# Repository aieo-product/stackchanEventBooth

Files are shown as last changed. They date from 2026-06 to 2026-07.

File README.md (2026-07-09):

# stackchanEventBooth

**AI Dev Day 2026（2026年7月24日・大手町プレイスホール＆カンファレンス）** のスタックチャンブース企画・運営リポジトリ。

イベントを盛り上げるための **スタックチャン用アクセサリー** と **簡易撮影ブース** を制作し、来場者に「スタックチャンを着せ替えて撮って楽しむ」体験を提供します。

📄 **公開提案サイト（Cloudflare Pages）: https://stackchan-event-booth.pages.dev/**
🎤 LTスライド（リッチHTML）: https://stackchan-event-booth.pages.dev/slides/lt.html

## このリポジトリの目的

- ブース企画（アクセサリー／撮影ブース／必要スペース）の管理
- アクセサリー造形例の調査と、各制作者への **許諾取得状況** の管理
- 関係者向け公開提案サイト（Cloudflare Pages）のソース管理

## ブース概要（想定）

| 項目 | 内容 |
|---|---|
| イベント | AI Dev Day 2026 |
| 日時 | 2026年7月24日（金）|
| ブース運営時間 | **13:00–17:00**（4時間想定）|
| 会場 | 大手町プレイスホール＆カンファレンス（東京・大手町）|
| 体験 | スタックチャンの着せ替えアクセサリー展示＋記念撮影ブース |

## ディレクトリ構成

| パス | 内容 |
|---|---|
| `baseIdea/` | 元ネタ画像（スタックチャンお誕生日会で見たアクセサリー・撮影ブース例）|
| `research/` | X調査結果（アクセサリー造形例・制作者アカウント・許諾管理）|
| `docs/` | 関係者シェア用 提案サイト（VitePress / Cloudflare Pages）|

## 関連リンク

- 📄 公開提案サイト（Cloudflare Pages）: https://stackchan-event-booth.pages.dev/
- 🎤 LTスライド（リッチHTML）: https://stackchan-event-booth.pages.dev/slides/lt.html
- AI Dev Day 2026: https://aidevday.com/
- ハッシュタグ: `#ｽﾀｯｸﾁｬﾝお誕生日2026`

## アクセサリーの取り扱い方針

本ブースで展示・配布・印刷するアクセサリーは **既存造形のコピーではなく、各制作者に許諾を得たうえで設置** します。調査した造形例と制作者アカウントは [`research/accessories.md`](research/accessories.md) で管理し、許諾ステータスを記録します。

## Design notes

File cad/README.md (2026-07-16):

# CAD (OpenSCAD) — 卓上観覧車 & 撮影ブース

Issue #16/#18/#19 の3Dプリントパーツをパラメトリックに定義したOpenSCADソースです。
寸法・公差は [`params.scad`](params.scad) に一元化しています。設計根拠は
[`docs/ferris-wheel.md`](../docs/ferris-wheel.md) / [`docs/photobooth.md`](../docs/photobooth.md)。

## 生成方法

```bash
cd cad
make all      # 全STLを ../print/files/{ferris,booth,mini}/ に生成
make check    # 生成 + BBox寸法チェック + 接地(最下面z=0)チェック (python3, 標準ライブラリのみ)
make clean    # 生成STLを削除
```

STL は `print/files/` 配下（`.gitignore` 管理外）に出力されます。**ソースが正**で、
STL はコミットしません。`openscad` CLI が必要です（`/opt/homebrew/bin/openscad`, v2026 で検証）。

## パラメータ変更 → 再生成

1. [`params.scad`](params.scad) の該当変数を編集（例: 印刷公差 `tol`、ダブテール
   クリアランス `tol_dovetail`、LED溝幅 `led_groove_w` など）。
2. `make clean && make all` で全パーツを再生成（`make check` で寸法再確認）。
3. テスト印刷（7/15〜）のはめ合いフィードバックは、まず `tol` / `tol_dovetail` /
   `tol_snap` の3変数で調整します（初版は安全側=緩めに設定済み）。

`tower.scad`（`part="upper"|"lower"`）と `wall_panel.scad`
（`variant="blackboard"|"window"|"board"`）は `-D` で切り替え、Makefile が各STLに展開します。

## パーツ一覧

| STL | ソース | 実測BBox (X×Y×Z mm) | 主要寸法 / 備考 |
|---|---|---|---|
| ferris/rim-segment | `ferris/rim_segment.scad` | 158×150×20 | 1/4円弧・Ø300・スポーク2本一体・外周LED溝10.5×2.0・端部ダブテール＋接線M3ボス（X の +8 はテノン） |
| ferris/diffuser | `ferris/diffuser.scad` | 152×152×23.2 | リム外周に被せるコの字スナップカバー・1/4円弧（半透明フィラメント推奨） |
| ferris/hub | `ferris/hub.scad` | 80×80×25 | Ø80×25・シャフト穴Ø8.2貫通・スポークボルト穴8・M3イモネジ用インサート横穴2 |
| ferris/gondola | `ferris/gondola.scad` | 68×72×77 | **チェア型オープンゴンドラ(#18再設計)**。座面2段ネスト凹み(外62×62×1.5=汎用/ゲルテープ・内48.6×56.6×2.0=K151ベース48×56嵌合)・左右ハンガーポスト・背もたれ低壁25・前面Dセーフティバー・上部ブリッジのU溝で吊り軸を掴む(振り子安定)。前面開放でスクリーン可視・サポートレス |
| ferris/tower-upper | `ferris/tower.scad -D part="upper"` | 86.6×30×145 | A型上半・608ポケットØ22.2×7.2＋抜け止めリップ・スプライスソケット |
| ferris/tower-lower | `ferris/tower.scad -D part="lower"` | 122×30×168 | A型下半・ベース差込タブ＋M3蝶ネジ穴・角ダボ(male)＋M3×2 |
| ferris/base | `ferris/base.scad` | 250×183×45 | 250×175×15・長辺に自己相補ダブテール（同一部品を180°回転で連結）・支柱スロット2・M3蝶ネジ・クランク軸受Ø8.5 |
| ferris/crank | `ferris/crank.scad` | 152.5×25.5×44 | クランク本体(Ø8.2＋M3イモネジ)＋自由回転グリップØ20×40(Eリング溝)＋フリクションダンパーC形クリップ（1プレート） |
| ferris/axle | `ferris/axle.scad` | 90×40×139 | **Φ6印刷吊り軸(#20)**。一体フランジ頭Ø10×3＋Φ6シャフト、押込キャップØ10×6(内穴Φ5.8=0.2締め代)。金属棒不要(カット機材不要)。1プレートに軸5本＋キャップ6個(予備込) |
| booth/floor-tile | `booth/floor_tile.scad` | 158×158×3 | 150×150×t3・木目板目0.6mm浮彫・裏ダブテール(+X/+Yオス, -X/-Yメス)（XY の +8 はテノン） |
| booth/wall-blackboard | `wall_panel.scad -D variant="blackboard"` | 150×137×5 | 150×125×t5・中央浅凹(緑紙貼付)・下端スタンドタブ（Y の +12 はタブ） |
| booth/wall-window | `wall_panel.scad -D variant="window"` | 150×137×5 | 2×2窓開口＋裏面レベット（空画像紙用） |
| booth/wall-board | `wall_panel.scad -D variant="board"` | 150×137×6.5 | コルク風枠＋ピン穴グリッド5×5 |
| booth/stand-clips | `booth/stand_clips.scad` | 100×81.6×80 | 壁差込チャンネルスタンド(100×80×t8)＋連結クリップ＋定位置マーカーØ24（1プレート） |
| mini/mini-adapter-atomcat | `mini/adapter_gondola.scad -D variant="atomcat"` | 45.2×57.2×17 | **ミニ観覧車アダプタ(#19)**。Artec木製キット055521の木製ゴンドラ差替バケット。内底42×42・背面ペグ(アームリング穴挿込)。寸法はプレースホルダ(要ノギス実測) |
| mini/mini-adapter-minimal | `mini/adapter_gondola.scad -D variant="minimal"` | 49.2×61.2×17 | 同上・ミニマル機用 内底46×46 |

BBox はすべて 250mm 以内（X2Dビルドプレート内）。全パーツ manifold（`make check` および
独立エッジ検査で確認済み）。`make check` の**接地チェック**で全パーツの最下面が z=0（±0.01）
にあることを検証（浮遊初層＝#18スパゲッティ化の根本原因を防止）。

## 設計上の判断（設計書からの補足）

- **リム/床タイルの BBox が設計値+8mm**: 連結用ダブテールのテノンが張り出すため。本体寸法は
  リム外周半径150（Y軸）、タイル本体150×150。`check_dims.py` はテノンのない軸/厚みで検証。
- **吊りフックは水平穴でなく上開きU溝**: サポートレスで印刷でき、Ø3軸を落とし込む「フック式」
  （現地1分・工具不要）に合致（受入条件4）。
- **支柱スプライス**: 「重なり代」は角ダボ(8mm角)＋M3×2の勘合で確保し、分割位置 z=135 で
  両半とも 170mm 以下（下168 / 上145）に収めた。
- **ベース連結**: 2枚を別部品にせず、連結辺に自己相補ダブテール（テノン@+50 / モルタイス@-50）を
  配置。同一STLを2枚印刷し、片方を連結辺中点まわりに180°回転すると勘合する。
- **クランク軸受(ベース)**: 主軸クランクは支柱上端の608ベアリング（軸高280mm）に直結する運用が
  基本。ベースの軸受ブラケット(Ø8.5)は軸端のガイド/低位ジャックシャフト用オプション。
- **ディフューザー**: `rotate_extrude` 由来で OpenSCAD 上は PolySet 表示だが、閉じた多面体
  （エッジ検査で watertight 確認済み）。

### #18 テスト印刷失敗の修正
- **接地化**: rim_segment のスポーク梁・接合ボス・ダブテールが z=4 に浮いていた（初層が空中
  スタート→糸くず化）ため、全て z=0 起点・バンド全高(0..20mm)化。ディフューザーと支柱上下も
  印刷姿勢で最下面を z=0 に配置。`check_dims.py` に接地チェックを追加し全パーツ PASS。
- **ゴンドラ全面再設計**: 箱型(内寸75角で実機がほぼ隠れる)→チェア型オープンゴンドラ。K151実寸
  (base 48×56, 全体54×70.5×61.5, 187.2g)に合わせ2段ネスト凹みで位置決め。吊り軸(z70)を
  搭載重心(≈z38)より十分上に置き、振り子として安定。前面はバーのみでスクリーンが正面から見える。
- **前面バー**は Dセクション(底面フラット)で 60mm ブリッジをサポートレス印刷。

### #20 印刷吊り軸への変更
- ゴンドラ吊り軸を金属Φ3棒→**Φ6印刷軸**に変更（ユーザーにカット機材が無いため）。E-ring不要・押込キャップで抜け止め。発注済みΦ3棒/Eリングは他用途に流用。
- 追随して params: `gon_axle_hole_d` 3.2→**6.4**(リム穴)、`gon_hook_d` 3.4→**6.5**(J溝)、`gon_axle_d=6.0` 新設。
- 曲げ検討(Φ6 PLA・スパン80・荷重3N): 応力 ≈2.8MPa(降伏50MPa→FoS≈18)・たわみ ≈0.14mm。印刷軸で十分（詳細 axle.scad コメント）。
- **リム間隙間を 80→90mm に修正**: 隙間はゴンドラ幅(74)ではなく**奥行(gon_floor_y=84、軸方向)**をクリアする必要があるため（旧コメントの誤りを是正）。

### 吊り下げ回転テストリグ（`make swing-test`）
金属シャフト(7/18着)・608ベアリング(7/20-22着)の到着前に、「ダミーシャフト→ミニリム→印刷軸→ゴンドラ吊り下げ→回転時も水平維持」を検証する卓上リグ（`ferris/swing_test_rig.scad`、PART変数で個別出力、工具不要の差込式）。
- `rig-disc`×2: Ø100×t6、中心D穴(Φ8.2)でダミーシャフトと共回り、r40にゴンドラ軸穴Φ6.4(本番同径)、肉抜き穴6。
- `rig-shaft`×1: Φ8 D断面(寝かせ印刷)・L132。両端はスタンドのすべり軸受(Φ8.6)で回す(ベアリング不要)。
- `rig-stand`×2: A型・軸受高さ126・上端Φ8.6のU溝(上から落とし込み＋浅い抜け止めリップ)・足タブ。高さ148(≤150)。
- `rig-base`×1: 150×80×t6、スタンド差込スロット4。
- 既存の `axle`(印刷軸)・`gondola` をそのまま使用(穴径は本番同一)。
- **印刷時間概算**(PLA 0.2mm/15%): disc×2≈1.6h・shaft≈0.5h・stand×2≈1.4h・base≈0.9h = **新規リグ計 ≈4.4h**(5h以内)。全パーツ接地・サポートレス。`make check` は `swing-test` も生成して検証。

### 組立ビューア用モデル（`make viewer-models`）
- `ferris/assembly.scad` が全パーツを組立座標系（原点=ベース底面中心・軸=Z高さ273でY方向）に配置。`PART="<name>"` で単一グループ出力、`PART="all"` で全体。
- `make viewer-models` が **$fn=40 の軽量バイナリSTL**を `docs/public/models/ferris/` に書き出す（14ファイル・各≤375KB）。three.jsビューア用。
- `docs/public/models/ferris/manifest.json`（id/file/日本語名/color/explode方向/group）を同梱。

### #19 ミニ観覧車アダプタ
- Artec 木製キット 055521 の木製ゴンドラと差し替えるバケット。`variant` で atomcat(内底42角)/
  minimal(内底46角)を切替。背面ペグでアームリング外周穴に挿込（キット非改造・原状復帰可）。
- **タブ幅×厚×長・穴ピッチ・ホイール径・座席突起はプレースホルダ**（`params.scad` の `mini_*`）。
  ノギス実測後に数値差し替えで再生成（パラメトリック）。前面ガードは軽量機のため低め。

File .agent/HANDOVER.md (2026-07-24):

# HANDOVER — stackchanEventBooth

> 最終更新: 2026-07-23 昼 (JST) / 更新セッション: フォトウォール・LED・LT会ジオラマ・v6量産・未着対応
> **イベントは明日 7/24(金)13:00-17:00。今日はオフィス残り〜10hで印刷を全消化する日**

## ゴール
- AI Dev Day 2026(大手町プレイス1F)のスタックチャンブース。🎡手回し観覧車(実機搭乗)＋🎤LT会ジオラマ撮影ブース＋📺フォトウォール＋15分LT

## 今いちばん大事な状態 🔥
- **印刷分担(7/23午後確定)**: 応援=リム4＋**支柱上下各1＋base-mini×2**(足元パッド化で1枚1h・ジャーナル廃止・/dl/wheel-kit-20260723.zip v3・明朝神田受渡)。自宅=リム残→hub×2→crank(v2鋼棒ハンドル・最後)。**ブースは床タイル全廃→スタンド自立のハリボテ壁構成に変更し、壁+スタンドをブース応援者へ委譲**(/dl/booth-walls-kit-20260723.zip)。**608ベアリング不使用で確定**(支柱Φ9穴が滑り軸受・千石リストの608は購入不要に)
- **昨夜のプレート(ゴンドラv6×4＋支柱4点＋crank＋Φ2.9かまぼこ)の完了確認がまだ会話に出ていない** — 失敗していたら最優先で再印刷
- **7/13 Amazon便は7/27着に遅延=イベントに間に合わない** → 全代替を千石で現物調達: `research/akiba-backup-20260722.md`(LED配線含む・約¥6,200・商品コード確認済み)。**買い出しは本日中必須**(千石19時まで)
- **Φ2.9セルフタップは7/23午後に実ネジで実証済み**(IMG_9508/9509: スポークパッド2枚をM3でハブ片に固定・しっかり噛合)。hub×2はこのまま本番使用可。これで観覧車の全接合部が検証完了

## 観覧車(v6・8b25bc4まで)
- 駆動: 8mm鉄シャフト→ハブΦ8.2(イモネジM3×2/Φ2.9直タップ)→支柱上端支柱Φ9穴の直軸受(608不使用で確定・Φ22.2ポケットは空きでOK)→クランク。ゴンドラ吊りΦ6印刷軸+キャップ(検証済)
- v6: pivot100(装飾ロボ頭上33mm)・支柱300mm・ゴンドラ88×74×107.4。v5でシャフト/着座/吊り/水平は実機合格済み
- **スポーク⇔ハブ**: パッドΦ3.4素通し+ハブΦ2.9タップ×8穴、M3×8。**リム継手**: ダブテール+M3×8(タップ側Φ2.9)。**白リム1号のみ旧Φ4.0→M4×8**
- リム応援印刷4個(配布URL: /dl/rim-segment-v20260722.stl・最新Φ2.9版と同一ハッシュ確認済み)

## LED(実装完了・配線材のみ未調達)
- AtomS3R + `firmware/led_rainbow/led_rainbow.ino` 書込済: SK6812 60LED×2本をGrove G2(前リム)/G1(後リム)、画面ボタンで50/25/100%/OFF、900mAキャップ
- 配線: Grove切断ケーブル→WAGO分岐→SMメスピグテール(千石CAB-14575)→テープ**Din側**(矢印始点)。7/22の不点灯はDOUT側接続+仮結線が原因
- 電源: ATOMICバッテリーベース(A151)×3差し替え・稼働1h以内なら容量OK。ベースUSB-Cにモバブ挿しで延命可

## LT会ジオラマ(7/23設計完了・印刷待ち)
- **7/23夕変更: 床なし・stand_clipsスタンド自立式(ハリボテ)**。旧床ソケット案は記録。スクリーンはL/R分割→半厚ダブテール連結で300mm幅、**紙288×117(A4横)が2枚跨ぎで上から差さる**。窓壁(左)・通常壁(右)・演台(ロゴ紙43×25)・ステージ台
- 印刷紙: **https://stackchan-event-booth.pages.dev/dl/lt-paper-a4.pdf**(GPT-image-2生成・公式ルックのスタックチャン+AIDevDayロゴ+スタックチャンLT会！バナー・トンボ付き)。等倍印刷→カット
- 3Dビューア: /viewer-booth/(組立確認用・分解ビュー可)

## 📺フォトウォール(運用のみ残)
- /photowall/ 1枚10秒スライドショー・60秒毎posts.json再取得・Fで全画面。7/21実Xポストでリハ成功済(Chrome拡張+Xログイン要)
- 更新手順=`scripts/photowall/README.md`(スクレイピングはmedia ID形式でDLP回避)。除外=ban.json

## スライド(7/23昼 再構成デプロイ済み・25枚)
- 実体: `docs/public/slides/lt.html`(生HTML・ビルドで dist へコピー)。本番 /slides/lt.html
- 7/23再構成: ①歴史に「5歳お誕生日会」「OpenAI公式CM登場(@OpenAIDevs Build Week動画)」追加 / ②を新フロー化: 2.5mmケーブル入手難(6月出荷分から同梱)→MeloTTS挫折→Kokoroチューニング→フィラー0ms→最新音声ルート全体図SVG→Gemma4司令官(9〜27秒→1〜2秒)→AIEO構想(aieo-robot.pages.dev)→Utaさんへバトン。素材元=baseIdea/stackChan/(未コミット・slides/assetsに変換済コピーをコミット)
- **#22ゲストスライド**: 7/24朝に素材(PlaiPin/Natalie Yeoさん PDF)到着→ユーザー指示で誕生日会スライド直後(6P)にフルスライド挿入・デプロイ済み(assets/plaipin-guest.jpg)
- **markdown-it罠**(docsのみ): `**…（…）**`+CJK隣接→`<b>`使用。lt.htmlは生HTMLなので無関係

## 定型作業
- ビルド: `export PATH="$HOME/.nvm/versions/node/v24.14.1/bin:$PATH"` → `cd docs && npm run build`
- デプロイ: `export CLOUDFLARE_API_TOKEN=$(security find-generic-password -s CLOUDFLARE_API_TOKEN -w); export CLOUDFLARE_ACCOUNT_ID=$(security find-generic-password -s CLOUDFLARE_ACCOUNT_ID -w); npx wrangler@latest pages deploy .vitepress/dist --project-name=stackchan-event-booth --commit-dirty=true`(要sandbox解除・自動デプロイ運用実績あり)
- CAD: `cad/params.scad`が唯一の正→`make -C cad all`/`check`/`viewer-models`/`viewer-models-booth`/`joint-check`。スライサー: `open -a BambuStudio <stl>`
- git: main直コミット。動画解析はffmpegフレーム抽出

## 参照
| 項目 | 値 |
|---|---|
| 本番 | https://stackchan-event-booth.pages.dev/ ｜ /viewer/ ｜ /viewer-booth/ ｜ /photowall/ ｜ /slides/lt.html |
| 買い物 | research/akiba-backup-20260722.md(千石・今日必須) / 100均=research/hyakkin-props-20260716.md |
| K151実寸 | 54×70.5×61.5・187.2g / ベース48×56×11.1 / cad/vendor/k151 |

## 申し送り
- 印刷は立ち会い運用。0.6ノズル化は却下済み(公差が0.4基準)。高速化はブース系のみ0.28/8%可・観覧車系は実績設定厳守
- ディフューザー(PETG)は正式断念。テスト記録=baseIdea/観覧車/testresult/(個人情報スクショはコミット除外)
- 秘密情報はKeychain参照のみ(-a付けない)

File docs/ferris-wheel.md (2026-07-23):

# 🎡 スタックチャン観覧車（手回し回転・虹色LED）

スタックチャン（実機）が乗った観覧車を**来場者がクランクで回し**、リムが**虹色に光る**卓上観覧車を3Dプリントで製作します。撮影ブース（学校ジオラマ）と並べて、「スタックチャンが現実世界で生活してる」世界観の目玉展示にします。

::: info 2026-07-15 決定: 手回し版を採用
Amazon実売調査でモーター系5点が¥7,131（閾値¥6,000超）だったため、**電動をやめ手回しクランク版に決定**。追加発注は3点・約¥6,200に半減し、「来場者が回す」参加型の体験になります。電動版の検討記録は[比較表](#⚖️-電動-vs-手回し-モーター価格で選択)に残しています。
:::

::: tip このページの目的
1. **観覧車の寸法・分割プリント・組立方式**を確定する（設計）
2. **電装パーツ（モーター・LED・電源）のBOM**と**フィラメント必要量**を出して発注できる状態にする
3. X2D 1台・立ち会い運用で **7/23までに印刷が終わるスケジュール** を確定する
:::

## 🕹️ 組立シミュレーター（3Dビューア）

<a href="/viewer/" target="_blank" style="display:inline-block;background:#4da3ff;color:#08101d;font-weight:700;padding:10px 18px;border-radius:10px;text-decoration:none;">▶ ブラウザで3D組立シミュレーターを開く</a>

実際の印刷用CADと同一データを組立位置に配置したインタラクティブビューアです。**パーツごとの表示ON/OFF・透明度・分解ビュー・透視モード（内部構造）**で、どのパーツがどこに付くかを確認できます（パーツ名クリックで単独表示）。

## 完成予想図

<div style="display:flex;justify-content:center;margin:16px 0;">
  スタックチャン観覧車の完成予想CG（虹色LEDリム・パステルゴンドラにスタックチャンが搭乗）
</div>

> AI生成の完成イメージ（2026-07-15・**手回しクランク版**）。実設計はゴンドラ**4基**・リムØ300・接地350×250（下記仕様）。雰囲気・配色（白リム＋半透明ディフューザー＋パステルゴンドラ＋グレー支柱＋クランクハンドル）の共有用。

## 着想元

居酒屋で実際に見かけた**木製ドリンク観覧車**（回転する吊りトレイにグラスを載せる什器）。M5Stackデバイスを載せると「スタックチャンが観覧車に乗っている」画になることを確認済みで、これを電動・LED付きの3Dプリント版として再構成します。

<div style="display:grid;grid-template-columns:repeat(auto-fit,minmax(280px,1fr));gap:12px;margin:16px 0;">
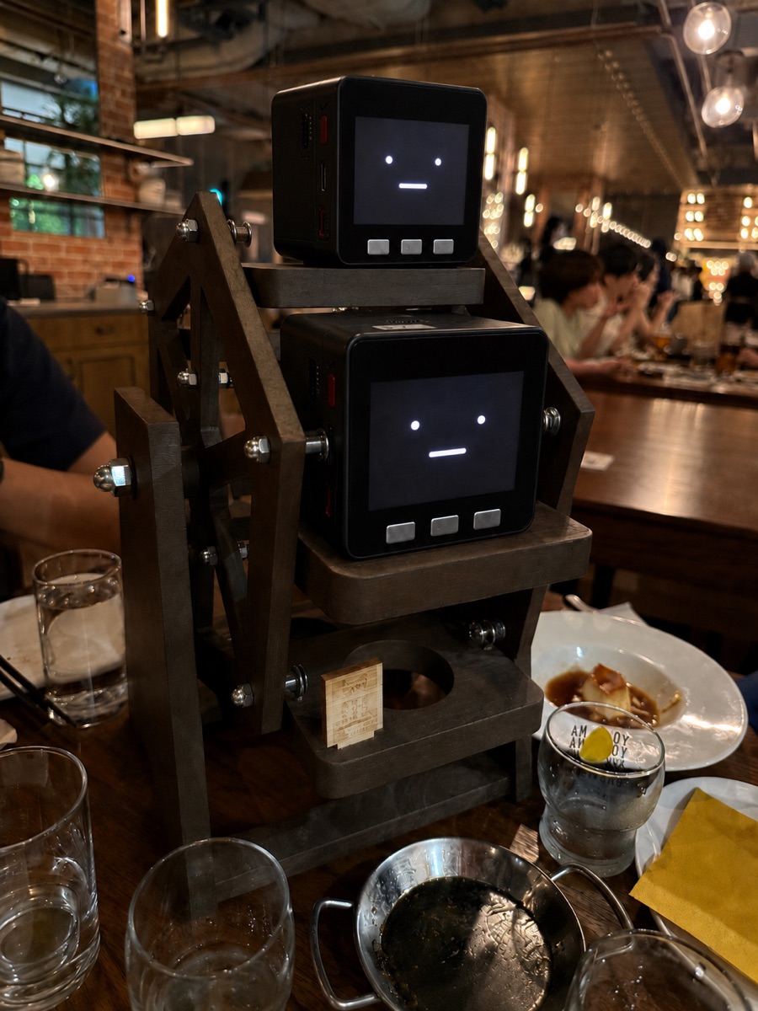
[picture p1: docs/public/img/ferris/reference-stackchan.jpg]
ドリンク観覧車に乗ったM5Stackデバイス（着想元）
  
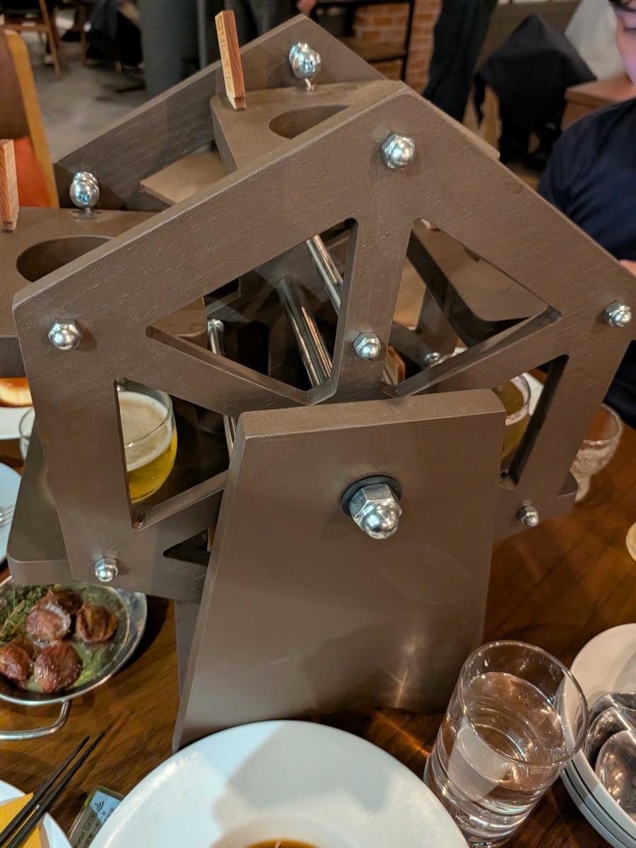
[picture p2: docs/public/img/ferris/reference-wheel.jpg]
木製ドリンク観覧車の構造（ボルト接合・吊りトレイ）
  
</div>

> 撮影: 本企画メンバー。構造面でも「多角形プレート2枚＋ボルト接合＋自由回転の吊りトレイ」という本設計と同型で、**ゴンドラは深いバケットではなく吊りトレイ＋前面ガード**でも成立することの実物証明になっている。

## 全体仕様

| 項目 | 仕様 | 備考 |
|---|---|---|
| リム直径 | **Ø300mm** | 卓上でテーブル中央ゾーン（W450）に収まる |
| 全高 | 約450mm | 軸高さ約280mm＋リム上端 |
| 接地サイズ | 約350×250mm | ベースプレート（2分割） |
| ゴンドラ | **4基**（内寸 75×75×85mm） | スタックチャン実機（約54×54×65mm・約150g）が1体ずつ搭乗。自由回転（スイング）式 |
| 回転 | **手回しクランク**（来場者が回す参加型） | ゆっくり回す運用（スタッフ誘導）。1周目安5〜10秒 |
| 駆動 | クランクハンドル直結（3Dプリント製・M3イモネジでシャフト固定） | フリクションダンパー（印刷パーツ・任意）で回しすぎ/惰性回転を抑制 |
| LED | WS2812B（アドレサブル） | リムに沿って虹色レインボーアニメーション |
| 本体重量 | 印刷部品 約1.1kg ＋ 搭乗実機 最大600g | |

### 搭乗対象と安全設計

- ゴンドラはスタックチャン実機（M5Stack Core系）1体分。**底面すべり止め＋前面ガード**付きで、走行サーボが動いても落下しない深さ（85mm）を確保。
- クランク直結で動力源がなく、**手を離せば止まる**。フリクションダンパー（印刷パーツ）で惰性回転・急回転を抑制し、回す速さはスタッフが声かけで誘導。
- ゴンドラと支柱のクリアランスは**15mm以上**を確保し、体験時はスタッフが常駐。

## 構造・分割プリント設計

X2Dのビルドプレートに収まるよう、**全パーツを最大250mm以下**に分割します。接合はダブテール＋M3ネジ（<b>Φ2.9下穴への直接セルフタップ</b>・7/22にインサート未着対応で全穴変更済み #18）で、**分解・再組立可能**（搬入出は分解状態、現地組立5〜10分）。

```
        ┌─ リム（Ø300・前後2枚）… 1/4円弧×4 ×2枚 = 8ピース
        │   └ スポーク一体成形。外周に半透明LEDディフューザー溝
        ├─ ハブ×2 … 8mmシャフトにM3イモネジ×2で固定
        ├─ ゴンドラ×4 … Φ6 3Dプリント軸で前後リム間に吊り下げ
        ├─ 支柱（A型）×2 … 上下2分割（H170×2）。上端に608ZZベアリング
        ├─ ベース … 2分割（175×250×2）。クランク軸受付き
        └─ 駆動 … クランクハンドル → 8mmシャフト →ハブ→ リム回転
```

| パーツ | 個数 | 1個のサイズ | 単重(g) | 印刷時間/個 | 推奨色 |
|---|--:|---|--:|--:|---|
| リム1/4円弧（スポーク一体） | 8 | 約230×95×20 | 50 | 2.2h | アイボリーホワイト |
| LEDディフューザー（円弧カバー） | 8 | 約230×20×12 | 12 | 0.6h | **PETG半透明クリア**（無色・LED発色優先／7/17購入） |
| ハブ（シャフトフランジ） | 2 | Ø80×25 | 30 | 1.5h | アッシュグレー |
| ゴンドラ | 4 | 85×85×110 | 40 | 1.8h | パステル各色（ピンク/黄/青/白・手持ち。※グラディエント綿菓子の雲は売切のため変更） |
| 支柱（上下分割） | 4 | 約170×120×30 | 55 | 2.2h | アッシュグレー |
| ベースプレート | 2 | 250×175×15 | 90 | 3.0h | アッシュグレー |
| モーターマウント・小物類 | 一式 | — | 60 | 2.5h | アッシュグレー |
| **合計** | | | **約1,176g** | **約50h** | |

> 失敗・試作マージン+25%で **実質 約1.47kg**。印刷時間はPLA 0.2mm・インフィル15%の概算（スライス後に更新）。

### 接合方式（現地組立対応）

| 接合部 | 方式 | 現地作業 |
|---|---|---|
| リム円弧同士 | ダブテール＋M3×8（Φ2.9下穴セルフタップ。<b>印刷済みリム1号の旧Φ4.0穴のみM4×8で代替</b>） | **事前組立**（円盤2枚は組んだまま運搬可・Ø300） |
| 前後リム間（ゴンドラ軸） | **Φ6 3Dプリント軸**を貫通・フランジ頭＋押込キャップで抜け止め（金属棒・カット不要） | 事前組立 |
| 支柱 上下 | 角ダボ＋M3×12 ×2本 | 現地（2分）|
| 支柱⇔ベース | 差し込み＋M3蝶ネジ | 現地（2分）|
| ベース2分割 | ダブテール＋M3蝶ネジ | 現地（1分）|
| ホイール⇔支柱 | シャフトをベアリングに通し、両側のハブ・クランクのM3イモネジで軸方向固定（Eリング不要） | 現地（2分）|
| ゴンドラ | 閉じた丸穴＋Φ6印刷軸を貫通（J溝フック廃止・確実性優先） | 事前組立（搭乗時は軸を抜いて出し入れ）|

**現地組立の合計は約8分**（1時間シフト交代の設営5〜10分要件内）。工具はプラスドライバー1本と蝶ネジ（手回し）のみ。

## 電装設計

### 駆動系（手回しクランク）

```
クランクハンドル（3Dプリント・グリップ付き） → 8mmシャフトにM3イモネジ固定 → ハブ → ホイール回転
※ フリクションダンパー（印刷パーツ・任意）をシャフトに添えて回転を減衰
```

> ベースのモーターマウント部は**クランク軸受に差し替え**（印刷量は同等）。電源・配線が不要になり、現地組立がさらに簡単になります。

### LED系（虹色イルミネーション）

回転するリムへの給電は**スリップリングを使わず**、ハブ中央に小型モバイルバッテリー＋M5 Atom Liteを<b>同乗（一緒に回転）</b>させて解決します。配線のねじれが発生せず、手持ちのM5デバイスを活用できます。

```
[回転部] モバイルバッテリー(5V) → M5 AtomS3R → SK6812テープ×2（前後リム外周）
[固定部]（フォールバック/追加）USB電源 → AtomS3R → ベース・支柱のLED
```

- レインボーアニメーションは AtomS3R の FastLED/M5Unified スケッチで実装済み（[`firmware/led_rainbow/led_rainbow.ino`](https://github.com/aieo-product/stackchanEventBooth/blob/main/firmware/led_rainbow/led_rainbow.ino)・画面ボタンで輝度4段切替・900mA電力キャップ）。
- バッテリーはハブ中心に置くため回転トルクへの影響は最小。10000mAh級で4時間運用は余裕（LED 2m・輝度50%で約1A）。
- **フォールバック**: 回転部LEDが間に合わない場合は、支柱・ベースなど固定部のみのLED装飾に切り替え（バッテリー・配線不要でUSB給電）。

#### 配線（AtomS3R Grove → SMコネクタ・2026-07-23確定）

AtomS3Rには<b>何も加工しない</b>のがポイント。Groveケーブル1本を切断してバラ線化し、WAGOコネクタ4個でSMコネクタ付ケーブルのメス側と橋渡しする（はんだ不要）。部品はページ末尾の「🛒 最終購入リスト」参照。

<style>
.wiring-panel { background: var(--vp-c-bg-soft); border: 1px solid var(--vp-c-divider); border-radius: 10px; padding: 12px; overflow-x: auto; }
.wiring-panel svg { display: block; min-width: 700px; width: 100%; height: auto; }
.wiring-panel .wt { font-size: 12px; fill: var(--vp-c-text-1); }
.wiring-panel .ws { font-size: 10.5px; fill: var(--vp-c-text-2); }
</style>

<div class="wiring-panel">
<svg viewBox="0 0 860 560" role="img" aria-label="AtomS3RからLEDテープまでの配線図">
  <defs>
    <marker id="wire-arr" viewBox="0 0 8 8" refX="7" refY="4" markerWidth="7" markerHeight="7" orient="auto">
      <path d="M0 0 L8 4 L0 8 z" fill="var(--vp-c-text-2)"/>
    </marker>
  </defs>
  <rect x="18" y="200" width="104" height="104" rx="14" fill="#3a3f45" stroke="rgba(128,128,128,.6)"/>
  <rect x="32" y="214" width="76" height="58" rx="6" fill="#111318"/>
  <text x="70" y="247" text-anchor="middle" font-size="11" fill="#8be9a8">50%</text>
  <text x="70" y="292" text-anchor="middle" font-size="11" fill="#c8cdd3" font-weight="600">AtomS3R</text>
  <text x="70" y="190" text-anchor="middle" class="wt" font-weight="600">① 本体</text>
  <rect x="118" y="234" width="16" height="36" rx="3" fill="#e6e6e6" stroke="rgba(128,128,128,.6)"/>
  <text x="126" y="228" text-anchor="middle" class="ws">PORT.A</text>
  <text x="126" y="322" text-anchor="middle" class="ws">底面ヘッダはバッテリー</text>
  <text x="126" y="336" text-anchor="middle" class="ws">ベース用に空ける</text>
  <g fill="none" stroke-linecap="round">
    <path d="M134 240 H208" stroke="rgba(128,128,128,.6)" stroke-width="7"/><path d="M134 240 H208" stroke="#e03131" stroke-width="4.5"/>
    <path d="M134 248 H208" stroke="rgba(128,128,128,.6)" stroke-width="7"/><path d="M134 248 H208" stroke="#26292e" stroke-width="4.5"/>
    <path d="M134 256 H208" stroke="rgba(128,128,128,.6)" stroke-width="7"/><path d="M134 256 H208" stroke="#fafafa" stroke-width="4.5"/>
    <path d="M134 264 H208" stroke="rgba(128,128,128,.6)" stroke-width="7"/><path d="M134 264 H208" stroke="#f5c518" stroke-width="4.5"/>
  </g>
  <line x1="222" y1="218" x2="222" y2="288" stroke="#e8590c" stroke-width="2" stroke-dasharray="5 4"/>
  <text x="222" y="208" text-anchor="middle" font-size="11" fill="#e8590c" font-weight="700">✂ ② ここで切断</text>
  <text x="222" y="302" text-anchor="middle" class="ws">反対側の余りは予備に</text>
  <g fill="none" stroke-linecap="round">
    <path d="M236 240 C300 240 280 96 344 96" stroke="rgba(128,128,128,.6)" stroke-width="7"/><path d="M236 240 C300 240 280 96 344 96" stroke="#e03131" stroke-width="4.5"/>
    <path d="M236 248 C300 248 280 216 344 216" stroke="rgba(128,128,128,.6)" stroke-width="7"/><path d="M236 248 C300 248 280 216 344 216" stroke="#26292e" stroke-width="4.5"/>
    <path d="M236 256 C300 256 280 336 344 336" stroke="rgba(128,128,128,.6)" stroke-width="7"/><path d="M236 256 C300 256 280 336 344 336" stroke="#fafafa" stroke-width="4.5"/>
    <path d="M236 264 C300 264 280 456 344 456" stroke="rgba(128,128,128,.6)" stroke-width="7"/><path d="M236 264 C300 264 280 456 344 456" stroke="#f5c518" stroke-width="4.5"/>
  </g>
  <text x="290" y="130" class="ws" text-anchor="middle">赤 5V</text>
  <text x="290" y="238" class="ws" text-anchor="middle">黒 GND</text>
  <text x="290" y="320" class="ws" text-anchor="middle">白 G2</text>
  <text x="290" y="440" class="ws" text-anchor="middle">黄 G1</text>
  <text x="392" y="46" text-anchor="middle" class="wt" font-weight="600">③ WAGOで結線（4個）</text>
  <g>
    <rect x="344" y="72" width="96" height="48" rx="7" fill="var(--vp-c-bg)" stroke="rgba(128,128,128,.6)"/>
    <rect x="352" y="64" width="80" height="12" rx="3" fill="#e8590c"/>
    <text x="392" y="102" text-anchor="middle" font-size="11.5" class="wt" font-weight="600">WFR-3（3P）</text>
    <text x="452" y="70" class="ws">5V: 赤1本→赤2本</text>
  </g>
  <g>
    <rect x="344" y="192" width="96" height="48" rx="7" fill="var(--vp-c-bg)" stroke="rgba(128,128,128,.6)"/>
    <rect x="352" y="184" width="80" height="12" rx="3" fill="#e8590c"/>
    <text x="392" y="222" text-anchor="middle" font-size="11.5" class="wt" font-weight="600">WFR-3（3P）</text>
    <text x="452" y="190" class="ws">GND: 黒1本→黒2本</text>
  </g>
  <g>
    <rect x="344" y="312" width="96" height="48" rx="7" fill="var(--vp-c-bg)" stroke="rgba(128,128,128,.6)"/>
    <rect x="352" y="304" width="80" height="12" rx="3" fill="#e8590c"/>
    <text x="392" y="342" text-anchor="middle" font-size="11.5" class="wt" font-weight="600">WFR-2（2P）</text>
    <text x="452" y="310" class="ws">白G2 ↔ ①の緑</text>
  </g>
  <g>
    <rect x="344" y="432" width="96" height="48" rx="7" fill="var(--vp-c-bg)" stroke="rgba(128,128,128,.6)"/>
    <rect x="352" y="424" width="80" height="12" rx="3" fill="#e8590c"/>
    <text x="392" y="462" text-anchor="middle" font-size="11.5" class="wt" font-weight="600">WFR-2（2P）</text>
    <text x="452" y="430" class="ws">黄G1 ↔ ②の緑</text>
  </g>
  <g fill="none" stroke-linecap="round">
    <path d="M440 88 C500 88 480 108 540 108" stroke="rgba(128,128,128,.6)" stroke-width="7"/><path d="M440 88 C500 88 480 108 540 108" stroke="#e03131" stroke-width="4.5"/>
    <path d="M440 104 C520 104 460 388 540 388" stroke="rgba(128,128,128,.6)" stroke-width="7"/><path d="M440 104 C520 104 460 388 540 388" stroke="#e03131" stroke-width="4.5"/>
    <path d="M440 208 C500 208 480 140 540 140" stroke="rgba(128,128,128,.6)" stroke-width="7"/><path d="M440 208 C500 208 480 140 540 140" stroke="#26292e" stroke-width="4.5"/>
    <path d="M440 224 C520 224 460 420 540 420" stroke="rgba(128,128,128,.6)" stroke-width="7"/><path d="M440 224 C520 224 460 420 540 420" stroke="#26292e" stroke-width="4.5"/>
    <path d="M440 336 C510 336 470 124 540 124" stroke="rgba(128,128,128,.6)" stroke-width="7"/><path d="M440 336 C510 336 470 124 540 124" stroke="#2f9e44" stroke-width="4.5"/>
    <path d="M440 456 C500 456 480 404 540 404" stroke="rgba(128,128,128,.6)" stroke-width="7"/><path d="M440 456 C500 456 480 404 540 404" stroke="#2f9e44" stroke-width="4.5"/>
  </g>
  <text x="588" y="72" text-anchor="middle" class="wt" font-weight="600">④ SMメス側</text>
  <rect x="540" y="96" width="56" height="56" rx="7" fill="#f0efe9" stroke="rgba(128,128,128,.6)"/>
  <text x="568" y="128" text-anchor="middle" font-size="10.5" fill="#3d4148" font-weight="600">SMメス</text>
  <rect x="540" y="376" width="56" height="56" rx="7" fill="#f0efe9" stroke="rgba(128,128,128,.6)"/>
  <text x="568" y="408" text-anchor="middle" font-size="10.5" fill="#3d4148" font-weight="600">SMメス</text>
  <line x1="600" y1="124" x2="640" y2="124" stroke="var(--vp-c-text-2)" stroke-width="2" marker-end="url(#wire-arr)"/>
  <text x="620" y="112" text-anchor="middle" class="ws">挿す</text>
  <line x1="600" y1="404" x2="640" y2="404" stroke="var(--vp-c-text-2)" stroke-width="2" marker-end="url(#wire-arr)"/>
  <text x="620" y="392" text-anchor="middle" class="ws">挿す</text>
  <g>
    <rect x="644" y="94" width="196" height="60" rx="8" fill="var(--vp-c-bg)" stroke="rgba(128,128,128,.6)"/>
    <rect x="644" y="112" width="14" height="24" rx="3" fill="#f0efe9" stroke="rgba(128,128,128,.6)"/>
    <text x="700" y="118" font-size="11.5" class="wt" font-weight="700">Din ▶▶</text>
    <text x="668" y="140" font-size="11" class="wt">SK6812テープ① 前リム</text>
    <text x="828" y="118" text-anchor="end" font-size="11" fill="#e03131" font-weight="700">DO側 ✕</text>
    <text x="744" y="172" text-anchor="middle" class="ws">「Din」印字＋矢印の始点側に接続（⑤）</text>
  </g>
  <g>
    <rect x="644" y="374" width="196" height="60" rx="8" fill="var(--vp-c-bg)" stroke="rgba(128,128,128,.6)"/>
    <rect x="644" y="392" width="14" height="24" rx="3" fill="#f0efe9" stroke="rgba(128,128,128,.6)"/>
    <text x="700" y="398" font-size="11.5" class="wt" font-weight="700">Din ▶▶</text>
    <text x="668" y="420" font-size="11" class="wt">SK6812テープ② 後リム</text>
    <text x="828" y="398" text-anchor="end" font-size="11" fill="#e03131" font-weight="700">DO側 ✕</text>
    <text x="744" y="452" text-anchor="middle" class="ws">「Din」印字＋矢印の始点側に接続（⑤）</text>
  </g>
</svg>
</div>

| Grove側（切断した4線） | 結線コネクタ | SMピグテール側 | 行き先 |
|---|---|---|---|
| 赤（5V） | WAGO WFR-3 | ①の赤＋②の赤 | 両テープの5V |
| 黒（GND） | WAGO WFR-3 | ①の黒＋②の黒 | 両テープのGND |
| 白（G2） | WAGO WFR-2 | ①の緑 | 前リムテープのDin |
| 黄（G1） | WAGO WFR-2 | ②の緑 | 後リムテープのDin |

::: warning 7/22に光らなかった原因と対策
- <b>DO側（終点側）に挿していた</b> — 信号は矢印の向きにしか流れない。必ず「Din」印字＋矢印の始点側へ
- コネクタ無しの仮結線で接触不良 — WAGOはレバーを上げ→被覆を約11mm剥いた線を差し→レバーを倒す。結線後に軽く引いて抜けを確認
- ピグテールの線色が違うロットあり — 色より<b>SMコネクタのピン位置</b>（テープ側の5V/Din/GND印字と対応）を最終確認
:::

### パーツリスト（BOM・2026-07-15 実売調査済み：Amazonリンク付き）

7/13のAmazon注文（工具・締結・配線材）は<b>7/27着に遅延</b>（7/22判明・イベント7/24に間に合わない）。締結系は<b>CADをΦ2.9セルフタップ化してインサート不要に</b>し（8b25bc4）、ベアリング・ネジ類は<b>7/23に千石電商 秋葉原本店で現物調達</b>する（下の「🛒 7/23 千石買い出しリスト」参照）。

| # | 品目 | 採用候補（実売） | 状態 | 実売(税込) | 購入リンク |
|--:|---|---|---|--:|---|
| 1 | ~~ウォームギヤードモーター~~ | JGY-370 12V 3rpm（[dp/B01HGCSBDM](https://www.amazon.co.jp/dp/B01HGCSBDM)） | ✖ 不採用（電動版用・参考） | (¥2,429) | — |
| 2 | ~~ACアダプタ 12V 2A~~ | Broadwatch（[dp/B00AJDAPM6](https://www.amazon.co.jp/dp/B00AJDAPM6)） | ✖ 不採用（電動版用・参考） | (¥1,380) | — |
| 3 | ~~PWM速度コントローラ~~ | beyourchoi 6個（[dp/B0CX55SRYM](https://www.amazon.co.jp/dp/B0CX55SRYM)） | ✖ 不採用（電動版用・参考） | (¥749) | — |
| 4 | ~~スイッチ＋DCジャック~~ | LIANHATA＋Youmile | ✖ 不採用（電動版用・参考） | (¥1,574) | — |
| 5 | ベアリング 608（内径8mm） | ミネベア 608ZZ ×3（支柱2＋予備1） | 🏪 <b>7/23 千石3階で購入</b>（Amazon便は7/27着遅延） | ¥663 | [EEHD-4JWX](https://www.sengoku.co.jp/mod/sgk_cart/detail.php?code=EEHD-4JWX) |
| 6 | シャフト Φ8mm | uxcell リニアシャフト 8×250mm **2本**（★4.2/50件） | 🛒 共通 | ¥1,180 | [dp/B08XYM78XJ](https://www.amazon.co.jp/dp/B08XYM78XJ) |
| 7 | ~~シャフトカプラ 6→8mm~~ | Saipor 5個（[dp/B07ZMYSYLH](https://www.amazon.co.jp/dp/B07ZMYSYLH)） | ✖ 不採用（電動版用・参考） | (¥999) | — |
| 8 | LEDテープ（アドレサブル） | **秋月 SK6812 1m/60LED ×2本**（WS2812B互換・両端SMコネクタ付き＝切断/はんだ不要・着脱式） | 🏪 **秋月店頭で購入（7/16予定）** | ¥3,880 | [秋月 112982](https://akizukidenshi.com/catalog/g/g112982/) |
| 9 | LEDコントローラ | M5 Atom Lite | ✅ 手持ち | — | — |
| 10 | モバイルバッテリー | 小型 5V/2A（ハブ同乗用） | ✅ 手持ち | — | — |
| 11 | ネジ類 | ~~M3ヒートインサート~~（Φ2.9セルフタップ化で<b>不要</b>）／M3なべ×8・×12／M3イモネジ／M3蝶ボルト／M4×8 | 🏪 <b>7/23 千石2階で購入</b>（Amazon便は7/27着遅延） | 約¥2,500 | 下の買い出しリスト参照 |
| 12 | ゴンドラ軸 | ~~Φ3丸棒＋Eリング~~ → **Φ6 3Dプリント軸×4＋キャップ**（2026-07-16 設計変更: カット機材不要のため。曲げ応力≈2.8MPa・安全率18倍） | 🖨️ 印刷（購入不要） | — | — |
| 13 | 配線・工具 | 3ピンコネクタ・ジャンパー・熱収縮・はんだ・ニッパー・サーボテスター | 🚚 7/27着（遅延）— <b>観覧車は手回し駆動のため当日必須ではない</b>。熱収縮のみ必要なら秋月で代替 | — | — |
| 14 | クランクハンドル・軸受・ダンパー | 3Dプリント（本設計） | 🖨️ 印刷（購入不要） | — | — |
| | | | **追加調達合計（手回し版）** | **約¥6,700**（Amazon ¥2,819＋秋月 ¥3,880） | |

### 🛒 7/23 千石買い出しリスト（機構部品）

> LED配線材を含む<b>全品の確定版はページ末尾の「🛒 最終購入リスト」</b>を参照。

7/13 Amazon注文の未着（7/27着に遅延）を受けた現物調達リスト。<b>必須分は千石電商 秋葉原本店1軒で完結</b>します（外神田1-8-6 丸和ビル・11:00〜19:00・03-3253-4411）。商品リンク・在庫拠点は2026-07-23の通販サイト表示（在庫拠点=秋葉原を確認済み。店頭数は非公開のため電話確認が確実）。

| 売場 | 品目 | 数量 | 用途 | 価格 | 商品リンク |
|---|---|---|---|--:|---|
| 3階 メカトロ | ミネベア 608ZZ ベアリング | 3個（支柱2＋予備1） | 支柱上端の軸受（Φ22.2ポケット） | ¥663 | [EEHD-4JWX](https://www.sengoku.co.jp/mod/sgk_cart/detail.php?code=EEHD-4JWX) |
| 2階 ネジ | 鉄ナベ小ネジ M3×8（50本入） | 1袋 | リム継手8箇所×2本＋スポーク⇔ハブ8穴×2枚＝32本＋予備。Φ2.9下穴に直接セルフタップ | ¥650 | [EEHD-6MP4](https://www.sengoku.co.jp/mod/sgk_cart/detail.php?code=EEHD-6MP4) |
| 2階 ネジ | 鉄ナベ小ネジ M3×12（50本入） | 1袋 | 支柱上下連結2本×2＋イモネジ穴の事前タップ立て用＋予備 | ¥650 | [EEHD-6MP6](https://www.sengoku.co.jp/mod/sgk_cart/detail.php?code=EEHD-6MP6) |
| 2階 ネジ | 鉄イモネジ（ホーロー）M3×8 | 10個（使用6＋予備） | ハブ×2枚の各2本＋クランク2本のシャフト固定。<b>締結に六角レンチ1.5mmが必要</b> | ¥550 | [EEHD-6GTT](https://www.sengoku.co.jp/mod/sgk_cart/detail.php?code=EEHD-6GTT) |
| 2階 ネジ | 鉄蝶ボルト M3×12 | 6個 | 支柱⇔ベース×2・ベース2分割連結（手回し・工具レス） | ¥450 | [EEHD-6GGM](https://www.sengoku.co.jp/mod/sgk_cart/detail.php?code=EEHD-6GGM) |
| 2階 ネジ | 鉄蝶ボルト M3×8 | 4個 | 上記の長さ現物合わせ用サブ | ¥300 | [EEHD-6GGK](https://www.sengoku.co.jp/mod/sgk_cart/detail.php?code=EEHD-6GGK) |
| 2階 ネジ | M4×8 ネジ（セムス/トラス等どれでも可） | 4本 | <b>印刷済みリム1号の旧Φ4.0継手穴の代替のみ</b>（8b25bc4のコメント参照） | 〜¥200 | [EEHD-6FGL](https://www.sengoku.co.jp/mod/sgk_cart/detail.php?code=EEHD-6FGL) |
| 工具売場 | 六角レンチ 1.5mm（手持ちなければ） | 1本 | イモネジ用。<b>これが無いとシャフト固定不可</b> | 〜¥300 | 店頭選定 |
| （任意）2階 | 平ワッシャーM3 少量 | — | 蝶ボルト座面のPLA保護 | 〜¥100 | 店頭バラ |

- <b>合計目安: 約¥3,700</b>（任意含む）
- 買わなくてよくなったもの: ~~M3ヒートインサート~~（Φ2.9セルフタップ化）・~~EW3 Eリング~~（ゴンドラ軸の印刷軸化＋ハブ/クランクのイモネジ軸方向固定で不要）
- 任意・別店: 熱収縮チューブは並びの[秋月電子](https://akizukidenshi.com/catalog/c/cheatshri/)（平日11:30〜18:30）。サーボテスターは駅反対側のスーパーラジコン（11:00〜21:00・03-5688-1414）だが観覧車には不要
- 調査ログ: [research/akiba-backup-20260722.md](https://github.com/aieo-product/stackchanEventBooth/blob/main/research/akiba-backup-20260722.md)

::: tip 調達状況（2026-07-15 確定・履歴）
- **Amazon発注（¥1,180）**: 8mmシャフト2本（**7/18着**・ホイール主軸・L250でカット不要）のみ。~~Eリング・Φ3丸棒~~ は印刷軸化（2026-07-16）により購入不要に
- **秋月店頭（7/16買い出し予定）**: SK6812テープLED 1m×2本（¥3,880・[販売コード112982](https://akizukidenshi.com/catalog/g/g112982/)・通販在庫410本）
  - 1mずつ前後リムに1本ずつ貼るだけ（切断・はんだ不要）。両端SMコネクタで着脱式＝現地分解の設計方針と好相性
  - 千石電商（徒歩圏）に寄るなら: EW3 Eリング（本店2階）・608ZZ（本店3階）が7/13注文分の遅延時保険
- シャフトは7/18着だが、軸組みは7/22の本組立のため**スケジュール影響なし**
:::

::: warning 実売調査での判明事項（2026-07-15）
- **モーター系5点（#1〜4・7）の実売合計は¥7,131**で切替閾値（¥6,000）を超過 → **手回し版に決定（2026-07-15）**。#1〜4・7は発注しない。
- 実売が概算より高いのは**多くがセット販売**のため（PWM6個・ジャック10個・カプラ5個・シャフト2本・丸棒10本・LED5m）。余剰は予備・他プロジェクトに回せます。
- **Φ8mm Dカット付きシャフトは在庫なし** → 丸棒で代替し、**ハブ固定はDカット依存をやめてM3イモネジ×2（手持ちインサート活用）に設計変更**。
- LEDテープはIP30・2m品の完全一致がなく、ALITOVE 5m IP20（非防水・ほぼ同等）を採用。カプラはフレキ型の高トルク強度に注意（本用途は低トルクのため許容、必要ならリジッド型へ）。
- **納期は全品「明日7/16着」**を確認済み。7/17着目標より前倒しで揃います。
:::

### 🏪 調達先の比較（Amazon通販 × 秋葉原店頭・2026-07-15調査）

オフィス（神田）から秋葉原の実店舗に行ける前提で、**秋月電子通商・千石電商の通販サイト在庫**も調査済み（[調査詳細](https://github.com/aieo-product/stackchanEventBooth/blob/main/research/amazon-parts-20260715.md)）。両店は徒歩圏内なので1回の外出で回れます。

| パーツ | 🚚 Amazon（明日7/16着） | 🏪 秋葉原店頭（当日入手） |
|---|---|---|
| ① 8mmシャフト | ✅ uxcell 2本 ¥1,180（[dp/B08XYM78XJ](https://www.amazon.co.jp/dp/B08XYM78XJ)） | ❌ 金属シャフトは秋月・千石とも**取扱なし**。千石に[アクリル8φ×30cm ¥330](https://www.sengoku.co.jp/mod/sgk_cart/detail.php?code=6B4T-TDEN)（本店2階）があるが樹脂のため軸荷重・耐久は要検証 |
| ② アドレサブルLEDテープ 2m | ALITOVE WS2812B 5m ¥3,369（[dp/B01N7BX973](https://www.amazon.co.jp/dp/B01N7BX973)・切断/はんだ処理が必要） | ✅ **【採用】秋月 SK6812テープLED 1m/60LED ¥1,940×2本=¥3,880**（[112982](https://akizukidenshi.com/catalog/g/g112982/)・WS2812B互換・両端SMコネクタ付き・在庫410本）。千石はアドレサブル品の取扱なし |
| ③ Φ3mm丸棒＋Eリング | ✅ 丸棒10本 ¥1,050＋Eリング120個 ¥589（[dp/B0FCZP736S](https://www.amazon.co.jp/dp/B0FCZP736S) / [dp/B08HN2CCDZ](https://www.amazon.co.jp/dp/B08HN2CCDZ)） | 丸棒❌（金属3mmは両店なし）／ Eリングのみ✅ [千石 EW3 100個¥580](https://www.sengoku.co.jp/mod/sgk_cart/detail.php?code=EEHD-6GJZ)（本店2階） |
| （予備）608ベアリング | 7/13注文済（7/20〜22着） | ✅ [千石 ミネベア608ZZ ¥221/個](https://www.sengoku.co.jp/mod/sgk_cart/detail.php?code=EEHD-4JWX)（本店3階）— 着荷遅延時のバックアップに |

**確定プラン（2026-07-15）**: **金属丸棒2種（①③）＋EリングはAmazonで発注**（計¥2,819・シャフトのみ7/18着、他は7/16着）。**LEDは秋月店頭でSK6812×2本を購入（7/16買い出し）** — 1mずつ前後リムに貼るだけで切断・はんだ不要、SMコネクタで着脱式のため。千石のEリング・608ZZは7/13注文分の着荷遅延時の保険。※店頭在庫数はサイト非公開のため、来店前の電話確認が確実。

### ⚖️ 電動 vs 手回し（モーター価格で選択）

モーター・電源系の実売価格が想定より高い場合は、**モーターをドロップして手回しクランク版**に切り替えられる設計にします（ホイール・支柱・ベース・LEDは共通、モーターマウント部だけクランク軸受に差し替え）。

| 比較項目 | 🔌 電動版（本命） | 🖐️ 手回し版（コストダウン） |
|---|---|---|
| 回転 | ウォームギヤモーターで**自動**（1〜2rpm連続） | 印刷製クランクハンドルを**来場者が回す** |
| 追加発注費（**実売**・2026-07-15調査） | **約¥13,300** | **約¥6,200**（モーター系5点 ¥7,131 をドロップ） |
| 追加発注の内訳 | モーター系5点（¥7,131）＋シャフト・LED | シャフト¥1,180＋秋月LED¥3,880 のみ（ゴンドラ軸は印刷化で¥0） |
| LED（虹色） | ハブ同乗バッテリー＋Atom Lite | **同じ構成でそのまま使用可**（回転と独立） |
| 体験の質 | 常時回転で展示映え・無人でも絵になる | 来場者参加型（「回してみて」の体験化）。無人時は静止 |
| 安全 | セルフロックで電源OFF即停止 | クランク直結・低速。回しすぎ防止のフリクションダンパー（印刷パーツ）を任意追加 |
| 印刷の変更 | — | モーターマウント → クランク軸受＋ハンドル（同等の印刷量） |

**決定（2026-07-15）**: モーター系5点の実売合計が**¥7,131で閾値¥6,000を超過**したため、**手回し版を採用**。「来場者がクランクを回す」参加型体験として運用し、電源・配線レスで現地組立もさらに簡単になる。本表は検討記録として残置。

## フィラメント必要量（追加分）

| 区分 | 量 |
|---|--:|
| 観覧車 印刷部品合計 | 約1,176g |
| 失敗・試作マージン +25% | +294g |
| **観覧車 追加消費** | **約1.47kg** |

既存計画（アクセサリー等 約1.2〜1.3kg、[プリント環境](/printing)）＋観覧車約1.47kg＋撮影ブース約0.7kg（[撮影ブース](/photobooth)）＝ **合計約3.4〜3.5kg**。購入済みの**6色×1kg＝6kg以内に収まります**（追加購入不要）。

## 印刷スケジュール（X2D 1台・立ち会い運用・観覧車＋撮影ブース＋アクセサリー統合）

::: warning 前提
無人運転は禁止（[print/README](https://github.com/aieo-product/stackchanEventBooth/blob/main/print/README.md)）のため、1日の印刷枠を<b>最大12h（立ち会い可能時間）</b>として計画。総印刷時間 約50h（観覧車）＋約25h（撮影ブース）＋約20h（アクセサリー優先分）≒ **95h** を **9日間・計108h枠**（≦12h/日）に配分します。7/15のテスト印刷分（リム1・ゴンドラ1・床タイル1）は本番部品として使用します。
:::

| 日付 | 印刷内容 | 目安時間 | 並行作業 |
|---|---|--:|---|
| 7/15(火) | **テスト印刷**（リム円弧1・ゴンドラ1※手持ちパステルで公差確認・床タイル1） | 5.0h | CAD完了（PR #17マージ済） |
| 7/16(水) | 観覧車 リム円弧×4＋ハブ×2 | 11.8h | 秋葉原買い出し（秋月SK6812×2）／Amazon着荷（Eリング・丸棒） |
| 7/17(木) | 観覧車 リム円弧×3＋支柱×2 | 11.0h | フィラメント7本 発注済み（7/16・PLAウッド/PETGクリア等）の着荷待ち |
| 7/18(金) | 観覧車 支柱×2＋ベース×2 | 10.4h | シャフト着荷／**プランB切替判断**（CADは完了済のため原則プランA続行） |
| 7/19(土) | クランク一式＋**ゴンドラ×3（手持ちパステル）**＋ディフューザー×4（PETGクリア・要乾燥） → **LED点灯テスト＋仮合わせ** | 10.3h | フィラメント着荷確認・LEDテスト |
| 7/20(日) | ディフューザー×4＋撮影ブース 床タイル×7＋壁パネル×4 | 11.8h | ジオラマ装飾素材の画像作成・印刷／7/13注文分の着荷確認 |
| 7/21(月) | 撮影ブース 壁パネル×4＋スタンド類＋MakerWorld小物4点 | 11.9h | 100均で装飾調達／インサート圧入開始（着荷次第） |
| 7/22(火) | アクセサリー優先分（帽子・ヘッドホン・猫耳・キーホルダー） | 12.0h | **観覧車 本組立・回転/LEDテスト**（ベアリング組込み） |
| 7/23(水) | 予備日（失敗リテイク・配布品追加） → **全体組立リハーサル・梱包** | 6.0h | 最終確認 |

> フィラメント7本は7/16発注（グラディエント綿菓子の雲は売切→ゴンドラは手持ちパステル4色に変更）。PETGクリアは7/18〜19着見込みのためディフューザーを7/19以降に配置。PETGは印刷前に乾燥させること。

**時間が足りない場合の縮退順**: ① 配布用キーホルダーの個数削減 → ② 撮影ブース壁パネルを8→4枚（背面中央のみ） → ③ 観覧車ゴンドラ4→2基。観覧車本体の中止は最終手段。

## 現地組立手順（当日・約8分）

1. ベース2分割を連結し、テーブル中央ゾーンに設置（1分）
2. 支柱を上下連結し、ベースに差し込んで蝶ネジ固定（2分×2本＝並行可）
3. ホイール（事前組立済みの円盤＋シャフト・ゴンドラ4基は吊り済み）を支柱のベアリングに載せる（2分）
4. クランクハンドルをシャフト端にイモネジ固定 — ハブとクランクで軸方向も固定される（2分）
5. ハブのバッテリーをONにしてLED点灯・手回しでの回転を確認（1分）

## MakerWorld既存モデルの流用可否（2026-07-15 調査済み）

MakerWorldの既存観覧車を調査した結果（8件・詳細は [Issue #12](https://github.com/aieo-product/stackchanEventBooth/issues/12)）、**実機（6cm角・150g）が搭乗できる強度・サイズの既製品は無く、新規設計（本ページのプランA）を本命**とします。ただし有力な既製品が2つあり、フォールバックとして活用します。

| 候補 | ライセンス | 印刷時間 | 評価 |
|---|---|--:|---|
| [espRyk 電動観覧車（N20モーター+USB5V）](https://makerworld.com/ja/models/911733) | MW標準 | 16.6h | 完成度最高・コミュニティ活発。ただし推定Ø205でゴンドラ寸法非公開 → **実機は乗れない前提**。ミニスタックチャン（キーホルダー配布品）なら搭乗可の見込み |
| [jj0815 シルバニアファミリー版](https://makerworld.com/ja/models/2503805) | MW限定 | 11.5h | シルバニア人形（高さ6〜7cm）向け＝**スケール適合は最良**。ただし手動回転・軽量人形前提で150gの実機はヒンジ強度が不足の見込み |
| [GUYI DESIGN 電動発光観覧車](https://makerworld.com/ja/models/1625080) | MW標準 | 52h | 電動+LEDで理想像に近いが、印刷52h・半田付け必須・モーター情報不足 → **期間内製作は不可** |

**プランB（フォールバック）**: 新規設計のCAD/印刷が7/19の仮組立に間に合わない場合、espRyk電動版（16.6h・Print Profile付きでそのまま印刷可）に**ミニスタックチャン（配布用キーホルダー）を搭乗**させる構成へ切替。虹色LEDは固定部（支柱・ベース）装飾として本設計の電装をそのまま使う。切替判断は**7/18時点のCAD進捗**で行う。

> 経費は [経費まとめ](/expenses) に反映済み。印刷ジョブは [`print/print-list.yaml`](https://github.com/aieo-product/stackchanEventBooth/blob/main/print/print-list.yaml) の `ferris-*` を参照（STL確定後に有効化）。

## 🛒 最終購入リスト（2026-07-23 最小構成に確定）

<b>7/23 昼の強度見直しで最小構成に絞り込み</b>: フィットテストで嵌合がきつめ＝摩擦固定が効くこと、手回し低速で軸受精度が不要なことから、<b>締結は「リムを繋ぐM3ネジ」だけ</b>に削減。買い出しは千石電商 秋葉原本店1軒（外神田1-8-6・11:00〜19:00・03-3253-4411）。

### 買うもの（最小構成・約¥2,200）

| ✔ | 売場 | 品目 | 数量 | 価格 | 商品リンク | 用途 |
|---|---|---|---|--:|---|---|
| ☐ | 2階 ネジ | 鉄ナベ小ネジ M3×8（50本入） | 1袋 | ¥650 | [EEHD-6MP4](https://www.sengoku.co.jp/mod/sgk_cart/detail.php?code=EEHD-6MP4) | <b>唯一の必須締結</b>。リム継手16本＋スポーク⇔ハブ16本＋予備（Φ2.9下穴セルフタップ） |
| ☐ | 2階 ネジ | M4×8 ネジ（セムス/トラス等可） | 4本 | 〜¥200 | [EEHD-6FGL](https://www.sengoku.co.jp/mod/sgk_cart/detail.php?code=EEHD-6FGL) | 印刷済みリム1号の旧Φ4.0穴のみ（リム1号を使わないなら不要） |
| ☐ | 1階 14番07列 | JST SM状コネクタ付ケーブル 3P オスメスセット（CAB-14575） | 2セット | ¥700 | [EEHD-57YB](https://www.sengoku.co.jp/mod/sgk_cart/detail.php?code=EEHD-57YB) | LED用。<b>メス側</b>をテープDin端（オス）に挿す×2（余裕あれば予備+1） |
| ☐ | 地下1階 | WAGO WFR-3 ワンタッチコネクター 3P | 2個 | ¥378 | [EEHD-4YR3](https://www.sengoku.co.jp/mod/sgk_cart/detail.php?code=EEHD-4YR3) | LED用。5V分岐・GND分岐（¥189/個） |
| ☐ | 地下1階 | WAGO WFR-2 ワンタッチコネクター 2P | 2個 | ¥274 | [EEHD-4YMP](https://www.sengoku.co.jp/mod/sgk_cart/detail.php?code=EEHD-4YMP) | LED用。信号線 白G2↔①Din・黄G1↔②Din（¥137/個） |

### 買わない（省略の根拠・2026-07-23 強度見直し）

| 品目 | 店頭で買うなら | 省略できる理由 | 滑った/緩んだ時のリカバリ |
|---|---|---|---|
| ~~608ZZベアリング~~ | [EEHD-4JWX](https://www.sengoku.co.jp/mod/sgk_cart/detail.php?code=EEHD-4JWX)（3階・¥221/個） | 支柱のシャフト貫通穴は<b>Φ9.0</b>（CAD実測）— Φ8シャフトが直接乗る。ガタ約0.5mm・手回し低速では体感差なし | 現物合わせで気になればポケットに608を後日装着（7/27 Amazon便に同梱） |
| ~~M3イモネジ＋六角レンチ~~ | [EEHD-6GTT](https://www.sengoku.co.jp/mod/sgk_cart/detail.php?code=EEHD-6GTT)（2階・¥55/個） | クランク・ハブとも圧入がきつく摩擦固定で足りる（フィットテスト実測） | ハブ/クランクの<b>Φ2.9横穴にM3ネジを直接ねじ込む</b>（同じ50本袋で対応・頭は出るが機能する） |
| ~~M3蝶ボルト~~ | [M3×12: EEHD-6GGM](https://www.sengoku.co.jp/mod/sgk_cart/detail.php?code=EEHD-6GGM)／[M3×8: EEHD-6GGK](https://www.sengoku.co.jp/mod/sgk_cart/detail.php?code=EEHD-6GGK)（2階・¥75/個） | 支柱・ベースは差し込みだけで自立安定 | 運搬時にガタつくならテープ養生で十分 |
| ~~M3×12~~ | [EEHD-6MP6](https://www.sengoku.co.jp/mod/sgk_cart/detail.php?code=EEHD-6MP6)（2階・50本¥650） | 支柱上下は角ダボ＋自重（圧縮方向）で保持 | 抜け方向が心配ならM3×8を短掛け |
| ~~六角レンチ1.5mm・平ワッシャー~~ | 工具売場・2階バラ | イモネジ・蝶ボルト省略に伴い不要 | — |

### 任意・別店

| 品目 | 店 | 備考 |
|---|---|---|
| 熱収縮チューブ | [秋月電子](https://akizukidenshi.com/catalog/c/cheatshri/)（千石の並び・平日11:30〜18:30） | LED配線の被覆保護。WAGO結線なら無くても可 |
| ビニールテープ | 100均/コンビニ | 絶縁・結線補強 |

### LED結線メモ（購入後の作業）

- Grove側は手持ちのGrove一体型ケーブル1本を切断して片側バラ線化（購入不要）。接続図は `firmware/led_rainbow/led_rainbow.ino` 冒頭コメント参照
- 結線: 赤↔赤（5V）／黒↔黒（GND）／白G2↔テープ①緑Din／黄G1↔テープ②緑Din。<b>テープは`Din`印字＋矢印始点側</b>に接続（`DO`側は光らない — 7/22の不点灯原因）
- ファーム書込み済み（AtomS3R・画面ボタンで輝度4段切替・900mA上限）。バッテリーはATOMICバッテリーベース×3を差し替え運用

> 調達の経緯・帰宅後の組立順は [research/akiba-backup-20260722.md](https://github.com/aieo-product/stackchanEventBooth/blob/main/research/akiba-backup-20260722.md) を参照。

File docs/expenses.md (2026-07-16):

# 経費まとめ

このブースで **計上する経費** をまとめます。3Dプリンター（**Bambu Lab X2D**）は**保有済み**のため計上対象外で、計上は**フィラメント代＋観覧車の追加パーツ代**です。数量根拠は [造形プリント環境と必要量](/printing)・[観覧車](/ferris-wheel) を参照。

::: tip 経理へ渡すときのポイント
- **Bambu Lab X2D 本体は保有済み**のため、今回の経費には**含めません**（新規購入なし）。
- 計上するのは**フィラメント代**と**観覧車の追加パーツ代**。いずれも勘定科目は **消耗品費**、当期経費に計上できます。
- 用途は「**AI Dev Day 2026 スタックチャンブース**（2026-07-24）」に紐付き。領収書はこのイベント名で保管。
:::

## 計上する経費

2026-07-06 に Bambu Lab公式ストア（4周年記念セール中）と主要ECサイトの**在庫・価格を実際に確認**し、以下のとおり更新しました。パステル系の人気色（桜ピンク・レモンイエロー等）はBambuでセール中に売り切れていたため、2色は他社（eSUN）の1.75mm PLAで代替し、新たに**透明（フロスト）PLAを1色追加**しています。詳細な在庫状況・購入リンクは [造形プリント環境と必要量 > フィラメント購入リスト](/printing#フィラメント購入リスト-在庫確認済み) を参照。

| 区分 | 品目 | 数量 | 単価(税込) | 金額 | 経費区分 | 用途 |
|---|---|--:|--:|--:|---|---|
| 消耗品 | Bambu PLA マット アイボリーホワイト（白） | 1 | ¥1,820（35%OFF） | ¥1,820 | 消耗品費 | アクセサリー造形材料（[必要量](/printing)）|
| 消耗品 | Bambu PLA マット マリンブルー（青） | 1 | ¥1,820（35%OFF） | ¥1,820 | 消耗品費 | 同上 |
| 消耗品 | Bambu PLA マット アッシュグレー（グレー） | 1 | ¥1,820（35%OFF） | ¥1,820 | 消耗品費 | 同上 |
| 消耗品 | Bambu PLA 半透明 ライトジェイド（透明） | 1 | ¥3,042（35%OFF） | ¥3,042 | 消耗品費 | 同上（透明アクセント、新規追加）|
| 消耗品 | eSUN マットPLA ピーチピンク（ピンク・他社代替品） | 1 | ¥2,299 | ¥2,299 | 消耗品費 | 同上（Bambu桜ピンクが売切のため代替）|
| 消耗品 | eSUN マットPLA アーモンドイエロー（黄・他社代替品） | 1 | ¥2,299 | ¥2,299 | 消耗品費 | 同上（Bambuレモンイエローが売切のため代替）|
| | | | | **合計 ¥13,100** | | |

::: info 金額の内訳・更新（2026-07-06 在庫確認済み）
- 実質必要量は約 **1.2〜1.3kg** ですが、色バリエーション（透明を含む6色）と在庫確保のため **6色×1kg＝6kg** を購入する前提です。余りは次回以降に使用できます。
- Bambu分（白・青・グレー・透明の4点）はBambu Labストアの4周年記念セールで**4点以上同時購入35%OFF**が適用された価格。他社分（ピンク・黄）はセール対象外の通常価格です。
- 合計¥13,100は、旧プラン（4色×¥3,500＝¥14,000）より**総額が下がり、色数（透明含め6色）は増えています**（Bambuセール活用＋他社パステルPLAが比較的安価なため）。
- 単色運用にする／手持ち在庫を使う場合は本数を減らして調整してください。
- Bambuの4周年セールは**7/7まで**（なくなり次第終了）。実発注時は価格・在庫を [フィラメント購入リスト](/printing#フィラメント購入リスト-在庫確認済み) のリンク先で再確認してください。
:::

## 観覧車 追加パーツ（2026-07-15 確定：手回し版）

[観覧車（手回し・虹色LED）](/ferris-wheel) の製作決定に伴う追加パーツです。実売調査でモーター系が閾値を超えたため**電動をやめ手回しクランク版に決定**（クランクは3Dプリント・購入不要）。7/13のAmazon注文（ベアリング・インサート・ネジ類・配線材、レシート別管理）でカバーできる分を除き、**追加発注は以下の3点のみ**です（購入リンクは観覧車ページ参照）。

| 区分 | 品目 | 数量 | 実売(税込) | 調達 | 経費区分 |
|---|---|--:|--:|---|---|
| 消耗品 | 8mmリニアシャフト 250mm（2本入り） | 1 | ¥1,180 | Amazon（7/18着） | 消耗品費 |
| 消耗品 | SK6812テープLED 1m/60LED（WS2812B互換・コネクタ付き） | 2 | ¥3,880 | **秋月電子 店頭**（7/16買い出し） | 消耗品費 |
| | | | **小計 約¥5,060** | | |

> 実売はセット販売（丸棒10本等）のため単品概算より増。余剰は予備・次回流用。LEDはAmazonの5m品（¥3,369）より¥511高いが、1m×2本・コネクタ付きで切断/はんだ不要のため秋月品を採用。M5 Atom Lite・モバイルバッテリーは手持ち、608ベアリング・M3インサート/ネジ類・コネクタ/配線材は7/13注文分を使用（本表に含めない）。フィラメントは購入済み6kgの範囲内で追加購入なし。

## フィラメント追加購入（2026-07-16 発注）

Bambu 4周年セール（4点以上35%OFF・〜7/20）で7本を追加購入しましたが、**イベント専用はPLAウッド1本のみ計上**とし、他（PETGクリア/グレー・マット白/黒/レモンイエロー・ABS白）は汎用在庫（他プロジェクト共用）のため本イベントの経費には含めません。

| 区分 | 品目 | 用途 | セール価格(税込) | 計上 |
|---|---|---|--:|:--:|
| 消耗品 | **PLA ウッド オーカーイエロー** | 📸 教室の床タイル・本棚・机まわり（木質感） | **¥3,042** | ✅ |
| — | PETG半透明クリア/グレー・PLAマット アイボリー/チャコール/レモンイエロー・ABSホワイト | 🎡ディフューザー等にも使うが汎用在庫扱い | （計¥13,260） | — |

> 当初予定していた「PLAグラディエント 綿菓子の雲」（ゴンドラ用）は**売切**のため、ゴンドラは手持ちパステル4色（ピンク/黄/青/白）に変更。

**経費合計: フィラメント ¥13,100 ＋ PLAウッド ¥3,042 ＋ 観覧車追加パーツ 約¥5,060 ＝ 約¥21,200**（ゴンドラ軸を印刷化しΦ3丸棒・Eリングを購入リストから削除・2026-07-16）

## 参考：別途発生しうる費用（今回は経費計上しない）

イベント運営で必要になり得る費用の目安です。**今回の経費計上には含めません**が、別途購入・立替が発生する場合の参考として残します。

| 品目 | 目安 | 備考 |
|---|--:|---|
| Bambu Lab X2D 本体 | ―（保有済み）| 新規購入なし・計上対象外 |
| 予備ノズル・ビルドプレート・糊等 | ¥3,000 | プリンター運用消耗品（必要時）|
| 撮影ブース装飾（紙プリント・100均装飾・LED照明）| 約¥3,300 | 2026-07-16 ダイソー等で実売確認済み（[リンク付きリスト](/photobooth#装飾リスト-画像プリント-100均・2026-07-16-実売調査済み)）。床・壁・小物は手持ちフィラメントで印刷 |
| 什器（テーブルクロス・スタンド・養生）・電源タップ | ¥7,000 | 会場什器・配線 |

> 本ページは概算の企画ドラフトです。実際に購入・立替が発生した分は、レシート単位で明細化のうえ経理の指示に従って計上してください。

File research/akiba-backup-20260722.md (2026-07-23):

# 7/13注文遅延（7/27着）の秋葉原代替調達プラン（2026-07-23 買い出し確定版）

- 背景: 7/13のAmazon注文（工具・締結・配線材、当初7/20〜22着）が**7/27着に遅延** → イベント7/24に間に合わないため千石で現物調達
- **7/22の設計変更で買うものが変わった**（[8b25bc4](https://github.com/aieo-product/stackchanEventBooth/commit/8b25bc4)）:
  - ~~M3ヒートインサート~~ → **不要**（全穴Φ2.9セルフタップ化）
  - ~~EW3 Eリング~~ → **不要**（ゴンドラ軸は印刷軸化済み・主軸はハブ/クランクのイモネジで軸方向固定）
  - 印刷済みリム1号の旧Φ4.0継手穴のみ **M4ネジで代替**
- 注意: **ネジの西川は2023年12月閉店済み**。ネジ在庫は千石 本店2階が引き継ぎ（[統廃合案内](https://www.sengoku.co.jp/consolidation.html)）
- 商品コード・在庫拠点（=秋葉原）は2026-07-23に通販サイトで確認済み。店頭数は非公開のため来店前の電話確認が確実（千石: 03-3253-4411）

## 買い物リスト・機構部品（7/23昼 強度見直しで最小構成に削減 — LED込み合計約¥2,200）

**7/23昼の見直し**: 嵌合がきつく摩擦固定で足りる＋手回し低速のため、**締結はリムを繋ぐM3ネジのみに削減**。

| ✔ | 売場 | 品目 | 数量 | 価格 | 商品リンク | 用途 |
|---|---|---|---|--:|---|---|
| ☐ | 2階 ネジ | 鉄ナベ小ネジ M3×8（50本入） | 1袋 | ¥650 | [EEHD-6MP4](https://www.sengoku.co.jp/mod/sgk_cart/detail.php?code=EEHD-6MP4) | **唯一の必須締結**。リム継手16＋スポーク⇔ハブ16＋予備 |
| ☐ | 2階 ネジ | M4×8 ネジ（セムス/トラス等可） | 4本 | 〜¥200 | [EEHD-6FGL](https://www.sengoku.co.jp/mod/sgk_cart/detail.php?code=EEHD-6FGL) | リム1号の旧Φ4.0穴のみ（リム1号を使わないなら不要） |

**省略**（理由と滑った時のリカバリ。買うことにした場合のリンク付き）:
- ~~608ZZ~~（[EEHD-4JWX](https://www.sengoku.co.jp/mod/sgk_cart/detail.php?code=EEHD-4JWX)・3階¥221/個）→ 支柱の貫通穴は**Φ9.0**でΦ8シャフトが直接乗る（ガタ0.5mm・手回しなら問題なし）
- ~~イモネジ＋六角レンチ~~（[EEHD-6GTT](https://www.sengoku.co.jp/mod/sgk_cart/detail.php?code=EEHD-6GTT)・2階¥55/個）→ クランク/ハブは圧入固定。滑ったらΦ2.9横穴に同じM3ネジをねじ込む
- ~~蝶ボルト~~（[M3×12: EEHD-6GGM](https://www.sengoku.co.jp/mod/sgk_cart/detail.php?code=EEHD-6GGM)／[M3×8: EEHD-6GGK](https://www.sengoku.co.jp/mod/sgk_cart/detail.php?code=EEHD-6GGK)・2階¥75/個）→ 差し込みだけで自立安定。~~M3×12~~（[EEHD-6MP6](https://www.sengoku.co.jp/mod/sgk_cart/detail.php?code=EEHD-6MP6)・50本¥650）→ 角ダボ＋自重で保持
- LED配線材（下記）は**2セット/2個/2個に削減**（予備なし運用）

## LED配線（リムSK6812×2本 ⇔ AtomS3R）— 2026-07-23追記・必須

テープ付属のSMコネクタの**相手側を持っていない**ため以下が必須（7/22夜に実機で光らないのを確認済み。原因=DOUT側接続＋コネクタ無しの仮結線）。
接続図は `firmware/led_rainbow/led_rainbow.ino` 冒頭コメント参照（Grove PORT.A: 赤5V/黒GND/白G2→前リムDin/黄G1→後リムDin）。

| ✔ | 店 | 品目 | 数量 | 価格 | 商品リンク | 用途 |
|---|---|---|---|--:|---|---|
| ☐ | 千石 1階14番07列 | JST SM状コネクタ付ケーブル 3P オスメスセット (CAB-14575) | 3セット | ¥1,050 | [EEHD-57YB](https://www.sengoku.co.jp/mod/sgk_cart/detail.php?code=EEHD-57YB) | **メス側**をテープDIN端(オス)に挿す×2＋予備1。オスは予備（¥350/セット・秋葉原在庫あり） |
| ☐ | 千石 地下1階 | WAGO WFR-3 ワンタッチコネクター 3P | 4個 | ¥756 | [EEHD-4YR3](https://www.sengoku.co.jp/mod/sgk_cart/detail.php?code=EEHD-4YR3) | 5V分岐(赤1→赤2)・GND分岐(黒1→黒2)の3線結線×2＋予備2（¥189/個） |
| ☐ | 千石 地下1階 | WAGO WFR-2 ワンタッチコネクター 2P | 4個 | ¥548 | [EEHD-4YMP](https://www.sengoku.co.jp/mod/sgk_cart/detail.php?code=EEHD-4YMP) | 信号線 白(G2)↔緑①・黄(G1)↔緑② の2線結線×2＋予備2（¥137/個） |
| ☐ | 100均/コンビニ | ビニールテープ | 1巻 | ¥110 | — | 絶縁・結線補強 |

- Grove側は**手持ちのGrove一体型ケーブル1本を切断**して片側バラ線化（購入不要）
- 結線: 赤↔赤(5V)/黒↔黒(GND)/白(G2)↔テープ①緑(Din)/黄(G1)↔テープ②緑(Din)。**テープは`Din`印字＋矢印始点側**に接続（`DO`側は不可）
- ファーム書込み済み（AtomS3R・画面ボタンで輝度4段切替・900mA上限）。バッテリーはATOMICバッテリーベース×3を差し替え運用

## 任意・別店

| 品目 | 店 | 備考 |
|---|---|---|
| 熱収縮チューブ | [秋月電子](https://akizukidenshi.com/catalog/c/cheatshri/)（千石の並び・平日11:30〜18:30） | LED配線の被覆保護。SMコネクタ接続なら無くても可 |
| サーボテスター | スーパーラジコン 東京秋葉原店（台東1-10-7・11:00〜21:00・03-5688-1414） | 観覧車は手回しのため**不要**。スタックチャン調整で欲しければ（例: [PROGBOX 6-in-1](https://super-rc.co.jp/rc/product/view?id=20655)） |

## 店舗情報

| 店 | 住所 | 営業時間 | 電話 |
|---|---|---|---|
| 千石電商 秋葉原本店 | 外神田1-8-6 丸和ビル | 11:00〜19:00 | 03-3253-4411 |
| 秋月電子通商 秋葉原店 | 外神田1-8-3（千石の並び） | 平日 11:30〜18:30 | 03-3251-1779 |
| スーパーラジコン 東京秋葉原店 | 台東1-10-7 ホーザンビル2・3F | 11:00〜21:00 | 03-5688-1414 |

## 帰宅後の作業順（参考）

1. M3×12ネジでイモネジ穴（Φ2.9）に事前タップを立てる（params.scad コメントの手順）
2. 608ZZを支柱ポケットに圧入 → シャフト通し確認
3. リム継手をM3×8で締結（リム1号のみM4×8）→ 本組立・回転テスト

## 7/27着荷後の扱い

- Amazon便到着後、店頭調達分は予備在庫化（ネジ・ベアリングは消耗しない資材のため無駄にならない）
- 拡大鏡はんだステーション・ブレッドボード・パンチルトブラケット・M2インサート・サンディングスティックは docs 上の使用予定なし → 7/27着で問題なし

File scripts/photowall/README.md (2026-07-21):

# フォトウォール更新手順（当日運用）

`https://stackchan-event-booth.pages.dev/photowall/` に X の
`#ｽﾀｯｸﾁｬﾝ写真館 #AIDevDay` 付き投稿写真をスライドショー表示する。
表示側は静的ページ + `posts.json`。更新は「Claude in Chrome でスクレイピング →
merge → deploy」を人手トリガー（or /loop）で回す。

## 表示側の仕様

- URL: `/photowall/`（プレビュー: `/photowall/?data=posts.sample.json`）
- 1画像 10 秒表示（複数画像ポストは 1 枚ずつ順に表示）・クロスフェード・ループ
- 画面下部にポスト本文＋表示名＋@アカウント名（ハッシュタグは青ハイライト）
- posts.json を 60 秒ごとに再取得 → デプロイすればリロード不要で反映
- `F` キー or ダブルクリックで全画面。`←`/`→` で手動送り
- 投稿 0 件のときは「投稿してね」誘導画面

## 更新手順（Claude が実行）

1. **スクレイピング（Claude in Chrome）**
   - タブを開く: `https://x.com/search?q=%23ｽﾀｯｸﾁｬﾝ写真館%20%23AIDevDay&src=typed_query&f=live`
     （`f=live`=最新タブ。X ログイン済みの Chrome 必須）
   - `javascript_tool` で `scripts/photowall/extract_tweets.js` の中身を実行 → JSON 配列が返る
     （画像はURLでなく `media:[{mid,fmt}]` 形式。URLのままだと拡張のDLPで
     `[BLOCKED: Cookie/query string data]` になるため — 2026-07-21リハーサルで確認済み）
   - 件数が多い日はスクロール（`computer` の scroll）→ 再実行を繰り返し、結果を連結
     （merge 側で id 重複排除されるので雑に連結してよい）
2. **マージ（画像DL + posts.json 更新）**
   - 取得 JSON をスクラッチパッドに保存して:
     ```bash
     python3 scripts/photowall/merge_posts.py /path/to/scraped.json
     ```
   - 画像は `docs/public/photowall/images/<tweetid>_<n>.jpg` に保存され、
     posts.json はローカルパス参照になる（会場で X が重くても表示は安定）
3. **デプロイ**（HANDOVER の定型作業と同じ）
   ```bash
   export PATH="$HOME/.nvm/versions/node/v24.14.1/bin:$PATH"
   cd docs && npm run build
   export CLOUDFLARE_API_TOKEN=$(security find-generic-password -s CLOUDFLARE_API_TOKEN -w)
   export CLOUDFLARE_ACCOUNT_ID=$(security find-generic-password -s CLOUDFLARE_ACCOUNT_ID -w)
   npx wrangler@latest pages deploy .vitepress/dist --project-name=stackchan-event-booth --commit-dirty=true
   ```

## 不適切投稿の除外

`docs/public/photowall/ban.json` にツイート id の配列を書いて merge を再実行:

```json
["1234567890123456789"]
```

既に posts.json に入っている分も除外される。緊急時は posts.json から該当エントリを
手で消して即デプロイでもよい。

## 当日のブース側操作

1. 表示用 PC のブラウザで `/photowall/` を開き `F` で全画面 — これだけ
2. 更新したくなったら Claude に「フォトウォール更新して」（この README の手順を実行）
   or `/loop 10m` で定期実行

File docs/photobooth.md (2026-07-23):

# 簡易撮影ブース（3Dプリント製・学校ジオラマ）

> 🆕 <b>2026-07-23 方針転換</b>: 当日は「オフィス風LT会場」ジオラマ構成で組みます。<b>床4枚（コーナーソケット×2＋ソケット×2）＋スクリーン壁L/R＋窓壁×2＋通常壁×2＋演台＋ステージ</b>、壁は床タイルに直差し込み・ブースパーツは0.6ノズル高速印刷。以下の学校ジオラマ記述は元計画の記録です。

<div style="display:flex;gap:12px;flex-wrap:wrap;margin:12px 0;">
  <a href="/viewer-booth/" target="_blank" style="display:inline-block;padding:10px 18px;background:#1D76DB;color:#fff;border-radius:8px;font-weight:700;text-decoration:none;">🎤 3D組立シミュレーターを開く（スクリーンに実バナー表示）</a>
  <a href="/dl/lt-paper-a4.pdf" target="_blank" style="display:inline-block;padding:10px 18px;background:#444;color:#fff;border-radius:8px;font-weight:700;text-decoration:none;">📄 スクリーン紙・ロゴ紙のA4印刷PDF</a>
</div>

<div style="display:flex;justify-content:center;margin:8px 0 16px;">
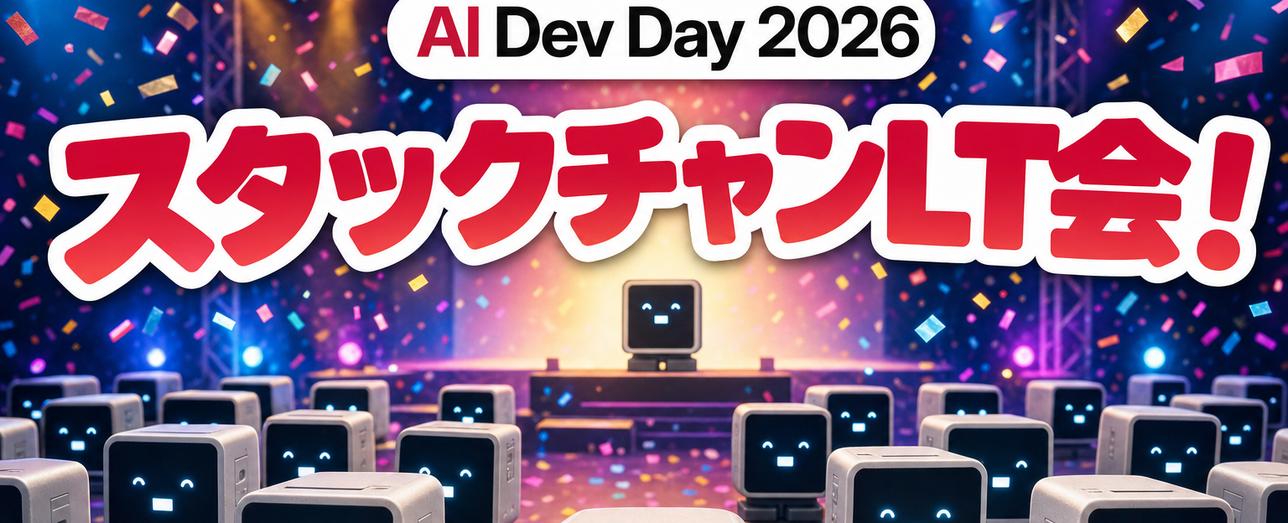
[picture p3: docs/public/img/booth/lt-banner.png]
スクリーン壁に差し込むバナー紙（スタックチャンLT会！・AI Dev Day 2026ロゴ入り）
  
</div>

着せ替えたスタックチャンを置いて記念撮影できる、卓上サイズの撮影ブースです。コンセプトは「**スタックチャンが現実世界で生活してる**」×「**Happy Birthday**」＝ **教室でお誕生日会** のジオラマ。床・壁を**3Dプリントで質感表現**し、装飾は画像プリント＋100円ショップ品で仕上げます（2026-07-15 方針変更：ボード工作 → 3Dプリント化、[Issue #13](https://github.com/aieo-product/stackchanEventBooth/issues/13)）。

## コンセプト

スマホで撮るだけでSNS映えする画づくりを、卓上の小さなステージで実現します。来場者は着せ替えたスタックチャンを教室の定位置（黒板前）に置いて、その場で撮影 → `#ｽﾀｯｸﾁｬﾝお誕生日2026` で投稿、という体験を楽しめます。身長6cmのスタックチャンに対し、1/12ドールハウススケールの机・椅子は「小学生が教室にいる」サイズ感になります。

### 完成予想図

<div style="display:flex;justify-content:center;margin:16px 0;">
  学校ジオラマ撮影ブースの完成予想CG（黒板・窓・掲示板の壁パネルと木床タイル、机椅子と自販機、黒板前のスタックチャン）
</div>

> AI生成の完成イメージ（2026-07-15）。床＝フローリングタイル、背面壁＝窓／黒板／掲示板パネル、小物＝学校机椅子・ベンチ・自販機（MakerWorld選定品）、装飾＝紙ガーランド・時間割・造花という本設計の構成をそのまま再現しています。

<div style="display:flex;justify-content:center;margin:24px 0;">
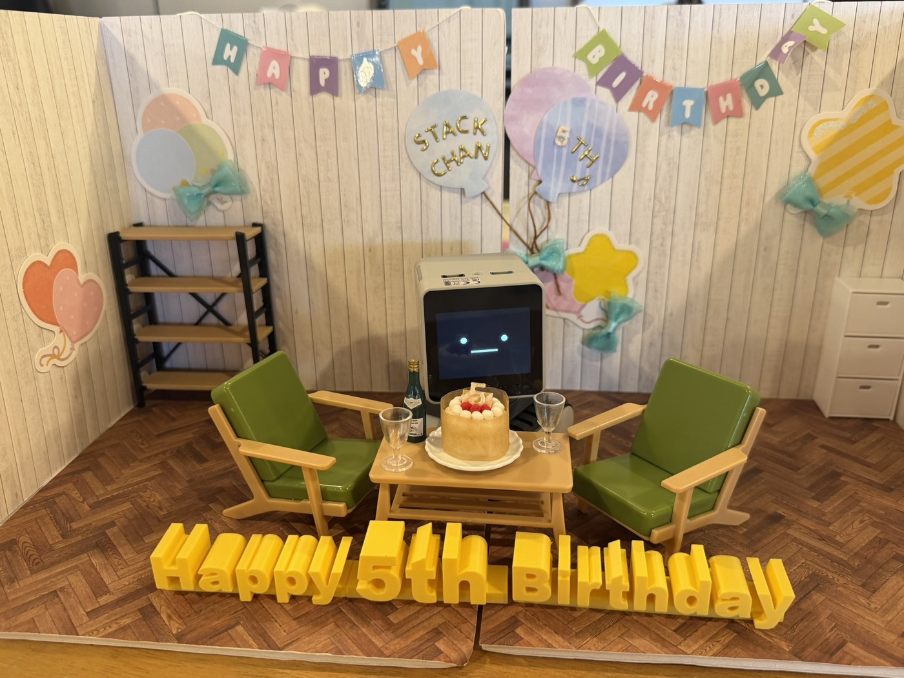
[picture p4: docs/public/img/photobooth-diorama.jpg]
Happy Birthday スタックチャンのジオラマ撮影ブース実例
  
</div>

<div style="display:flex;justify-content:center;margin:8px 0 24px;">
  撮影ブースのコンセプト図
</div>

::: info 画像・出典について
上の写真は **[@k8ark（konkei）さん](https://x.com/k8ark/status/2071025950758994294)** が `#ｽﾀｯｸﾁｬﾝお誕生日2026` で公開されたジオラマ撮影ブースを **着想元の参考**として掲載しています。掲載・参考にあたっては制作者へ許諾を依頼中です（許諾が得られない場合は差し替えます）。本企画の装飾・小物は新規制作し、第三者の造形を流用する場合は許諾を取得します。
:::

## 構成要素

| 要素 | 作り方 | 内容 |
|---|---|---|
| 🟫 **床（教室フローリング）** | **3Dプリント** | 150×150mmの木床テクスチャタイル×8枚（W600×D300） |
| 🧱 **壁（黒板・窓・掲示板）** | **3Dプリント** | 150×125mmパネル×8枚（背面W600×H250）。質感のみ印刷 |
| 🪑 **ミニ家具・小物** | **3Dプリント（MakerWorld）** | 学校机・椅子・黒板等の1/12ミニチュア（下記選定リスト） |
| 🎉 **装飾** | 画像プリント＋100均 | 時間割表・学級掲示・"HAPPY BIRTHDAY STACK-CHAN"バナーを紙印刷して貼付。造花・ガーランド等は100均調達 |
| 📍 **定位置マーカー** | 3Dプリント | 黒板前の撮影位置目印（床タイル1枚に一体成形） |
| 💡 **卓上照明** | 既存計画どおり | 安定した明るさのLED。推奨アングル・ハッシュタグ掲示を併設 |

## 3Dプリント設計（床・壁）

質感（テクスチャ）だけを3Dプリントで出し、ベタの大物印刷を避けて**軽量・短時間**で作ります。全パーツX2Dビルドプレート内（最大150mm角）、裏面ダブテール連結で**現地組立5分**です。

| パーツ | 個数 | サイズ | 単重(g) | 印刷時間/個 | 推奨色 |
|---|--:|---|--:|--:|---|
| 床タイル（フローリング木目テクスチャ） | 8 | 150×150×t3 | 22 | 0.8h | アーモンドイエロー（明るい木色） |
| 壁パネル（黒板） | 2 | 150×125×t5 | 22 | 1.0h | アッシュグレー＋緑塗装 or 緑画用紙貼付 |
| 壁パネル（窓枠） | 4 | 150×125×t5 | 18 | 0.9h | アイボリーホワイト（窓部は空色画用紙） |
| 壁パネル（掲示板） | 2 | 150×125×t5 | 20 | 0.9h | アイボリーホワイト |
| 壁スタンド（差し込み式） | 4 | 100×80×t8 | 10 | 0.4h | アッシュグレー |
| 連結クリップ・定位置マーカー | 一式 | — | 30 | 1.2h | 各色 |
| **小計（床・壁）** | | | **約400g** | **約17h** | |

- **床**: タイル裏面のダブテールで連結。表面は0.6mmの浮き彫りで床板の目地を表現（塗装不要で影が出る）。
- **壁**: パネル4枚×2段を連結し、背面の差し込みスタンドで自立。黒板パネルは中央に配置し、撮影の背景になる。
- **装飾は印刷しない**: ポスター・時間割・バナーは紙に印刷して壁パネルの掲示板部に貼るだけ。100均の造花・ミニガーランドを床端に配置。

## 教室の小物（MakerWorldで印刷・2026-07-15 選定済み）

机・椅子などの小物は**MakerWorldの既存ミニチュアモデル**を印刷します（新規モデリングしない＝時間節約）。調査（[research/makerworld-props-20260715.md](https://github.com/aieo-product/stackchanEventBooth/blob/main/research/makerworld-props-20260715.md)）の結果、以下を採用します。いずれもPrint Profile付きでそのまま印刷可能です。

| 採用 | 小物 | 制作者 | ライセンス | 印刷時間 | 用途 |
|:--:|---|---|---|--:|---|
| ❌ | ~~[教室のミニチュアシーン一式](https://makerworld.com/ja/models/2750405)~~ | MonsieurPierre | MW標準 | — | **不採用**（机・棚がベース一体成形で単品配置不可と判明・2026-07-15）→ 下記の単品ミニチュアに差し替え |
| ✅ | [ビンテージ学校机と椅子セット](https://makerworld.com/ja/models/1314963) ×2 | Printed a mini | MW標準 | 1.3h×2 | 主役家具（黒板前の定位置） |
| ✅ | [1/12 校庭ベンチ](https://makerworld.com/ja/models/1276012)（拡縮対応設計） | Foximg | MW標準 | 48分 | ステージ端の校庭コーナー |
| ✅ | [日本の自動販売機](https://makerworld.com/ja/models/1615169)（4色AMS・塗装不要） | PattyWithAP | MW標準 | 3.6h | 「現実世界の生活感」の決め手 |
| ✅ | [極小本棚＋本](https://makerworld.com/ja/models/997513)（1/12・本は別STLで自由配置） | maker_snail | **CC BY-SA** | 3h | 教室の背面。ライセンス最も自由 |
| ✅ | [1:12 バースデーケーキ](https://makerworld.com/ja/models/3018883) | MonsieurPierre | MW標準 | 38分 | 「教室でお誕生日会」の主役小物 |
| ✅ | [ゴミ箱 1:12](https://makerworld.com/ja/models/3045267)（Ø20×23mm） | box | MW標準 | 16分 | 教室の隅の生活感 |
| ✅ | [1/12 壁掛け時計](https://makerworld.com/ja/models/1700968)（STLのみ・要スライス） | BlueBucket | MW標準 | 約0.5h | 黒板上の壁パネルに接着 |
| ✅ | [ローポリ教室地球儀](https://makerworld.com/ja/models/2410472)（要リサイズ） | LowPolyFigures | CC BY-NC | 1.1h | 教卓・本棚上の小物 |
| 任意 | [MonsieurPierre 学校机+椅子](https://makerworld.com/ja/models/2658444)（1.6h）・[自立黒板](https://makerworld.com/ja/models/2664912)（2.8h）・[学校ロッカー](https://makerworld.com/ja/models/3034053)（3.8h）・[通学バッグ](https://makerworld.com/ja/models/2661075)（1.6h）・[街灯](https://makerworld.com/ja/models/2732902)（24分） | MonsieurPierre他 | MW標準 | — | 時間が余れば追加（同一作者シリーズで世界観統一可） |

- 採用9点の合計は**約13h・約250g**（7/21に机椅子・ベンチ・自販機・ケーキ・ゴミ箱、残りは7/23予備日に配分）。すべて**単品配置可能なことを説明文・実写真・プレート構成で確認済み**（[再調査詳細](https://github.com/aieo-product/stackchanEventBooth/blob/main/research/makerworld-props-20260715.md)）。スケールは1/8〜1/12混在だが、スタックチャン身長6cmに対し「小学生が教室にいる」サイズ感として成立。
- **ライセンス注意**: MW標準ライセンス＝個人・非商用の印刷可／**データ再配布・販売は不可**。本ブースは非売品展示のため範囲内。クレジット表示＋可能な範囲で作者へ一報（[調査方針](https://github.com/aieo-product/stackchanEventBooth/blob/main/research/makerworld-survey-20260713.md)踏襲）。ケーキ等のお誕生日小物は100均で代替。

## 装飾リスト（画像プリント＋100均・2026-07-16 実売調査済み）

100円ショップの調達品はダイソーネットストア等で**実売・価格を確認済み**（商品リンク付き・[調査詳細](https://github.com/aieo-product/stackchanEventBooth/blob/main/research/hyakkin-props-20260716.md)）。**神田周辺のダイソー1店でほぼ揃います**（セリアはEC非対応のため欠品時の第2候補・店頭確認）。

**紙プリント（自作・約¥300）**: "HAPPY BIRTHDAY STACK-CHAN"バナー（A4×2分割）／時間割表・学級目標・給食当番表（掲示板用3〜4枚）／窓の外の空・校庭背景（窓パネル裏4枚）

| 区分 | 品目 | 価格(税込) | リンク | 使いどころ |
|---|---|--:|---|---|
| 🎉 誕生日装飾 | ハッピーバースデーガーランド（142cm紙製） | ¥110 | [ダイソー](https://jp.daisonet.com/products/4549892413001) | 背面壁W600の上部 |
| 🎉 誕生日装飾 | ケーキトッパー Happy Birthday | ¥110 | [ダイソー](https://jp.daisonet.com/products/4550480214283) | 机上・3Dプリントケーキの横 |
| 🎉 誕生日装飾 | ペーパーファン・ボールセット | ¥110 | [ダイソー](https://jp.daisonet.com/products/4550480386584) | 吊り下げの奥行き演出 |
| 🎉 誕生日装飾 | フェルトガーランド BIRTHDAY（150cm） | ¥110 | [キャンドゥ](https://netshop.cando-web.co.jp/view/item/000000011565) | 手作り感の追加（任意） |
| 🪑 ミニチュア | リビングテーブル（7.9×3.7×4.3cm・1/12） | ¥110 | [ダイソー](https://jp.daisonet.com/products/4965534119917) | 6cmスタックチャンと好相性 |
| 🪑 ミニチュア | **保健室のベッド** | ¥110 | [ダイソー](https://jp.daisonet.com/products/4965534167611) | 学校モチーフで世界観に最適 |
| 🪑 ミニチュア | 食器セット ホワイト/クリア（1/12） | 各¥110 | [白](https://jp.daisonet.com/products/4965534322621)/[クリア](https://jp.daisonet.com/products/4965534402613) | お誕生日会のテーブル |
| 🪑 ミニチュア | パン屋さんセット（レジ台・陳列棚） | ¥550 | [ダイソー](https://jp.daisonet.com/products/4550480433516) | 購買部コーナー（任意） |
| 🌿 質感補助 | フェイクグリーン（21×23×20cm） | ¥330 | [ダイソー](https://jp.daisonet.com/products/4550480579313) | 窓際の観葉植物 |
| 🌿 質感補助 | 芝生調シート（シール式） | ¥110 | [ダイソー](https://jp.daisonet.com/products/4991203188373) | 校庭コーナーの床 |
| 🌿 質感補助 | リメイクシート 木目ライトブラウン（90×30cm） | ¥110 | [ダイソー](https://jp.daisonet.com/products/4550480022499) | 床の補助・テーブル面拡張 |
| 💡 撮影・固定 | 3LEDプッシュライトミニ（連続30h） | ¥110 | [ダイソー](https://jp.daisonet.com/products/4972822311144) | 補助照明 |
| 💡 撮影・固定 | **ゲル両面テープ**（耐荷重500g/10cm） | ¥110 | [ダイソー](https://jp.daisonet.com/products/4550480071145) | ミニチュア転倒防止の仮固定 |
| 💡 撮影・固定 | 耐震マット×4 | ¥110 | [ダイソー](https://jp.daisonet.com/products/4549131944020) | 観覧車ベース・照明の固定 |
| 💡 撮影・固定 | クリアイーゼル | ¥110〜220 | [ダイソー](https://jp.daisonet.com/products/4550480163284) | ハッシュタグ・推奨アングル掲示 |
| 💡 撮影・固定 | 発泡なんでも板 A2（60×42cm） | ¥110 | [ダイソー](https://jp.daisonet.com/products/4984343618190) | 土台補強・搬送緩衝 |
| | | **100均合計 約¥2,600〜3,000**＋紙プリント¥300 ＝ **約¥3,300** | | |

> 価格未確定の候補（光るガーランド・テープライト・ワッツのアイビー）は [調査詳細](https://github.com/aieo-product/stackchanEventBooth/blob/main/research/hyakkin-props-20260716.md) を参照し購入時に確認。

## フィラメント・印刷時間（撮影ブース分）

| 区分 | 量 | 時間 |
|---|--:|--:|
| 床・壁・スタンド類 | 約400g | 約17h |
| MakerWorld小物 | 約150g | 約8h |
| マージン +25% | +140g | — |
| **合計** | **約0.7kg** | **約25h** |

観覧車・アクセサリーと合算した**統合印刷スケジュール（7/15〜7/23・X2D 1台）**は [観覧車 > 印刷スケジュール](/ferris-wheel#印刷スケジュール-x2d-1台・立ち会い運用・観覧車-撮影ブース-アクセサリー統合) に一本化しています（撮影ブース分は7/20〜21に印刷）。

## 撮影の流れ

1. 好きなアクセサリーでスタックチャンを着せ替える
2. 撮影ブースの定位置にスタックチャンを置く
3. スマホで撮影（推奨アングルを掲示）
4. `#ｽﾀｯｸﾁｬﾝお誕生日2026` で投稿

## 設営の要件

- ステージは **W600 × D300**（設置余白込みで卓上 **W700 × D450**）。[観覧車](/ferris-wheel)と同じテーブル（W1800）に同居するため従来案（W900）から縮小（レイアウトは[必要スペース](/space)）
- 床タイル・壁パネルはダブテール連結＋差し込みスタンドで**設営／撤収5分以内**（工具不要）
- 分解するとタイル・パネルの平積みになり、折りたたみコンテナ1箱で搬入可能な軽量構成（印刷部品 約550g）

> ベースのアイデアは、コミュニティのお誕生日会で見られた卓上ジオラマ撮影スポットです。撮影ブースの床・壁は本企画で新規制作し、教室の小物はMakerWorldのモデルを**ライセンス順守・クレジット表示**のうえ印刷します。

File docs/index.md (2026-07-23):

---
layout: home

hero:
  name: スタックチャン
  text: お着替え＆撮影ブース
  tagline: AI Dev Day 2026 ｜ 着せ替えアクセサリー × お誕生日ジオラマ撮影ブースで、来場者と一緒にイベントを盛り上げる
  actions:
    - theme: brand
      text: 必要スペースを見る
      link: /space
    - theme: alt
      text: アクセサリー一覧
      link: /accessories
    - theme: alt
      text: 撮影ブース
      link: /photobooth

features:
  - icon: 🎀
    title: 着せ替えアクセサリー
    details: 耳・帽子・ヘッドホン・ボディケース・キーホルダーなど、3Dプリント製アクセサリーで自分だけのスタックチャンに。造形は各制作者へ許諾を得てから設置します。
    link: /accessories
    linkText: 用意するアクセサリー
  - icon: 📸
    title: 簡易撮影ブース
    details: 「Happy Birthday スタックチャン」のジオラマ背景で記念撮影。スマホで撮ればそのままSNS映え。卓上サイズで設営も簡単。
    link: /photobooth
    linkText: 撮影ブースの詳細
  - icon: 📐
    title: 必要スペース
    details: 想定は 2.0m × 2.0m のテーブルブース1区画。展示テーブル＋撮影ブース＋来場者の回遊スペースをレイアウト図でわかりやすく。
    link: /space
    linkText: レイアウト図を見る
---

## このブースで提供する体験

来場者が **① スタックチャンを着せ替え → ② 撮影ブースで記念撮影 → ③ ハッシュタグで投稿** という流れで、見て・触って・撮って楽しめる参加型ブースです。

<div class="tip custom-block" style="padding-top: 8px">

スタックチャンは M5Stack ベースのオープンソース卓上ロボット。`#ｽﾀｯｸﾁｬﾝお誕生日2026` ではコミュニティの皆さんが多彩なアクセサリーを公開しています。本ブースはそうした造形例を参考に、**各制作者の許諾を得たうえで** お着替え体験として展示します。

</div>

## 4つの要点

| # | ポイント | 概要 |
|---|---|---|
| 1 | **用意するアクセサリー** | 6カテゴリ（耳・帽子・ヘッドホン・ボディケース・キーホルダー・ネームバッジ）。[→ 一覧](/accessories) |
| 2 | **簡易撮影ブース** | お誕生日ジオラマ背景＋ミニ家具。卓上 W900×D450 に収まる自立式。[→ 詳細](/photobooth) |
| 3 | **必要スペース** | **2.0m × 2.0m**（推奨 2.0m×3.0m）。[→ レイアウト図](/space) |
| 4 | **運営時間** | **13:00–17:00（4時間）**／設営〜12:30・撤収17:00〜。[→ 当日運営](/schedule) |

## 準備・経費

3Dプリンター（**Bambu Lab X2D**）でアクセサリーを印刷するための準備と、イベント経費を整理しています。

- 🎡 [**観覧車（手回し・虹色LED）**](/ferris-wheel)：スタックチャン実機が乗った観覧車を来場者がクランクで回す参加型展示。虹色LED・3Dプリント設計・BOM・印刷スケジュール
- 🖨️ [**プリント環境と必要量**](/printing)：印刷設定・データ準備と、<b>フィラメント必要量（実質約1.2〜1.3kg）</b>の計算
- 💴 [**経費まとめ**](/expenses)：Bambu Lab X2D は保有済み。計上は<b>フィラメント ¥16,142（初回¥13,100＋PLAウッド¥3,042）＋観覧車追加パーツ 約¥6,700 ＝ 約¥22,800</b> 

## 検討中の論点

ブースを成功させるための**懸念点**と、盛り上げる**アイディア**も整理しています（随時追加）。

- ⚠️ [**懸念点**](/concerns)：スタックチャンの**ネットワーク接続問題**（混雑会場でのWi-Fi）など、事前に潰したいリスク
- 💡 [**アイディア**](/ideas)：**LLM Moduleで低レイテンシー会話デモ**、**当日イベント案内・同フロア連携**など
- 🎤 [**LT企画**](/lt)：15分LT「**スタックチャンの歴史 → Module-LLMの苦労話 → ローカルLLM実装**」（2人リレー構成）の構成・進め方
- 🖥️ [**LTスライド（発表資料）**](/slides/lt.html){target="_blank"}：リッチHTML全20枚。ブラウザでそのまま投影可
- 🎤 [**撮影ブース 3Dシミュレーター（LT会場ジオラマ）**](/viewer-booth/){target="_blank"}：登壇スタックチャン・演台・ステージ・スクリーンパネルの配置を3Dで確認
- 📺 [**フォトウォール（当日投影用）**](/photowall/){target="_blank"}：<b>#ｽﾀｯｸﾁｬﾝ写真館 #AIDevDay</b> 付きXポストの写真を10秒ごとにスライドショー表示。`F`キーで全画面（[サンプル表示](/photowall/?data=posts.sample.json){target="_blank"}）

## イベント情報

| 項目 | 内容 |
|---|---|
| イベント | [AI Dev Day 2026](https://aidevday.com/) |
| 日程 | 2026年7月24日（金）|
| 会場 | 大手町プレイスホール＆カンファレンス（東京・大手町）|
| 出展場所 | **1F コミュニティショーケース**（コミュニティが1時間シフトで交代）|
| ブース運営 | 13:00–17:00 |
| 体験 | スタックチャン お着替え ＋ 記念撮影 |

<div class="warning custom-block" style="padding-top: 8px">

**アクセサリーの取り扱い方針**：本ブースで展示・印刷する造形は、コピーではなく **各制作者に許諾を得てから** 設置します。調査した造形例と制作者は許諾管理リストで追跡し、クレジット（制作者名・配布元リンク）を必ず表示します。

</div>

---

> この提案サイトは関係者共有用です。内容はドラフトで、会場レギュレーション確認後に確定します。

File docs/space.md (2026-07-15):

# 必要スペース

ブースの場所・必要な広さ・レイアウトをまとめます。**会場は大手町プレイス ホール＆カンファレンス 1F の「コミュニティショーケース」エリア**（Conference105 前のオープンスペース）を想定しています。

## 出展場所（1F コミュニティショーケース）

<div style="display:flex;justify-content:center;margin:20px 0;">
  大手町プレイス1F コミュニティショーケースの位置
</div>

- 公式図面（1/200）: [大手町プレイス 1F 図面 (PDF)](https://otemachi-place-hc.jp/wp-content/uploads/sites/2/2025/06/1f-scale.pdf)
- 参考寸法（公式図面より）: Conference105 = 6,516 × 13,976mm ／ 通路幅 = 約 4,400mm

::: warning ⏱ 重要：1時間シフトで交代
コミュニティショーケースは **「コミュニティが1時間シフトで交代」** する運用です。そのため本ブースは **卓上で完結し、短時間（目安5〜10分）で設営・撤収できる** モジュール構成にします。床置きの大型什器は使いません。
:::

## 結論：どれくらいの広さが必要か

**割り当ては「テーブル1台相当（W1800×D600 想定・要確認）」** を基準に、卓上完結で設計します。専用の床面積は不要で、来場者は通路側に立って体験します。

| パターン | 専有スペース | 内容 | 適する場合 |
|---|---|---|---|
| **基準（想定）** | テーブル **W1800×D600** 1台＋来場者立ち位置 | 卓上に展示＋撮影ブースを集約。床置きなし | 標準的なショーケース割当 |
| **省スペース** | ハーフテーブル **W900×D600** | 撮影ブースと展示を兼用、点数を絞る | 割当が小さい場合 |
| **ゆとり** | テーブル2台分 | 展示と撮影を分離、複数台同時体験 | 割当が広い場合 |

::: tip ポイント
撮影ブースを **W700×D450**（ステージW600×D300）に縮小し、中央に **観覧車（接地350×250）** を加えた3ゾーン構成でも、**テーブル1台で「展示＋観覧車＋撮影」が完結** します（2026-07-15 更新・[観覧車](/ferris-wheel)追加）。
:::

## レイアウト図（テーブル1台・卓上完結）

<div style="display:flex;justify-content:center;margin:24px 0;">
  テーブル1台に展示と撮影ブースを集約したレイアウト
</div>

### 卓上の内訳（2026-07-15 更新：観覧車を追加した3ゾーン構成）

| ゾーン | サイズ目安 | 内容 |
|---|---|---|
| 🟨 着せ替え展示 | テーブル左 約 W550×D600 | アクセサリーをトレイで陳列。スタッフはテーブル内側 |
| 🎡 観覧車 | テーブル中央 約 W450×D400 | [電動・虹色LED観覧車](/ferris-wheel)（接地350×250・全高450）。スタックチャン実機が搭乗 |
| 🟥 撮影ブース | テーブル右 卓上 W700×D450 | [3Dプリント製 教室ジオラマ](/photobooth)（ステージW600×D300）の撮影スポット |
| 🟦 来場者立ち位置 | 通路側(約4.4m幅の通路を共用) | 着せ替え→観覧車見学→撮影→投稿。床専有なし |

> 幅の検算: 展示 550 ＋ 観覧車 450 ＋ 撮影ブース 700 ＝ **1,700mm ≦ W1800**（余白100mm）。奥行はいずれも D600 内。

## 設備・什器の要件

| 項目 | 要件 | 備考 |
|---|---|---|
| テーブル | W1800×D600 ×1（主催/会場手配・**要確認**） | クロス掛け |
| 椅子 | スタッフ用 1〜2 | — |
| 電源 | 1口〜（**要確認**） | 実機・卓上照明用。モバイルバッテリーで代替可 |
| 照明 | 卓上LED ×1 | 撮影品質の安定用 |
| 収納 | 折りたたみコンテナ ×1〜2 | 交代時に素早く搬入出 |

::: warning 主催に確認したい事項
- **出展枠の運用**：1時間枠×複数回／1回のみ／13–17通し のいずれか（→ [当日運営](/schedule)）
- **割り当てスペース（テーブル）のサイズ**：本サイトは「W1800×D600 1台」を仮置き
- 電源の提供可否・容量／搬入経路・搬入出時間
:::

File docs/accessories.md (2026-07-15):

# 用意するアクセサリー

スタックチャン本体（M5Stack ベースの卓上ロボット）に<b>装着して見た目を変える「着せ替えアクセサリー」</b>を用意します。来場者がその場で付け替えて、自分だけのスタックチャンを作れます。

::: tip 「着せ替えアクセサリー」の範囲（2026-07 再整理）
[ｽﾀｯｸﾁｬﾝお誕生日会2026](https://stack-chan.connpass.com/event/394846/)（2026-06-27・参加者140名）の参加者とX投稿を照合し、**本体に装着するもの**を「着せ替えアクセサリー」として選定しました。キーホルダー・ミニチュア・名札・乗り物・スタンド等は**着せ替えではない別カテゴリ**として切り分けています（[→ その他造形](#その他の造形-着せ替えではないもの)）。
:::

## カテゴリ一覧（着せ替えアクセサリー・本体に装着）

| カテゴリ | 内容 | 数量目安 |
|---|---|---|
| 🫧 **透明シェル／着せ替えケース** | M5版本体の透明シェル。会場でも配布された交換式ケース | 数個 |
| 🐱 **猫耳（LED対応）** | 頭頂に付ける猫耳。透明PLA製・LED対応 | 各2〜3 |
| 🎩 **帽子・かぶりもの** | ミニハット・麦わら帽子・カスタム帽子など | 数種 |
| 🎧 **ヘッドホン** | 装着型ヘッドホン（カラーバリエーション） | 2〜3 |
| 🧥 **衣装（ファー帽子・マント）** | 着せ替え衣装 | 数種 |
| ✨ **髪型・その他カスタム** | ヘアパーツなど | 数種 |

## 着せ替えのイメージ

<div style="display:grid;grid-template-columns:repeat(auto-fit,minmax(240px,1fr));gap:12px;margin:24px 0;">
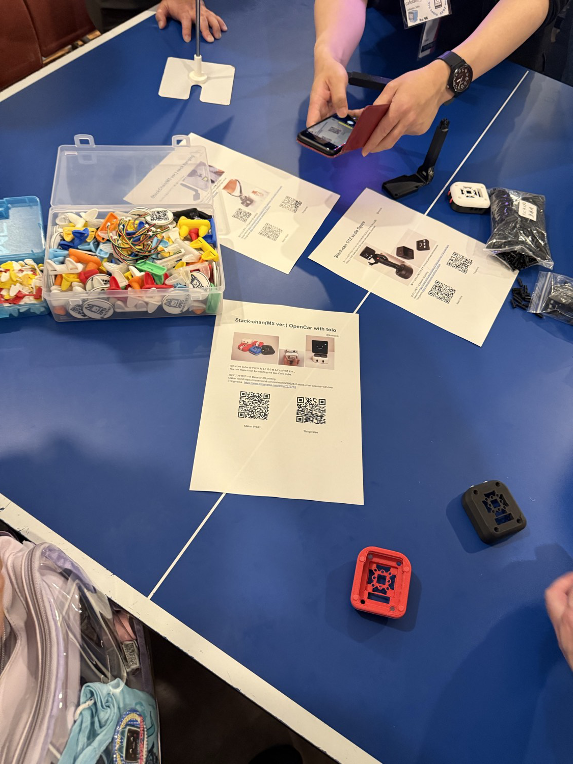
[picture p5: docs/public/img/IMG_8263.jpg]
スタックチャン用アクセサリーの展示テーブルとQRカード
  
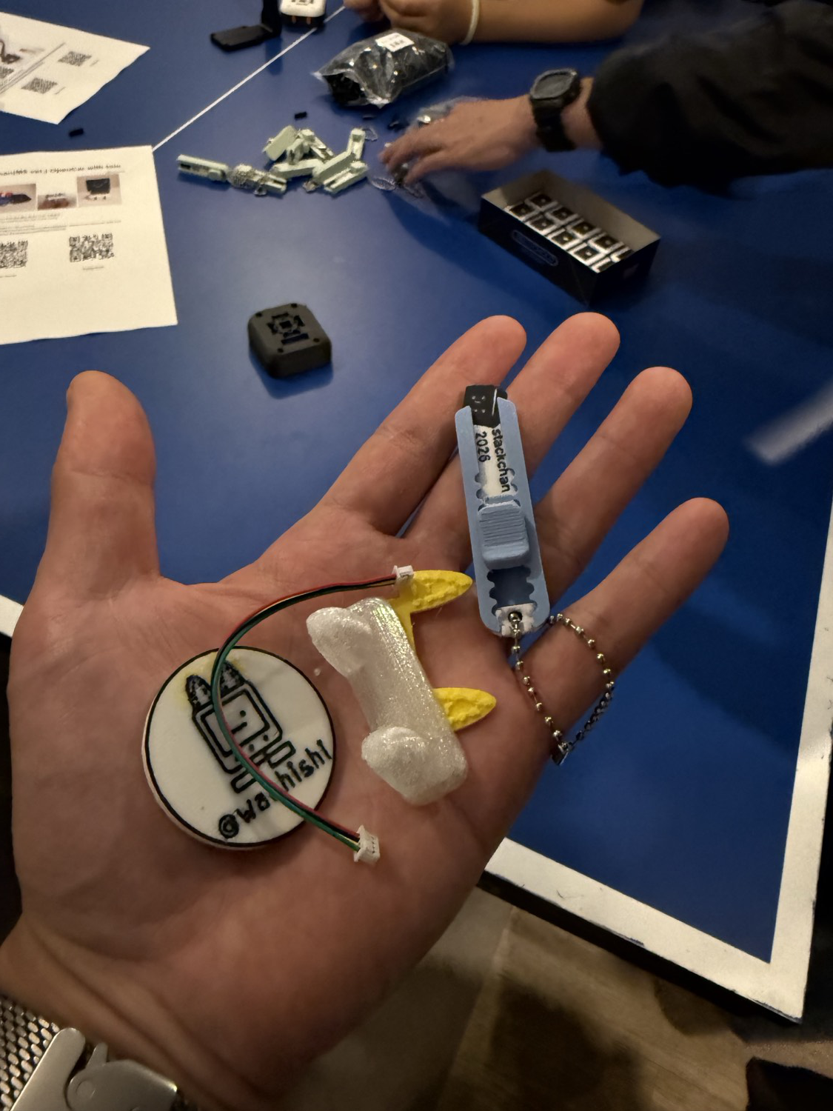
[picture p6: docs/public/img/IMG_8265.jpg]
耳・キーホルダー・ネームバッジなどのアクセサリー
  
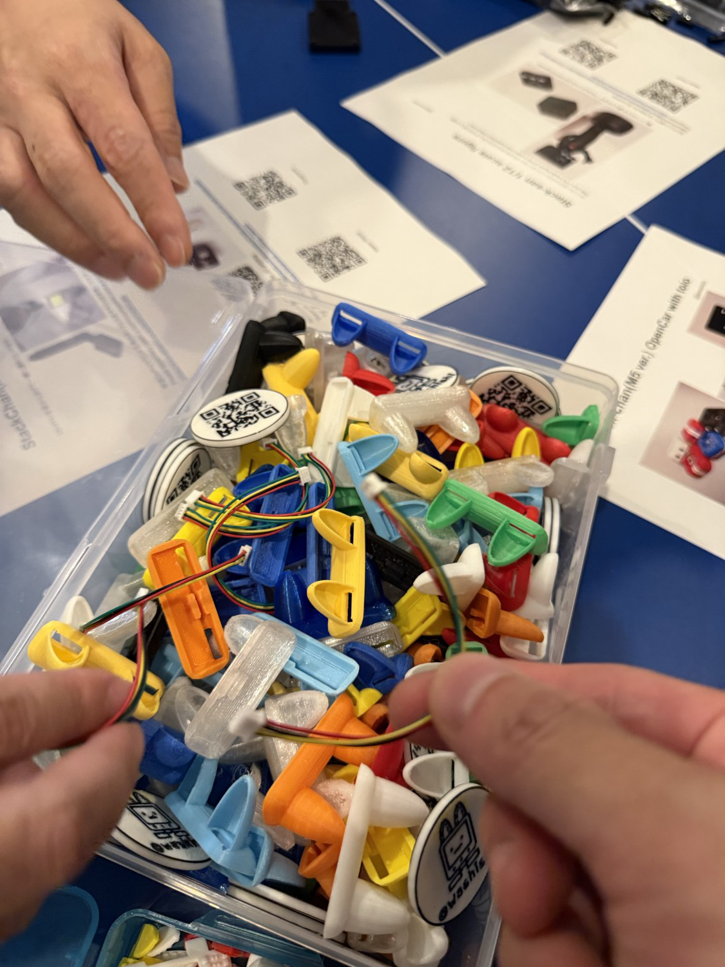
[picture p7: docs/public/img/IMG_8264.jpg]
3Dプリント製アクセサリーパーツ一式
  
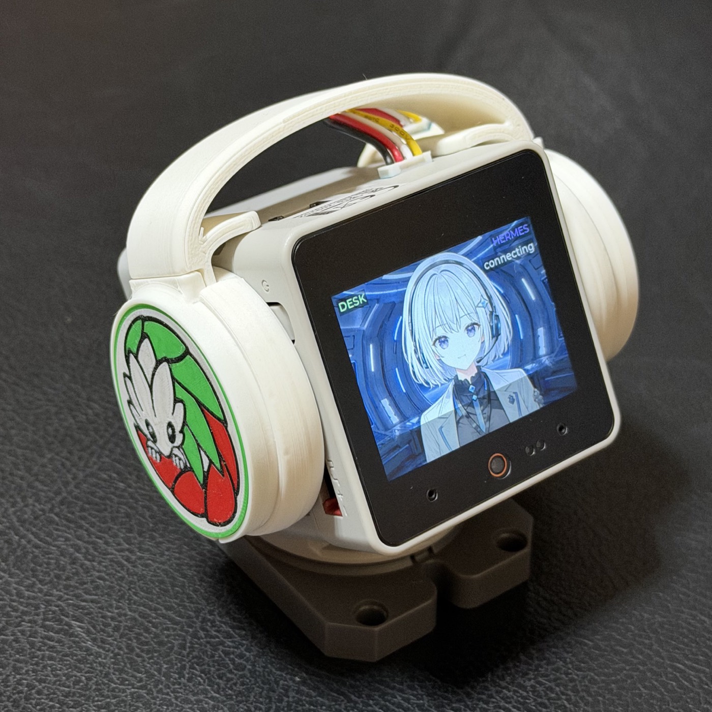
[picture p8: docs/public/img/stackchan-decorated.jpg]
ヘッドホン等を装着したスタックチャン
  
</div>

<div style="display:flex;justify-content:center;margin:24px 0;">
  スタックチャン着せ替えカテゴリ図
</div>

::: info 画像について
上記はコミュニティのお誕生日会で見られた **着想元の参考写真** です（撮影：本企画メンバー）。実際にブースで展示・印刷する造形は、**各制作者の許諾を得たもの** をクレジット付きで使用します。掲載に問題がある画像はご連絡ください。
:::

## 造形例と制作者（X調査・画像付き）

`#スタックチャン` / `#ｽﾀｯｸﾁｬﾝお誕生日2026` で公開されている造形例と、その **制作者・投稿** の一覧です。画像をクリックすると元ポストが開きます。

::: warning ⚠️ 掲載画像は各制作者の権利物です（許諾依頼中）
以下の画像・造形は各制作者に帰属します。ブースでの展示・（データ配布物の）印刷は **許諾を得てから** 行います。**現在は許諾依頼中**で、掲載に問題がある場合は速やかに取り下げます。制作者の皆さま、掲載の可否・ご要望は [Issue #2](https://github.com/aieo-product/stackchanEventBooth/issues/2) またはご連絡ください。
:::

<div style="display:grid;grid-template-columns:repeat(auto-fill,minmax(260px,1fr));gap:18px;margin:24px 0;">

  <div style="border:1px solid var(--vp-c-divider);border-radius:12px;overflow:hidden;">
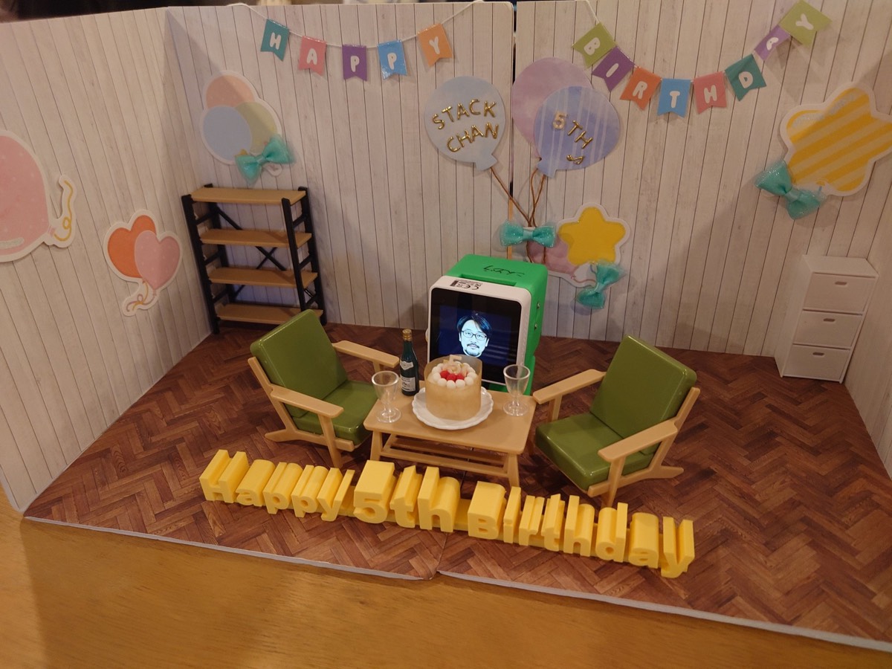
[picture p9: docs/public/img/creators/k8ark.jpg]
撮影ブース ジオラマ by @k8ark
    
    <div style="padding:10px 12px;">
      <div style="font-weight:700;">📸 撮影ブース（お誕生日ジオラマ）</div>
      <div style="font-size:.9em;color:var(--vp-c-text-2);">制作: <a href="https://x.com/k8ark" target="_blank" rel="noreferrer">@k8ark</a>（konkei）</div>
      <div style="font-size:.82em;color:#b45309;">許諾: 依頼中（最優先・本サイト掲載画像の権利者）</div>
    </div>
  </div>

  <div style="border:1px solid var(--vp-c-divider);border-radius:12px;overflow:hidden;">
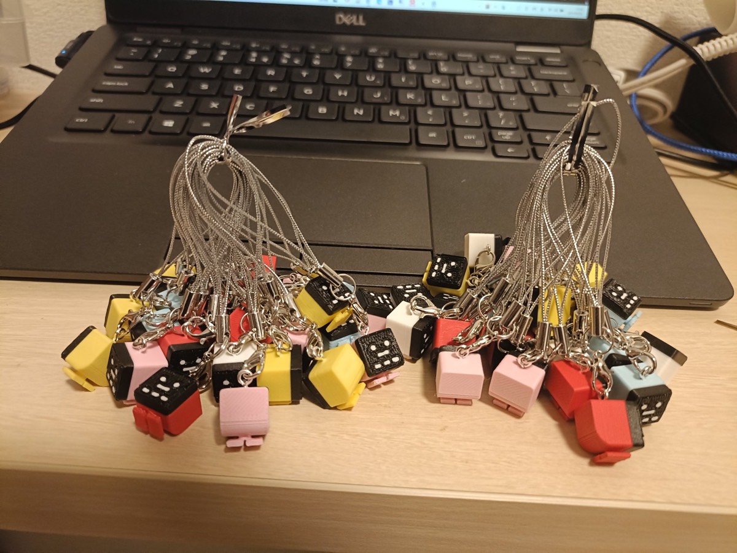
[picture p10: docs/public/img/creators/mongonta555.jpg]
ミニスタックチャン キーホルダー
    
    <div style="padding:10px 12px;">
      <div style="font-weight:700;">🔑 ミニスタックチャン キーホルダー/ストラップ</div>
      <div style="font-size:.9em;color:var(--vp-c-text-2);">制作: 未設定ちゃん ／ 配布: <a href="https://x.com/mongonta555" target="_blank" rel="noreferrer">@mongonta555</a>（Takao）</div>
      <div style="font-size:.82em;color:#b45309;">許諾: 依頼中</div>
    </div>
  </div>

  <div style="border:1px solid var(--vp-c-divider);border-radius:12px;overflow:hidden;">
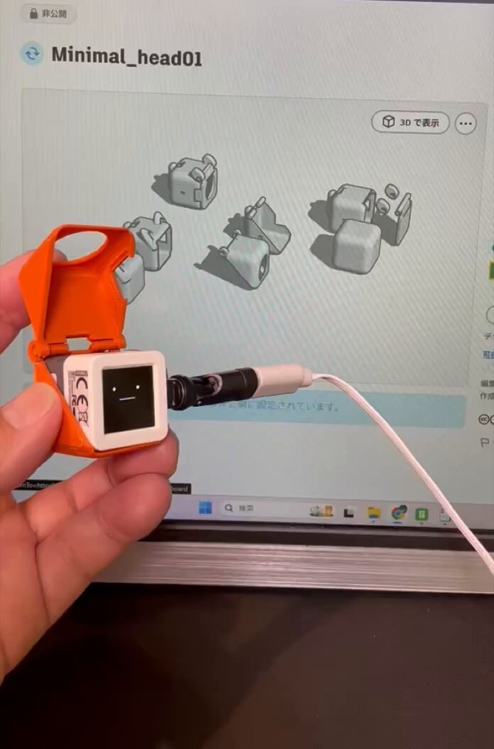
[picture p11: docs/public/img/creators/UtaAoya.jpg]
ミニマル スマホ版ケース＋キーホルダー
    
    <div style="padding:10px 12px;">
      <div style="font-weight:700;">🧊 ミニマル（スマホ版）ケース＋キーホルダー</div>
      <div style="font-size:.9em;color:var(--vp-c-text-2);">制作: <a href="https://x.com/UtaAoya" target="_blank" rel="noreferrer">@UtaAoya</a>（A-Uta）／3D設計・可動カバー</div>
      <div style="font-size:.82em;color:#b45309;">許諾: 依頼中</div>
    </div>
  </div>

  <div style="border:1px solid var(--vp-c-divider);border-radius:12px;overflow:hidden;">
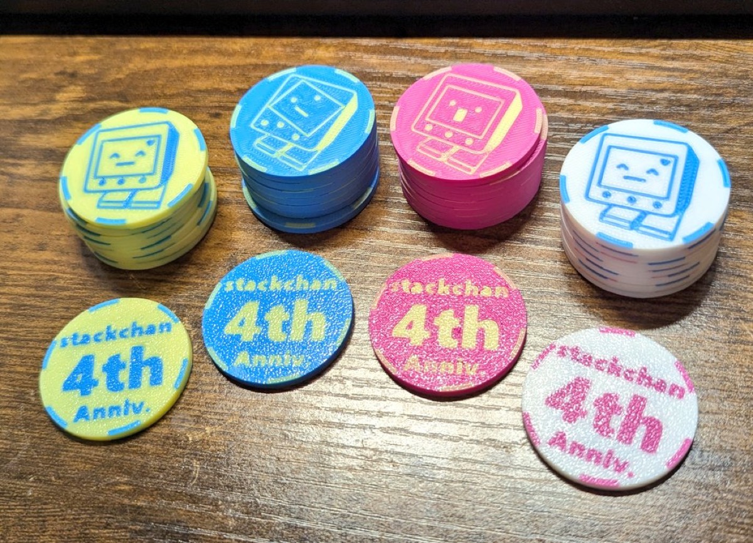
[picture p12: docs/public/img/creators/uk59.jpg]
アニバーサリーチップ MakerChip
    
    <div style="padding:10px 12px;">
      <div style="font-weight:700;">🪙 アニバーサリーチップ / MakerChip（16種・蓄光）</div>
      <div style="font-size:.9em;color:var(--vp-c-text-2);">制作: <a href="https://x.com/uk59" target="_blank" rel="noreferrer">@uk59</a>（くうねる）／福笑い・チップホルダーも配布</div>
      <div style="font-size:.82em;color:#b45309;">許諾: 依頼中</div>
    </div>
  </div>

  <div style="border:1px solid var(--vp-c-divider);border-radius:12px;overflow:hidden;">
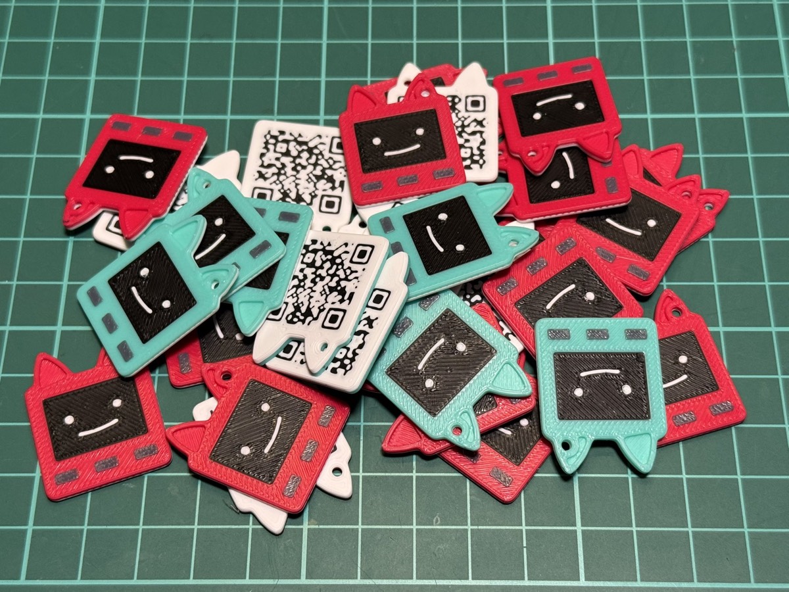
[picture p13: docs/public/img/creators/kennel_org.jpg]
QR付き スタックチャン顔タグ
    
    <div style="padding:10px 12px;">
      <div style="font-weight:700;">🪪 QR付き スタックチャン顔タグ/キーホルダー</div>
      <div style="font-size:.9em;color:var(--vp-c-text-2);">制作: <a href="https://x.com/kennel_org" target="_blank" rel="noreferrer">@kennel_org</a>（技研AIマーケット）</div>
      <div style="font-size:.82em;color:#b45309;">許諾: 依頼中</div>
    </div>
  </div>

  <div style="border:1px solid var(--vp-c-divider);border-radius:12px;overflow:hidden;">
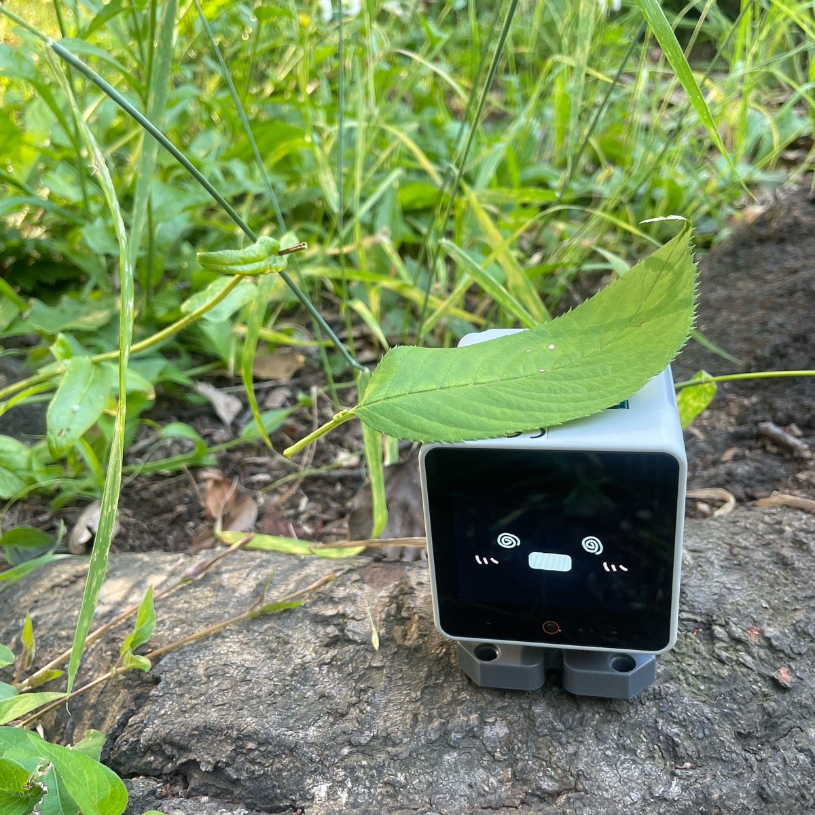
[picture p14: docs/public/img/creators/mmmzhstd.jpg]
麦わら帽子スタックチャン
    
    <div style="padding:10px 12px;">
      <div style="font-weight:700;">👒 麦わら帽子ほか（着せ替え）</div>
      <div style="font-size:.9em;color:var(--vp-c-text-2);">制作: <a href="https://x.com/mmmzhstd" target="_blank" rel="noreferrer">@mmmzhstd</a>（翼）</div>
      <div style="font-size:.82em;color:#b45309;">許諾: 依頼中</div>
    </div>
  </div>

  <div style="border:1px solid var(--vp-c-divider);border-radius:12px;overflow:hidden;">
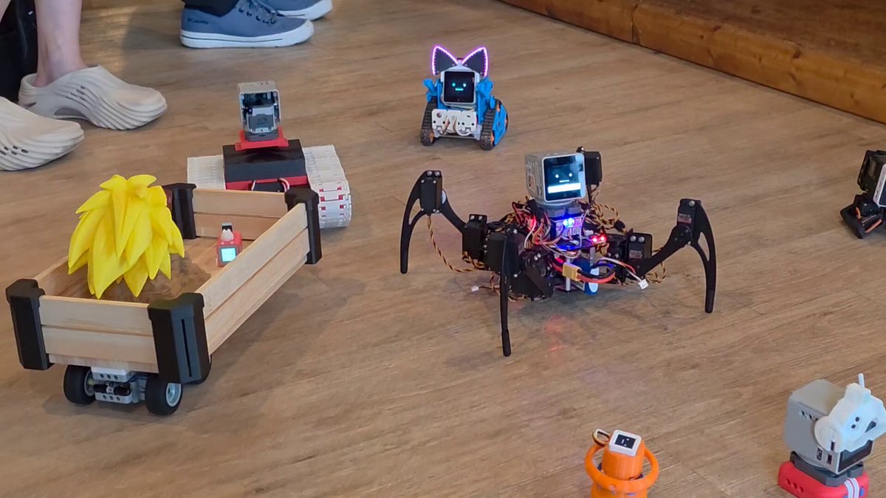
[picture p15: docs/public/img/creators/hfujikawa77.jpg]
カスタム各種 ネコ耳など
    
    <div style="padding:10px 12px;">
      <div style="font-weight:700;">🐱 カスタム各種（ネコ耳・髪 等）</div>
      <div style="font-size:.9em;color:var(--vp-c-text-2);">制作: <a href="https://x.com/hfujikawa77" target="_blank" rel="noreferrer">@hfujikawa77</a></div>
      <div style="font-size:.82em;color:#b45309;">許諾: 依頼中</div>
    </div>
  </div>

  <div style="border:1px solid var(--vp-c-divider);border-radius:12px;overflow:hidden;">
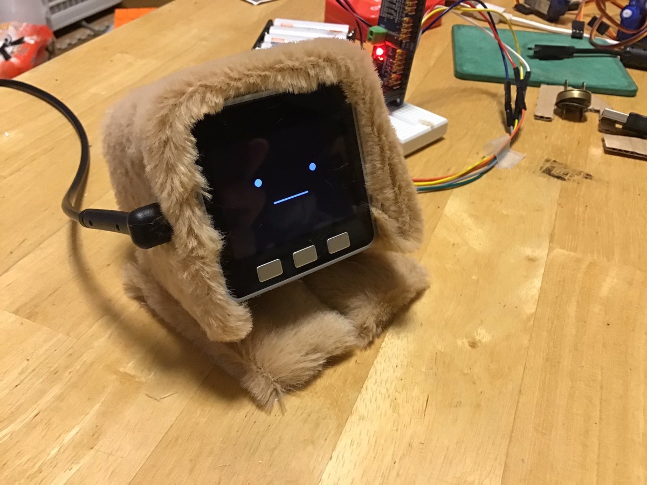
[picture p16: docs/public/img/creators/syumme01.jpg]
ファー帽子 着せ替え
    
    <div style="padding:10px 12px;">
      <div style="font-weight:700;">🧢 ファー帽子/マント（着せ替え）</div>
      <div style="font-size:.9em;color:var(--vp-c-text-2);">制作: <a href="https://x.com/syumme01" target="_blank" rel="noreferrer">@syumme01</a></div>
      <div style="font-size:.82em;color:#b45309;">許諾: 依頼中</div>
    </div>
  </div>

</div>

> 調査は継続中（`スタックチャン 配布`／`着せ替え` 等を Chrome で調査）。詳細な照合リストは [`research/accessories.md`](https://github.com/aieo-product/stackchanEventBooth/blob/main/research/accessories.md)、進捗は [Issue #2](https://github.com/aieo-product/stackchanEventBooth/issues/2)。耳/ヘッドホン単体の造形データ配布元は追加調査予定。

## 🖨️ MakerWorldで今すぐ印刷できる着せ替えアクセサリー（X2D対応）

[MakerWorld](https://makerworld.com/ja) は Bambu Lab 公式の3Dモデル共有プラットフォーム。多くのモデルに **Print Profile（Bambu向け事前スライス済みデータ）** が付いており、Bambu Studio / Bambu Handy から **手持ちの X2D にワンクリックで送って印刷**できます（＝実質そのまま生成可能）。

2026-07-13 に MakerWorld を<b>全数調査（33件）</b>し、装飾・着せ替えパーツ18件をライセンス別の量産優先度付きで整理しました（[調査詳細](https://github.com/aieo-product/stackchanEventBooth/blob/main/research/makerworld-survey-20260713.md)）。

**優先度の凡例**：🟢 すぐ量産可（CC0／クレジットのみ）／ 🟡 公式・SA継承あり ／ 🟠 非商用限定 or MW標準（展示OK・許諾/確認推奨）。⭐ は Print Profile 付きで印刷実績のある推し。

### 量産候補（優先度順・15件）

| 優先度 | アクセサリー | 種別 | ライセンス | 制作者 | Profile |
|:--:|---|---|---|---|:--:|
| 🟢 | [stackchancover](https://makerworld.com/ja/models/2839068) | 🧊カバー | **CC0** | [user_2302219760](https://makerworld.com/en/@user_2302219760) | ✅ |
| 🟢 | [Custom Hat Generator](https://makerworld.com/ja/models/2772131) ⭐ | 🎩帽子（自由生成） | **CC BY** | [beavers_hive](https://makerworld.com/en/@beavers_hive) | ✅ |
| 🟢 | [neck hanging parts](https://makerworld.com/ja/models/2870969) | 🪢首掛けパーツ | **CC BY** | [kenichi](https://makerworld.com/en/@kenichi) | ✅ |
| 🟡 | [Pharaoh decoration](https://makerworld.com/ja/models/2736962) ⭐ | 👑かぶりもの | CC BY-SA | [M5Stack公式](https://makerworld.com/en/@M5Stack) | ✅ |
| 🟡 | [American football decoration](https://makerworld.com/ja/models/2736961) | 🏈ヘルメット | CC BY-SA | [M5Stack公式](https://makerworld.com/en/@M5Stack) | — |
| 🟡 | [Christmas hat decoration](https://makerworld.com/ja/models/2736960) | 🎅サンタ帽 | CC BY-SA | [M5Stack公式](https://makerworld.com/en/@M5Stack) | — |
| 🟠 | [Stack-chan headphone](https://makerworld.com/ja/models/2858793) ⭐ | 🎧ヘッドホン | CC BY-NC-SA | [sskw](https://makerworld.com/en/@sskw) | ✅ |
| 🟠 | [Brick Hat](https://makerworld.com/ja/models/2855044) ⭐ | 🧱ブロック帽子 | CC BY-NC | [user_4023807793](https://makerworld.com/en/@user_4023807793) | ✅ |
| 🟠 | [アクセサリーセット（頭部）](https://makerworld.com/ja/models/979116) | 🎀頭部アクセ複数 | CC BY-NC | [ku-nel](https://makerworld.com/en/@user_93648059) | ✅ |
| 🟠 | [Eridian Xenolite body cover](https://makerworld.com/ja/models/3013279) | 🧊ボディカバー | CC BY-NC | [kenichi](https://makerworld.com/en/@kenichi) | ✅ |
| 🟠 | [ServoBodycover](https://makerworld.com/ja/models/2904501) | 🧊ボディカバー（サーボ） | CC BY-NC | [user_2302219760](https://makerworld.com/en/@user_2302219760) | ✅ |
| 🟠 | [Stackchan Pendant Top](https://makerworld.com/ja/models/3022476) | 📿ペンダント | CC BY-NC-SA | [user_2722792563](https://makerworld.com/en/@user_2722792563) | — |
| 🟠 | [顔パーツ・耳カラー（sample piece）](https://makerworld.com/ja/models/1145027) | 🐱顔/耳 | CC BY-NC-SA | [kennel.org](https://makerworld.com/en/@kennel.org) | ✅ |
| 🟠 | [M5StackChanカバー（前面パネル無](https://makerworld.com/ja/models/2817922)／[有）](https://makerworld.com/ja/models/2817921) | 🧊ケース2種 | MakerWorld標準 | [ku-nel](https://makerworld.com/en/@user_93648059) | ✅ |
| 🟠 | [StackChan simple headphone](https://makerworld.com/ja/models/2792626) | 🎧ヘッドホン | MakerWorld標準 | [user_3807793624](https://makerworld.com/en/@user_3807793624) | ✅ |

### 🔴 展示非推奨（版権パロディ・3件）

他作品のパロディ造形のため、コミュニティ展示でも**ブースでは扱いません**（参考として記録のみ）。

| アクセサリー | 元ネタ | ライセンス | 制作者 |
|---|---|---|---|
| [Saint Seiya decoration](https://makerworld.com/ja/models/2736950) | 聖闘士星矢 | CC BY-SA | M5Stack公式 |
| [スーパーサイヤ スタックチャン](https://makerworld.com/ja/models/2834877) | ドラゴンボール | CC BY-NC-SA | ku-nel |
| [ミックチャンなりきりセット](https://makerworld.com/ja/models/2777168) | 初音ミク | CC BY-NC | sugamo |

::: warning ライセンスの見方（重要）
- **CC0**＝権利放棄・制約なし ／ **CC BY**＝クレジットのみでOK ／ **CC BY-SA**＝改変配布は同ライセンス継承 ／ **CC BY-NC・BY-NC-SA**＝非商用のみ（当ブースの無料展示はOK・**物販不可**）。
- **「MakerWorld標準ライセンス」「MakerWorld限定ライセンス」**＝個人・非商用の印刷は可だが**データ再配布・商用は不可**。当ブース（無料展示・データ再配布なし）は範囲内。
- いずれも**クレジット表示**を行い、方針どおり可能な範囲で作者へも一報します。詳細は [`research/makerworld-survey-20260713.md`](https://github.com/aieo-product/stackchanEventBooth/blob/main/research/makerworld-survey-20260713.md) / [`research/model-data.md`](https://github.com/aieo-product/stackchanEventBooth/blob/main/research/model-data.md)。
:::

## 着せ替えアクセサリーの造形データ（データを確認 → 許諾へ）

**本体に装着する着せ替えアクセサリー**の3Dモデルデータ配布元・制作者・ライセンスです。**データを確認したうえで各作者に許諾を得て** 使用します。会場（お誕生日会2026）で配布された **透明シェル・猫耳** は MakerWorld に無く（BOOTH/GitHub/直接配布）、制作者が明確なため許諾依頼の最優先とします。

| 着せ替えアクセサリー | 制作者 | ライセンス/入手 | データ・出典 |
|---|---|---|---|
| 🫧 透明シェル／着せ替えケース | [@mongonta555](https://x.com/mongonta555)（Takao）| 要確認（会場配布）| [交換手順資料(SpeakerDeck)](https://speakerdeck.com/mongonta0716) |
| 🐱 猫耳（LED・透明PLA製）| [@murasametech](https://x.com/murasametech) / [@mongonta555](https://x.com/mongonta555) | 要確認（会場配布）| 「猫耳を付けさせる会」（X投稿）|
| 🎧 ヘッドホン | sskw | CC BY-NC-SA | [MakerWorld](https://makerworld.com/ja/models/2858793-stack-chan-headphone) |
| 🎩 帽子ジェネレータ（カスタム帽子）| beavers_hive | CC BY | [MakerWorld](https://makerworld.com/ja/models/2772131-stackchan-custom-hat-generator) |
| 👒 麦わら帽子ほか | [@mmmzhstd](https://x.com/mmmzhstd)（翼）| 要確認 | X投稿（着せ替え例）|
| 🧥 ファー帽子・マント | [@syumme](https://x.com/syumme)（≒syumme01?）| 要確認 | X投稿（着せ替え衣装）|
| 🐱 顔パーツ・耳カラー（サンプルパーツ）| kennel.org（[@kennel_org](https://x.com/kennel_org)）| CC BY-NC-SA | [MakerWorld](https://makerworld.com/ja/models/1145027-stack-chan_sample_piece) |

::: tip ライセンスとブース利用
本ブースは **非商用のコミュニティ展示**。CC BY/BY-SA/BY-NC/BY-NC-SA いずれも展示・印刷は概ね可能な範囲ですが、**NC＝物販/有償頒布は不可**、**SA＝改変配布は同ライセンス継承**。方針どおり **各作者に許諾** を取ります。詳細は [`research/model-data.md`](https://github.com/aieo-product/stackchanEventBooth/blob/main/research/model-data.md)。
:::

## その他の造形（着せ替えではないもの）

以下は #ｽﾀｯｸﾁｬﾝお誕生日2026 で見られた造形ですが、**本体に装着する着せ替えアクセサリーではない**ため、今回の「お着替え体験」の対象外として区別します（キーホルダー等は配布品として別途検討）。

| 造形 | 制作者 | 種別 |
|---|---|---|
| OpenCar with toio / atom mate マウント | [@kenichih](https://x.com/kenichih) | 台車・マウント |
| 移動スタックチャン各種 | [@hfujikawa77](https://x.com/hfujikawa77) | 乗り物 |
| ミニスタックチャン キーホルダー | [@mongonta555](https://x.com/mongonta555) | ミニチュア配布品 |
| QR顔タグ / MakerChip / バッジ / コースター | [@kennel_org](https://x.com/kennel_org) / [@uk59](https://x.com/uk59) / [@washishi](https://x.com/washishi) | 名札・記念品 |
| スタックチャン BOX / 台座 Car-stom | sugamo / Tanipochi（MakerWorld）| 収納・スタンド |

## 取り扱いの約束

- 画像・造形データは制作者の権利物です。**無断転載・無断印刷は行いません。**
- ライセンス（CC-BY / CC-BY-NC / 独自配布条件）を確認し、クレジット表記の要望に従います。
- 本ブースは非商用のコミュニティ展示です。各制作者の意向を最優先します。

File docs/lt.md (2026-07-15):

# LT（ライトニングトーク）企画

当日行う **15分LT** の企画・構成・進め方をまとめます。テーマは
**「スタックチャンの歴史 → Module-LLMの苦労話 → ローカルLLM実装の最前線（A-Utaさん）」**。

::: tip 🎤 2人リレー形式（メインは A-Uta さん）
[@UtaAoya](https://x.com/UtaAoya)（A-Utaさん）の **ローカルLLMスタックチャン展示**（[出典ポスト](https://x.com/UtaAoya/status/1997262915846705625)）を**メインパート**に据え、
大谷が「歴史 → Module-LLMの苦労」で前フリして**最後にバトンタッチ**する構成です。
:::

::: tip 🖥️ スライド本体（リッチHTML・そのまま投影可）
**<a href="/slides/lt.html" target="_blank">/slides/lt.html を開く</a>**（別タブ）
CDN非依存の**自己完結HTML**なので、会場のWi-Fi不調でも**オフラインで動作**します。`←/→`・スペースでめくり、`F`で全画面、`P`でPDF出力。
:::

## 狙い・ターゲット

- 来場者の**大多数はスタックチャンを知らない**前提で、「**スタックチャンとは何か**」から入る。
- 「クラウドAI頼み → **オンデバイス/ローカルAI**」という時代の流れを、**2人の実践**で立体的に見せる。
- 大谷パートは A-Uta さんパートの**前フリ**：オンデバイスAI（Module-LLM）の苦労と限界を正直に語り、「では**全部ローカル**でどこまでできる？」という問いでバトンを渡す。
- メインは A-Uta さんの **CPU/NPU/GPU分散処理によるフルローカル実装**（Whisper + gpt-oss-20b(FLM) + LLM2、EVO X2 + RTX 5070Ti ×2 OCuLink）。

::: tip キーメッセージ
**AIに顔と声と体を与える挑戦は、クラウド頼みから "全部ローカル" の時代へ。**
:::

## 15分の時間配分（2人リレー）

| # | パート | 話者 | 目安 | 要点 |
|---|---|---|--:|---|
| 1 | オープニング・地図 | 大谷 | 1分 | 2人リレーの構成と「クラウド→ローカル」の流れを提示 |
| 2 | スタックチャンの歴史 | 大谷 | 3分 | OSSのカワイイロボット・5歳・2021→2026年表・なぜ"物理"か |
| 3 | Module-LLMの苦労話 | 大谷 | 3分 | 動かすまでが地獄（UART/マイク/沈黙）・7秒の沈黙・二刀流の現在地 |
| 4 | **バトンタッチ** | 大谷 | 0.5分 | 「全部ローカルでどこまで会話できる？」→ A-Utaさん紹介 |
| 5 | **ローカルLLM実装 ★メイン** | **A-Utaさん** | **6.5分** | AIｽﾀｯｸﾁｬﾝミニマル・CPU/NPU/GPU分散・EVO X2+RTX5070Ti×2・デモ |
| 6 | まとめ・ブース誘導 | 両名 | 1分 | 「AIの体は選べる時代へ」＋実機に会いに来てね |

> 合計15分。**A-Utaさんパート（第5章）が山場**。大谷パートは前フリに徹し、時間が押したら歴史（第2章）を削る。スライドは全20枚。

## 大谷パートの素材：Module-LLM苦労話（実話・出典付き）

実開発リポジトリ [aieo-product/aieo-stack-chan](https://github.com/aieo-product/aieo-stack-chan) の実issueをそのまま使う。

| 苦労 | 内容 | 出典(issue) |
|---|---|---|
| 動かすまで① | CoreS3 ↔ Module-LLM の UART 疎通から一苦労 | #29 |
| 動かすまで② | マイクのゲイン設定が**再起動で消える**（boot永続化が必要） | #76 |
| 動かすまで③ | 音声入力が「入力待ち」のまま**黙り込む**取り込み障害 | #127 |
| 動かすまで④ | 日本語オンデバイスTTS（MeloTTS/NPU）への道が険しい | #55 / #67 / #69 |
| レイテンシー | クラウド往復7秒 → Haikuで5秒 → 間つなぎで体感1秒 | #54 / #70 / #71 / #87 |

> オチ：「オンデバイスAIは、動けば速い。動かすまでが地獄」。それでも二刀流（速い脳×賢い脳）で沈黙は消せた。**ただし賢さの本体はまだクラウド頼み**——この"正直な現在地"が A-Uta さんへの前フリになる。

## メインパートの素材：A-Utaさんのローカル LLM 実装

[出典ポスト（2025-12-06・#ローカルAIに向き合う展示会）](https://x.com/UtaAoya/status/1997262915846705625)より：

- **AI ｽﾀｯｸﾁｬﾝ ミニマル** — ネット接続なしで音声会話
- 分散処理：**CPU = Whisper（音声認識）／ NPU = LLM1: gpt-oss-20b（FLM）／ GPU = LLM2**
- ハードウェア：**EVO X2 + RTX 5070Ti ×2（OCuLink経由）**
- **スマホ版は全部CPU** で動かす割り切り構成

::: warning A-Utaさんとの調整事項
- スライドのメインパート（15〜18枚目）は**ポスト内容ベースのドラフト**。A-Utaさん本人に内容確認・差し替えを依頼する。
- 18枚目「実装の流れ・デモ」は**丸ごと差し替え前提**のプレースホルダ。
- 持ち時間（5〜6.5分）・デモの有無・録画バックアップの要否を事前にすり合わせる。
:::

## スライドの作り方・進め方

スライドは **リッチHTML**（[`docs/public/slides/lt.html`](https://github.com/aieo-product/stackchanEventBooth/blob/main/docs/public/slides/lt.html)）を正とします。1ファイル自己完結で**オフライン投影可**、公開サイトからも **[/slides/lt.html](/slides/lt.html)** で開けます。

- **投影**：ブラウザで開いて `F` で全画面。`←/→`・スペースでめくる。タッチスワイプ対応。
- **編集**：HTMLを直接編集（各スライドは `<section class="slide">`）。制作写真は `docs/public/slides/assets/`。
- **PDF化**：ブラウザで `P`（印刷→PDFで保存）。または Chromeヘッドレスで書き出し可。

```bash
# PDF書き出し（Chromeヘッドレス・任意）
"/Applications/Google Chrome.app/Contents/MacOS/Google Chrome" \
  --headless=new --print-to-pdf=lt.pdf --no-pdf-header-footer \
  "http://localhost:5173/slides/lt.html"   # ローカル配信 or 公開URLでも可
```

> 旧Marp版 [`slides/lt-stackchan-ai-agent.md`](https://github.com/aieo-product/stackchanEventBooth/blob/main/slides/lt-stackchan-ai-agent.md) は<b>旧構成（電子工作素人の苦労話＋レイテンシー主役）</b>のまま残置。内容の正はHTML版。

### これから詰める作業（チェックリスト）

- [ ] **A-Utaさんにメインパート（15〜18枚目）の内容確認・差し替え**を依頼（持ち時間・デモ有無も）
- [ ] A-Utaさんの**展示写真・アーキ図**を提供してもらいメインパートに差し込む
- [ ] **リハーサルで15分に収める**（バトンタッチの段取り含む。押したら歴史パートを削る）
- [ ] 可能なら**ライブデモ**（実機で1往復）。失敗に備え**録画バックアップ**を用意
- [ ] 会場PCで**事前に表示確認**（フォント・全画面・めくり）

::: warning 当日の保険
会場は混雑Wi-Fiが想定される（[懸念点](/concerns)）。大谷側のクラウド連携デモはネット不調で失敗し得るため、🟡Degradedモードまたは**録画**を用意。
A-Utaさん側は**フルローカルなのでネット不要**——むしろ本構成の強みとして紹介できる。
:::

## 関連

- 🖥️ **スライド本体（リッチHTML）**: [/slides/lt.html](/slides/lt.html)
- A-Utaさんの出典ポスト: [x.com/UtaAoya/status/1997262915846705625](https://x.com/UtaAoya/status/1997262915846705625)
- スライド旧版（Marp・旧構成）: [`slides/lt-stackchan-ai-agent.md`](https://github.com/aieo-product/stackchanEventBooth/blob/main/slides/lt-stackchan-ai-agent.md)
- 実開発リポジトリ: [aieo-product/aieo-stack-chan](https://github.com/aieo-product/aieo-stack-chan)
- ブースのアイディア（LLM Moduleデモ）: [/ideas](/ideas)
- 事前に潰す懸念点（ネットワーク）: [/concerns](/concerns)

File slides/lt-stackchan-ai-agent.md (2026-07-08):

---
marp: true
theme: default
paginate: true
size: 16:9
title: スタックチャンとAIエージェント
description: AI Dev Day 2026 LT｜歴史と実践（レイテンシーとの戦い）
footer: "AI Dev Day 2026 ｜ aieo ｜ #ｽﾀｯｸﾁｬﾝお誕生日2026"
---

<!--
15分LT用スライド（Marp）。
レンダリング: npx @marp-team/marp-cli@latest slides/lt-stackchan-ai-agent.md -o out.pdf
（--pptx でPowerPoint、--html でHTML）。各スライドの <!-- --> はプレゼンター用メモ。
時間配分の目安は docs/lt.md を参照。
-->

<style>
section {
  font-family: "Hiragino Sans", "Noto Sans JP", sans-serif;
  font-size: 30px;
}
section.lead h1 { font-size: 54px; line-height: 1.25; }
section.lead { text-align: center; }
h1, h2 { color: #1D76DB; }
section.section { background: #1D76DB; color: #fff; text-align: center; }
section.section h1, section.section h2 { color: #fff; }
strong { color: #1D76DB; }
section.section strong { color: #ffe08a; }
table { font-size: 26px; }
.big { font-size: 46px; font-weight: 700; color:#1D76DB; }
.muted { color:#667; font-size: 24px; }
</style>

<!-- _class: lead -->

# スタックチャンと<br>AIエージェント

### 〜 自分で育てた"相棒"が物理世界に立つまで 〜

<br>

**AI Dev Day 2026 ｜ Lightning Talk**
大谷 / aieo

<!--
つかみ：「今日は、AIエージェントを"画面から出す"話をします」。
5歳の誕生日を迎えたスタックチャンと、実際にLLMで会話させて苦労した話。
-->

---

## このトークのゴール（15分）

- 🧸 **スタックチャンって何？**（知らない人が大多数、の前提で）
- 🗣️ **AIエージェントと"会話"するには？**（仕組みの全体像）
- ⚡ **実践の苦労＝レイテンシーとの戦い**（実開発の生々しい話）

<br>

> キーメッセージ：**育てたAIエージェントが、顔と声と体を持つと"相棒"になる**

<!--
自己紹介は一言。aieoでスタックチャン×Module-LLMを開発中。
「歴史 → 実践」の流れで話します、と地図を見せる。
-->

---

<!-- _class: section -->

# ① そもそも、<br>スタックチャンとは？

---

## スタックチャン＝カワイイOSSロボット

<div style="display:flex;gap:24px;align-items:center;">
<div style="flex:1.1;">

- **M5Stack** ベースの**手乗りサイズ**の卓上ロボット
- 首を振り・**表情**を出し・**しゃべる**
- **2021年** ししかわさん([@meganetaaan](https://x.com/meganetaaan))が公開
- **オープンソース** → 世界中が改造・着せ替え・AI化
- 2026年7月2日で **5歳のお誕生日** 🎂

</div>
<div style="flex:0.9;">

w:360

</div>
</div>

<!--
「スーパーカワイイ手乗りロボット」。写真を見せて、まず"存在"を知ってもらう。
自作できる・安い・改造自由、が愛される理由。
-->

---

## なぜこんなに愛されるのか

- 💴 **安い・作れる・改造できる**（OSS＋M5Stack）
- 😊 **"顔"がある** → 道具ではなく"存在"として愛着がわく
- 🎉 **コミュニティ文化**：お誕生日会・着せ替え・撮影ブース

<br>

<span class="muted">※ このブースも、コミュニティの着せ替え文化から生まれています</span>

<!--
ブースの文脈にもつなぐ。着せ替え・撮影ブースはコミュニティ由来。
-->

---

<!-- _class: section -->

# ② スタックチャンの歴史<br><span style="font-size:32px">2021 → 2026、AIとの合流</span>

---

## 歴史：カワイイロボット → 会話するAI

| 時期 | できごと |
|---|---|
| **2021** | 誕生。サーボ2個で首振り・M5Stackの"顔" |
| **2022–23** | コミュニティ拡大。**ChatGPT連携**で"しゃべる"化 |
| **2024–25** | LLM高性能化。**音声対話**が実用域に |
| **2026** | M5公式版 **スタックチャン(K151)** 発売 ／ **Module-LLM**（オンデバイスLLM）登場 |

<br>

→ いま：**クラウドAI × オンデバイスAI** の二刀流時代へ

<!--
歴史の山場は「AI連携で"ただのカワイイ置物"から"会話する相棒"に変わった」点。
2026にオンデバイスLLM(Module-LLM)が来て、ネット無しでも喋れる時代に。
-->

---

<!-- _class: section -->

# ③ なぜ"物理"なのか<br><span style="font-size:32px">AIエージェントを画面から出す価値</span>

---

## 育てたエージェントが"体"を持つと

<div style="display:flex;gap:20px;">
<div style="flex:1;">

**画面の中だけ**
- 便利な"道具"どまり
- 呼んでも"そこに居ない"

</div>
<div style="flex:1;">

**顔・声・体を持つと**
- 呼べば**振り向く**
- そこに**"居る"**＝相棒
- 育てた記憶・性格が**物理世界に立つ**

</div>
</div>

<br>

<div class="big" style="text-align:center;">AIエージェントを"育てた先"に見える、フィジカルな世界観</div>

<!--
ブースのコンセプトそのもの。「自分で育てたAIエージェントが、物理的に呼び出せる」。
ここが今回一番伝えたい世界観。
-->

---

<!-- _class: section -->

# ④ AIエージェントと<br>会話するには？

---

## 会話の4ステップ

<div class="big" style="text-align:center;margin:30px 0;">
🎙️声 → ①聞く(STT) → ②考える(LLM) → ③話す(TTS) → 🔊声
</div>

- 各ステップを **どこで動かすか**（オンデバイス / クラウド）が勝負
- 速さ（オンデバイス）と 賢さ（クラウド）は **トレードオフ**
- この積み重ねが、そのまま **レイテンシー**（返事までの時間）になる

<!--
次の「苦労話」への伏線。4ステップ全部が遅延の積み上げ、と印象づける。
-->

---

## 我々の構成（aieo-stack-chan）

- 🧠 本体：**M5Stack CoreS3 + Module-LLM**（オンデバイスLLM / NPU）
- ☁️ 頭脳：Mac Studio 上の **Claude Agent SDK**
- 🗣️ 声：**VOICEVOX（満別花丸）** で日本語TTS
- 🌐 どこでも：**Tailscale Funnel** で 家 / テザリング / カフェ 同一URL
- 🚦 3モード：🟢**Full** / 🟡**Degraded**（オンデバイスのみ）/ 🔴**Offline**

<br>

<span class="muted">GitHub: aieo-product/aieo-stack-chan</span>

<!--
ハイブリッド構成。ネット状況で3モードに落ちる設計＝ブースの"ネットワーク懸念"への答えでもある。
-->

---

## 鍵は "tiered cognition"（段階的な思考）

- 🟢 **軽い応答・聞き取り**：本体内で完結（**速い**）
- ☁️ **深い思考**：クラウドの Claude（**賢い**）
- 🎭 **顔から声が出る**：入力＝Module-LLMのマイク／出力＝CoreS3のスピーカー

<br>

> 「速い脳」と「賢い脳」を**使い分ける**のが、自然な会話のコツ

<!--
tiered cognition＝人間も「えーっと（即答）」と「よく考えた答え」を使い分ける、の比喩で。
-->

---

<!-- _class: section -->

# ⑤ 実践の苦労<br>レイテンシーとの戦い ⚡<br><span style="font-size:28px">（ここからが本番）</span>

---

## 問題：<span style="color:#d33">"7秒の沈黙"</span>

- 声をかけてから返事まで **7秒**
- 人は **2秒**黙られると「**壊れた?**」と感じる
- STT → LLM → TTS → 音声転送 の**往復が積み上がる**

<br>

| 区間 | 時間 |
|---|---|
| **Claude API（考える）** | **3–4秒** ← 最大のボトルネック |
| その他（聞く・話す・転送）| 3–4秒 |
| **合計** | **約7秒** |

<!--
実測。7秒の沈黙は会話として致命的。ボトルネックはクラウドLLMの往復。
以降、これをどう削ったかを積み上げで見せる。
-->

---

## 対策① モデル選び（7秒 → 5秒）

- **Sonnet → Haiku 4.5** に切替
- Claude API **3–4秒 → 1–2秒**、合計 **7秒 → 5秒**
- 会話用途では「**そこそこ賢く・速い**」が正解

<div class="muted">issue #54 perf(latency)</div>

<br>

> "一番賢いモデル"が"一番いい会話"とは限らない

<!--
モデル選定は「賢さ vs 速さ」のプロダクト判断。会話は速さの寄与が大きい。
-->

---

## 対策② 全文を待たない（ストリーミングTTS）

- 従来：**全文が返ってから**喋り始める → 長い答えほど遅い
- 改善：**文の区切りごと**に即 合成・発話
- **最初の一文ができた瞬間**に喋り出す

<div class="muted">issue #87 文境界チャンクの即時TTS</div>

<br>

> 「返事の速さ」＝"喋り始め"の速さ。全部できるのを待たない。

<!--
体感レイテンシーは「最初の一言」で決まる。ストリーミングの効果大。
-->

---

## 対策③ "間つなぎ"で沈黙を消す

- 考えている間、**即座に相づち**：「ちょっと待ってね」
- さらに、周囲の会話から**単語抽出**（mecab・オンデバイス・**トークン0**）
  → 文脈を反映：「**今日は東京駅で19時に飲み会**だったよね」
- 事前合成キャッシュで **4秒 → 1秒**

<div class="muted">issue #70 / #71 文脈ワード抽出＋アドホックモード（tiered cognition拡張）</div>

<!--
ここが一番"人間くさい"工夫。人も考える前に「えーっと」と言う。
文脈を拾った間つなぎは"賢く見える"効果も大きい。
-->

---

## 対策④ オンデバイス化 & セッション

- TTSを**オンデバイス（MeloTTS / NPU）**へ → PCM転送 **1–2秒削減**
- **セッション継続 + prompt caching** で起動コスト削減
- ネット不調でも 🟡**Degraded** で会話を止めない

<div class="muted">issue #55 / #56</div>

<!--
オンデバイス化はネット依存も下げる＝ブースの混雑Wi-Fi対策にも効く。
-->

---

## 総力戦：<br>"速く"より"待たせない"

<div class="big" style="text-align:center;margin:24px 0;">
🎙️声 →（即）間つなぎ →（文単位）本答えを発話
</div>

- **速くする**（モデル・オンデバイス）
- ＋ **待ち時間を感じさせない**（間つなぎ・ストリーミング）
- レイテンシーは **数字と体感の両面** で戦う

<!--
まとめの一枚。個々の対策が"沈黙を埋める"総力戦として噛み合う図。
-->

---

<!-- _class: section -->

# ⑥ まとめ

---

## まとめ

- 🧸 スタックチャン＝**カワイイOSSロボット**、5歳、強いコミュニティ
- 🤝 AIエージェントに**顔・声・体**を与えると **"相棒"** になる
- ⚡ 会話の鍵は**レイテンシー**：モデル / ストリーミング / 間つなぎ / オンデバイス の**積み上げ**
- 🌟 **育てたエージェントが物理世界に立つ** ＝ これからの世界観

<!--
30秒で締める。キーメッセージ再掲。
-->

---

<!-- _class: lead -->

## ブースに会いに来てください 🎉

**1F コミュニティショーケース**
着せ替え & 撮影ブース ／ 実機デモ

`#ｽﾀｯｸﾁｬﾝお誕生日2026`

<br>

📄 **stackchan-event-booth.pages.dev**

<!--
CTA。実物を触ってもらうのがゴール。ありがとうございました！
-->

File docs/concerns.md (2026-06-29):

# 懸念点・事前に解決したいこと

当日を楽しく成功させるために、**事前に潰しておきたいリスク**を一覧化します。新しい懸念が出たらこのページに追記していきます。

## 懸念点メニュー

| # | 懸念点 | 重要度 | 状態 | 関連 |
|---|---|:--:|---|---|
| C-1 | [スタックチャンのネットワーク接続問題（Wi-Fi）](#c-1-ネットワーク接続問題) | 🔴 高 | 要対策 | [Issue #9](https://github.com/aieo-product/stackchanEventBooth/issues/9) |

> 💡 懸念が増えたらこの表に行を追加し、下に詳細セクションを足します。

---

## C-1. ネットワーク接続問題

### 何が問題か

- 多くのスタックチャンは **ネット接続を前提に会話**（クラウドのLLM/音声認識/音声合成を利用）しています。当日、来場者と楽しく交流するには **Wi-Fi共有がほぼ必須** です。
- **人が多い会場はネットワークが混雑・輻輳しやすく**、つながらない／遅延が大きいといったトラブルが起きがちです。本番で困らないよう **事前に解決** しておきたい点です。

### 影響

- 会話デモが止まる／極端に遅くなる → 体験の質が大きく低下
- 複数台のスタックチャン＋来場者スマホで **同時接続数・帯域** を圧迫

### 対策案

| 対策 | 内容 | 備考 |
|---|---|---|
| 会場Wi-Fiの事前確認 | 提供有無・帯域・**同時接続上限**・5GHz対応を主催/会場に確認 | まず確認すべき最重要事項 |
| モバイルルーター持込 | 自前回線を用意し会場網に依存しない | 大手町＝地下/混雑で電波状況の事前テスト推奨 |
| 有線接続の確保 | 可能なら有線LAN/USBテザリングで安定化 | ブース位置で配線可否を確認 |
| **オンデバイスLLMで依存を低減** | M5Stack **LLM Module** 等で **ローカル会話**（ネット不要・低遅延）| → [アイディア I-1](/ideas#i-1-llm-module-デモ) と直結 |
| ネット不要の動作も用意 | 表情・モーション・定型応答など **オフラインでも成立** する演出を準備 | 通信断時のフォールバック |

### 要確認（主催・会場へ）

- [ ] 会場Wi-Fiの提供可否／SSID・帯域／**同時接続数の上限**
- [ ] ブース位置（1F コミュニティショーケース）での電波状況
- [ ] モバイルルーター／有線の持込可否
- [ ] 来場者にもWi-Fiを使わせる場合の運用（QR掲示など）

> 詳細・進捗は [Issue #9](https://github.com/aieo-product/stackchanEventBooth/issues/9) で管理します。

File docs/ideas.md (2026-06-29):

# アイディア・やりたいこと

「ただのブース」で終わらせず、**来場者が驚き・楽しめる仕掛け**を貯めていくページです。今後どんどん追加していく想定です。

## アイディアメニュー

| # | アイディア | 種別 | 状態 | 関連 |
|---|---|:--:|---|---|
| I-1 | [大谷所有スタックチャンで会話デモ（LLM Module 低レイテンシー）](#i-1-llm-module-デモ) | デモ | 構想 | [Issue #10](https://github.com/aieo-product/stackchanEventBooth/issues/10) |
| I-2 | [当日イベント案内・同フロア連携の応答](#i-2-イベント案内同フロア連携) | 体験 | 構想 | [Issue #10](https://github.com/aieo-product/stackchanEventBooth/issues/10) |

> 💡 新しいアイディアはこの表に行を追加し、下に詳細を書いていきます。

---

## I-1. LLM Module デモ

### やりたいこと

- 着せ替え展示だけだと物足りないので、**大谷所有のスタックチャンで会話デモ**をしたい。
- 理想は **M5Stack LLM Module による低レイテンシー会話**。**オンデバイス（ローカル）推論**なので、応答が速く、**ネット接続への依存も下げられる**。

### なぜ良いか

- 来場者が「**その場で話しかけて返ってくる**」体験は強い引き（撮影だけより滞在価値UP）
- ローカル動作のため、混雑会場でも **ネットワーク問題（[C-1](/concerns#c-1-ネットワーク接続問題)）の影響を受けにくい**

### 検討事項

- LLM Module の応答品質・速度の事前検証（音声入出力含む）
- マイク/スピーカーの会場ノイズ対策（騒がしい会場での音声認識）
- クラウドLLMとのハイブリッド（ローカル優先・必要時のみクラウド）

## I-2. イベント案内・同フロア連携

### やりたいこと

- スタックチャンの **応答内容で「当日のイベント案内」** をしたい（例：「次のセッションは○○、△△は13:30からです」）。
- さらに **同フロア内のコミュニティ／ブースと連携** した案内（例：「隣のブースでは□□をやっています」「2Fの○○もおすすめ」）。

### なぜ良いか

- スタックチャンが **会場の“案内役”** になり、ブースの存在価値が上がる
- 同フロアの他コミュニティと **相互送客** でき、ショーケース全体を盛り上げられる

### 検討事項

- 当日タイムテーブル・フロアマップを応答データとして用意（[AI Dev Day 2026](https://aidevday.com/) 公式情報）
- 案内内容の更新方法（直前変更への対応）
- 他コミュニティへの連携可否・掲載許可の確認

---

> アイディアは [Issue #10](https://github.com/aieo-product/stackchanEventBooth/issues/10) で具体化・追跡します。提案歓迎です。

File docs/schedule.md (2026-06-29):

# 当日運営（13:00–17:00）

会場は **1F コミュニティショーケース**。**「コミュニティが1時間シフトで交代」** する運用のため、**1枠＝1時間** を単位に、素早く設営・撤収できる構成にします。

::: warning ⏱ 出展枠は要確認
「1時間枠×複数回」「1回のみ」「13–17通し」のいずれかは主催に確認中です。下記は **1時間枠を複数回担当する場合** を想定したタイムラインです（→ [必要スペース](/space) 参照）。
:::

## タイムライン（1時間枠を想定）

| タイミング | 内容 | 目安時間 |
|---|---|---|
| 枠の開始前 | **搬入・設営**（テーブルにクロス→アクセサリー陳列→撮影ブース展開→実機起動） | **5〜10分** |
| 枠の最初 | 最終チェック（陳列・撮影ブース・掲示物・消毒） | 〜2分 |
| 枠の本番 | 運営（着せ替え対応・撮影サポート・補充・実機メンテ） | 約50分 |
| 枠の終了前 | **撤収**（小物をコンテナへ→次コミュニティへ引き継ぎ） | **5分** |

### 通し（13–17）想定の場合のタイムライン

| 時刻 | 内容 |
|---|---|
| 〜12:30 | 搬入・設営 |
| **13:00** | ブースオープン 🎉 |
| 13:00–17:00 | 運営（適宜アクセサリー補充・実機メンテ）|
| **17:00** | クローズ・撤収開始 |

::: tip 交代運用への対応
- **卓上完結・モジュール化**：アクセサリーはトレイ単位、撮影ブースは折りたたみ式で、**5〜10分で設営/撤収**。
- 折りたたみコンテナ1〜2個に全什器を収納し、交代をスムーズに。
:::

## 来場者の体験フロー

1. 🎀 好きなアクセサリーでスタックチャンを着せ替え
2. 📸 撮影ブースで記念撮影
3. 📲 `#ｽﾀｯｸﾁｬﾝお誕生日2026` で投稿
4. 🎁 （任意）ノベルティ（キーホルダー／ステッカー）

## 運営体制（ドラフト）

- スタッフ **2名以上** を推奨（着せ替え案内係／撮影・投稿サポート係）
- 共用アクセサリーの **衛生対策**（消毒・クリーニング）を運用に組み込み
- 実機スタックチャンは **着せ替え用／撮影用** で複数台用意できると回転が良い

## 備品チェックリスト（抜粋）

- [ ] テーブル・テーブルクロス
- [ ] 実機スタックチャン本体 ×複数
- [ ] 電源タップ・モバイルバッテリー
- [ ] アクセサリー収納ケース・トレイ
- [ ] 消毒・クリーニング用品
- [ ] 撮影ブース一式・卓上照明
- [ ] 掲示物（タイトル看板・体験フロー・ハッシュタグ・クレジットQR）
- [ ] 予備フィラメント・簡易工具

> 詳細な備品・体制は GitHub Issue [#6](https://github.com/aieo-product/stackchanEventBooth/issues/6) で管理しています。

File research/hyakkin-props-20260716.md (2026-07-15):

# 撮影ブース用 100円ショップ調達品調査（2026-07-16）

- 調査方法: ダイソーネットストア・キャンドゥネットショップ・ワッツオンラインの商品ページを直接確認（価格・サイズ・URL）。セリアは公式ECがないため対象外（店頭確認推奨）
- 用途: 撮影ブース「教室でお誕生日会」ジオラマ（ステージW600×D300・スタックチャン身長6cm≒1/12スケール）の装飾・小物・撮影環境
- 反映先: [docs/photobooth.md](../docs/photobooth.md) 装飾リスト / [Issue #13](https://github.com/aieo-product/stackchanEventBooth/issues/13)

## A. お誕生日・パーティ装飾（背景・壁パネル）

| 商品名 | 価格(税込) | URL | 所見 |
|---|--:|---|---|
| ハッピーバースデーガーランド | ¥110 | [daisonet 4549892413001](https://jp.daisonet.com/products/4549892413001) | 全長約142cm紙製。背面壁W600の上部にちょうど良い |
| ケーキトッパー（Happy Birthday） | ¥110 | [daisonet 4550480214283](https://jp.daisonet.com/products/4550480214283) | 8.9〜14cm。机上・ケーキ横のサブ小物 |
| ペーパーファン・ボールセット | ¥110 | [daisonet 4550480386584](https://jp.daisonet.com/products/4550480386584) | 吊り下げで奥行き演出 |
| フェルトガーランド BIRTHDAY | ¥110 | [cando 000000011565](https://netshop.cando-web.co.jp/view/item/000000011565) | 約150cm・フェルトの手作り感 |
| 光るガーランド（ハッピーバースデー） | 要確認 | [daisonet 4549892409158](https://jp.daisonet.com/products/4549892409158) | LED内蔵・電池式。電池ボックスの隠し場所要検討 |
| ガーランドフラッグ バースデー | ¥110目安 | [cando 000000015831](https://netshop.cando-web.co.jp/view/item/000000015831) | 小型。棚・机まわり |

## B. ミニチュア小物（1/12前後）

| 商品名 | 価格 | URL | 所見 |
|---|--:|---|---|
| ミニチュア リビングテーブル | ¥110 | [daisonet 4965534119917](https://jp.daisonet.com/products/4965534119917) | 7.9×3.7×4.3cm・1/12。6cmスタックチャンと好相性 |
| ミニチュア（パン屋さん） | ¥550 | [daisonet 4550480433516](https://jp.daisonet.com/products/4550480433516) | レジ台・陳列棚・パンのセット。購買部コーナー演出 |
| ミニチュア食器 ホワイト／クリア | 各¥110 | [4965534322621](https://jp.daisonet.com/products/4965534322621) / [4965534402613](https://jp.daisonet.com/products/4965534402613) | 1/12食器。給食・お誕生日会のテーブルに |
| ミニチュア シェルソファ | ¥110 | [daisonet 4965534166713](https://jp.daisonet.com/products/4965534166713) | 休憩コーナー |
| ミニチュア 保健室のベッド | ¥110目安 | [daisonet 4965534167611](https://jp.daisonet.com/products/4965534167611) | **学校モチーフで世界観に最適** |
| ミニチュア ダイニングチェア | ¥110 | [daisonet 4965534322911](https://jp.daisonet.com/products/4965534322911) | 机とセットで増員 |

## C. 背景・床の質感補助

| 商品名 | 価格 | URL | 所見 |
|---|--:|---|---|
| リメイクシート（木目柄ライトブラウン） | ¥110目安 | [daisonet 4550480022499](https://jp.daisonet.com/products/4550480022499) | 90×30cm。3Dプリント床の補助・テーブル面の拡張 |
| フェイクグリーン（ヤドリフカノキ） | ¥330 | [daisonet 4550480579313](https://jp.daisonet.com/products/4550480579313) | 21×23×20cm。窓際の観葉植物（教室の背の高い鉢植え相当） |
| 芝生調シート（シール式） | ¥110 | [daisonet 4991203188373](https://jp.daisonet.com/products/4991203188373) | 窓の外・校庭コーナーの床材 |
| ジオラマ情景（草・夏の草原色） | ¥110目安 | [daisonet 4550480141893](https://jp.daisonet.com/products/4550480141893) | 鉄道模型素材。植木鉢の土・花壇表現 |
| グリーンガーランド（アイビー約3m） | 要確認 | [watts 21851](https://watts-online.jp/products/21851) | 壁上部の緑化 |
| グリーンマットバイン | ¥110目安 | [watts 4733](https://watts-online.jp/products/4733) | 棚・卓上ワンポイント |

## D. 撮影環境・固定

| 商品名 | 価格 | URL | 所見 |
|---|--:|---|---|
| 3LEDプッシュライトミニ | ¥110 | [daisonet 4972822311144](https://jp.daisonet.com/products/4972822311144) | 単3×3・連続約30h。撮影補助照明 |
| ゲル両面テープ | ¥110 | [daisonet 4550480071145](https://jp.daisonet.com/products/4550480071145) | 耐荷重500g/10cm。**ミニチュア転倒防止の仮固定**（ミュージアムジェル代替） |
| 耐震マット（4枚） | ¥110 | [daisonet 4549131944020](https://jp.daisonet.com/products/4549131944020) | 観覧車ベース・照明の固定にも |
| 発泡なんでも板 A2 | ¥110 | [daisonet 4984343618190](https://jp.daisonet.com/products/4984343618190) | 60×42×1.2cm。土台補強・搬送時の緩衝 |
| クリアイーゼル | ¥110〜220 | [daisonet 4550480163284](https://jp.daisonet.com/products/4550480163284) | ハッシュタグ・推奨アングル掲示立て |
| テープライト リモコン付（30LED） | 要確認 | [daisonet 4972822810296](https://jp.daisonet.com/products/4972822810296) | 壁縁の雰囲気照明（CR2025） |

## 所見

- **1回の買い出しならダイソー1店でほぼ全カテゴリが揃う**（神田周辺に複数店舗）。キャンドゥのフェルトガーランド・ワッツのアイビーは質感で追加検討
- セリアはEC非対応のためリンクなし。ミニチュア雑貨が充実しているので、ダイソーで欠品時の第2候補として店頭確認
- 予算目安: **20点で約¥3,000〜4,000**
- 価格未確定3点（光るガーランド・テープライト・アイビー）は購入前に再確認

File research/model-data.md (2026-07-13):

# 造形データ配布元・ライセンス（深掘り調査）

「**データを確認 → 作者へ許諾**」を進めるための、実際の3Dモデルデータ配布元リスト。プラットフォーム上の作者・ライセンス・URLを特定し、対応するX制作者に紐付ける。

- 関連Issue: [#2](https://github.com/aieo-product/stackchanEventBooth/issues/2)
- 調査日: 2026-07-03 / 方法: Chrome自動操作（MakerWorld `tag:stack-chan` / `tag:stackchan` 等）＋Web検索
- ライセンス確認済みは MakerWorld のモデルページ表記に基づく
- **更新調査**: [makerworld-survey-20260713.md](./makerworld-survey-20260713.md)（2026-07-13・全33件）— 本書で「要確認」のライセンスが判明（ku-nelカバー=MW標準 / BOX=CC0 / Car-stom=MW限定）

## MakerWorld（データDL可・ライセンス明記）

| # | 造形（種類）| 作者(MakerWorld) | ライセンス | データURL |
|---|---|---|---|---|
| 1 | Stack-chan **サンプルパーツ**（顔パーツ・耳カラー等）| **kennel.org**（＝X:@kennel_org）| **CC BY-NC-SA** | [models/1145027](https://makerworld.com/ja/models/1145027-stack-chan_sample_piece) |
| 2 | 🎧 **スタックちゃんヘッドホン** | **sskw** | **CC BY-NC-SA** | [models/2858793](https://makerworld.com/ja/models/2858793-stack-chan-headphone) |
| 3 | 🔑 スタックちゃん **クレーンゲームアクセサリー**（タグ/キーホルダー）| sskw | **CC BY-SA** | [models/564419](https://makerworld.com/ja/models/564419-stack-chan-crane-machine-accessory) |
| 4 | 🎩 スタックチャン **custom hat generator**（帽子ジェネレータ）| beavers_hive | **CC BY** | [models/2772131](https://makerworld.com/ja/models/2772131-stackchan-custom-hat-generator) |
| 5 | 🧊 **M5StackChanカバー**（フロントパネルなし）| user_93648059 | 要確認 | [models/2817922](https://makerworld.com/ja/models/2817922-m5stackchan-cover-no-frontpanel) |
| 6 | 🚗 **OpenCar with toio**（台車・baseIdeaのQRカード）| **kenichi**（ken-ichi）| **CC BY-NC** | [models/2922441](https://makerworld.com/ja/models/2922441-stack-chan-opencar-with-toio) |
| 7 | スタックチャン **BOX** | sugamo | 要確認 | [models/2750877](https://makerworld.com/ja/models/2750877-stackable-box) |
| 8 | 台座「Car-stom」for タカオ版ボディ | Tanipochi | 要確認 | [models/2781106](https://makerworld.com/ja/models/2781106-stack-chan-base-car-stom-custom-for-takao-version) |
| 9 | toio用 Atom mate マウント | kenichi | 要確認 | [models/530912](https://makerworld.com/ja/models/530912-atom-mate-for-toio-mount-for-toio-core-cube) |

> MakerWorld一覧: [tag:stack-chan](https://makerworld.com/ja/search/models?keyword=tag%3A+stack-chan) / [tag:stackchan](https://makerworld.com/ja/search/models?keyword=tag%3A+stackchan)

## BOOTH / GitHub（その他の配布元）

| 配布元 | 内容 | 作者 | 条件 |
|---|---|---|---|
| [mongonta.booth.pm](https://mongonta.booth.pm/)（Arpeggio Factory）| タカオ版ケースセット・スタンドSTL 等 | タカヲ/Takao（X:@mongonta555）| BOOTH（有料/一部STL配布・規約準拠）|
| [booth 3771954](https://booth.pm/ja/items/3771954) | Core2分解不要の組立オプションSTL | First DIY | BOOTH |
| [github.com/m5stack/StackChan](https://github.com/m5stack/StackChan) | 本体の3Dデータ（公式・OSS）| M5Stack/community | リポジトリのライセンス |

## X制作者 → データ配布元の紐付け

| X制作者 | 配布元・データ | 状態 |
|---|---|---|
| @kennel_org | MakerWorld **kennel.org** サンプルパーツ（CC BY-NC-SA）| ✅ 特定 |
| @uk59（くうねる）| MakerWorld **MakerChip**（QRチップ）形式で配布。個別モデルはプロフィール要確認 | 🔎 要確認 |
| @UtaAoya（A-Uta）| 「ミニマル(スマホ版)ケース」配布先（MakerWorld/booth）| 🔎 要確認 |
| @mongonta555（Takao）| mongonta.booth.pm / GitHub | ✅ 特定 |
| sskw（MakerWorld）| ヘッドホン/クレーンアクセ。X handle | 🔎 要確認 |
| kenichi（MakerWorld）| OpenCar with toio。X handle（baseIdeaカードは @kenichi 表記）| 🔎 要確認 |
| @k8ark | 撮影ブース（造形データではなくジオラマ演出）| — |

## ライセンス別・ブース利用の考え方（※最終は各作者へ確認）

| ライセンス | 表示 | 非商用 | 継承(SA) | ブース（非商用展示）での目安 |
|---|:--:|:--:|:--:|---|
| CC BY | 必要 | 制限なし | — | 展示・印刷OK（クレジット必須）|
| CC BY-SA | 必要 | 制限なし | あり | OK。改変配布は同ライセンス継承 |
| CC BY-NC | 必要 | **非商用のみ** | — | 無料展示はOK。**物販/有償頒布は不可** |
| CC BY-NC-SA | 必要 | **非商用のみ** | あり | 同上＋継承 |

> 本ブースは非商用のコミュニティ展示のため多くは利用可の範囲だが、**方針どおり各作者に許諾を取る**。特に SA（改変時）・NC（物理配布/物販）・独自条件は事前確認必須。

## MakerWorld = X2Dで最速の印刷供給源（2026-07-06 全ライセンス確認）

MakerWorld は Bambu Lab 公式プラットフォーム。多くのモデルに **Print Profile（Bambu向け事前スライス済み3MF）** が付属し、Bambu Studio/Handy から **X2D へワンクリック送信で印刷可能**（＝実質そのまま生成できる）。`__NEXT_DATA__` から全ヒットのライセンスを一括取得した結果、スタックチャンの**着せ替えアクセサリー**は以下（各ページの `license` フィールドより）。

### 着せ替えアクセサリー（印刷対象）

| ID | アクセサリー | 種別 | ライセンス | 作者(uid) |
|---|---|---|---|---|
| [979116](https://makerworld.com/ja/models/979116) | スタックチャン アクセサリーセット/head accessory set | 頭部アクセ複数 | **BY-NC** | user_93648059 |
| [2858793](https://makerworld.com/ja/models/2858793) | Stack-chan headphone | ヘッドホン | **BY-NC-SA** | sskw |
| [2792626](https://makerworld.com/ja/models/2792626) | StackChan simple headphone | ヘッドホン | MakerWorld標準 | — |
| [2772131](https://makerworld.com/ja/models/2772131) | StackChan Custom Hat Generator | 帽子(自由生成) | **BY** | beavers_hive |
| [2855044](https://makerworld.com/ja/models/2855044) | StackChan Brick Hat | ブロック帽子 | **BY-NC** | — |
| [2736962](https://makerworld.com/ja/models/2736962) | Pharaoh decoration of StackChan | かぶりもの | **BY-SA** | — |
| [2834877](https://makerworld.com/ja/models/2834877) | ｽｰﾊﾟｰｻｲﾔｽﾀｯｸﾁｬﾝ | 髪 | **BY-NC-SA** | user_93648059 |
| [3013279](https://makerworld.com/ja/models/3013279) | Eridian Xenolite StackChan body cover | ボディカバー | **BY-NC** | — |
| [2904501](https://makerworld.com/ja/models/2904501) | StackChan-ServoBodycover | ボディカバー(サーボ) | **BY-NC** | — |
| [1145027](https://makerworld.com/ja/models/1145027) | Stack-chan_sample_piece | 顔/耳パーツ | **BY-NC-SA** | kennel.org(@kennel_org) |
| [564419](https://makerworld.com/ja/models/564419) | Stack-chan Crane Machine Accessory | タグ/キーホルダー | **BY-SA** | sskw |

### 非アクセサリー（MakerWorldにあるが対象外）

| ID | 名称 | 種別 | ライセンス |
|---|---|---|---|
| [2922441](https://makerworld.com/ja/models/2922441) | Stack-chan OpenCar with toio | 台車 | BY-NC |
| [2750877](https://makerworld.com/ja/models/2750877) | スタックチャンBOX | 収納 | **CC0** |
| [2781106](https://makerworld.com/ja/models/2781106) | 台座「Car-stom」| スタンド | MakerWorld限定 |
| [2817922](https://makerworld.com/ja/models/2817922) | M5StackChan-Cover-no-FrontPanel | カバー | MakerWorld標準 |
| [996135](https://makerworld.com/ja/models/996135) / [1349010](https://makerworld.com/ja/models/1349010) | M5Stack Stand-chan 各種 | スタンド | BY-NC |

### ライセンス区分の注意

- **CC0**：完全フリー（権利放棄）。**CC BY**：クレジットのみ。**CC BY-SA**：改変配布は同ライセンス継承。**CC BY-NC / BY-NC-SA**：非商用のみ（無料展示OK・物販不可）。
- **「MakerWorld標準ライセンス(Standard Digital File License)」「MakerWorld限定ライセンス(Exclusive)」**：個人・非商用の**印刷は可**だが**データ再配布・商用は不可**。当ブース（無料展示・データ再配布なし）は範囲内。
- MakerWorldはBambu連携でDL/印刷が容易＝**実質そのまま生成可能**。ただし透明シェル・猫耳（@mongonta555/@murasametech）は MakerWorld に無く、BOOTH/GitHub/直接許諾が必要。

## 次のアクション

- [ ] @uk59 / @UtaAoya の具体的な配布モデルURLを特定（プロフィール/固定ポスト）
- [ ] sskw・kenichi・user_93648059・sugamo・Tanipochi・beavers_hive の X アカウントを特定（許諾連絡先）
- [ ] 未確認ライセンス（#5,7,8,9）をモデルページで確定
- [ ] 各データを実際にDL・確認 → 作者へ許諾依頼（テンプレは research/accessories.md）

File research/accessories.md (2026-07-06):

# アクセサリー造形例・制作者・許諾管理

X（`#スタックチャン` / `#ｽﾀｯｸﾁｬﾝお誕生日2026` 等）で公開されているアクセサリー造形例と、各制作者への許諾依頼ステータスを管理する。**コピーではなく、許諾を得てからブースに設置する** 方針。

- 関連Issue: [#2 制作者リストと許諾依頼](https://github.com/aieo-product/stackchanEventBooth/issues/2)
- 調査方法: **Chromeブラウザ自動操作**（@otani_ai_memo でログイン）。`スタックチャン 配布` / `スタックチャン 着せ替え` / `#ｽﾀｯｸﾁｬﾝお誕生日2026` をメディア検索
- 調査日: 2026-07-02
- **各行の「代表ポスト」URLを開くと、アクセサリ画像と投稿主が同時に確認できます**（＝画像↔投稿主の照合＆連絡先）

## ステータス凡例

- 種別: 🧩配布あり(データ/現物) / 🎨カスタム・着せ替え例 / 📸撮影ブース
- 許諾: ☐ 未依頼 / 📨 依頼済 / ✅ OK / ❌ 不可

---

## ★ アクセサリー再確認（2026-07-06・connpass参加者照合）

出典イベント: [ｽﾀｯｸﾁｬﾝお誕生日会2026](https://stack-chan.connpass.com/event/394846/)（2026-06-27・大崎、参加者140名）。**参加者一覧(152アカウント)** と X `#ｽﾀｯｸﾁｬﾝお誕生日2026` を照合し、**スタックチャン本体に装着する「着せ替えアクセサリー」** と、**それ以外（乗り物・スタンド・配布ミニチュア・名札等）** を分類し直した。

> **分類基準**: 本体に装着して見た目を変えるもの＝「着せ替えアクセサリー」。キーホルダー/ミニチュア/バッジ/名札/乗り物/スタンド/収納箱は別カテゴリ（今回の"お着替え"対象外）。

### ✅ 着せ替えアクセサリー（＝ブースの主役・印刷対象）

| アクセサリー | 制作者(X) | connpass参加 | 確認 | メモ |
|---|---|:--:|:--:|---|
| **透明シェル / 着せ替えケース** | [@mongonta555](https://x.com/mongonta555)（Takao）| ✓ | ✅会場配布 | M5版本体の透明シェル。X で「透明ケース交換手順　確認用スレ」を投稿（2026-06-30）、資料は [SpeakerDeck](https://speakerdeck.com/mongonta0716) |
| **猫耳（LED・透明PLA製）** | [@murasametech](https://x.com/murasametech)（会長）/ [@mongonta555](https://x.com/mongonta555)（副会長）| mongonta✓ | ✅会場配布 | 「ｽﾀｯｸﾁｬﾝに猫耳LEDを付けさせる会」。@mongonta555 が「ご自由にお持ちくださいコーナー用に猫耳LEDを透明PLAで製作」と投稿（2026-06-25）、@murasametech が「猫耳製造工場」で引用 |
| ファー帽子・マント | [@syumme](https://x.com/syumme)（≒ syumme01?）| ✓ syumme | 🔎要確認 | LT登壇者。着せ替え衣装。旧調査の @syumme01 と同一か要確認 |
| 麦わら帽子ほか | [@mmmzhstd](https://x.com/mmmzhstd)（翼）| ✗参加者一覧に無し | 🔎 | 過去投稿。今回の会には未参加の可能性 |
| ヘッドホン | sskw（MakerWorld）| ✗ | 🔎 | MakerWorld配布（CC BY-NC-SA）。X handle未特定 |
| 帽子ジェネレータ（カスタム帽子）| beavers_hive（MakerWorld）| ✗ | 🔎 | MakerWorld配布（CC BY）。X handle未特定 |
| 髪型/ネコ耳などカスタム | [@hfujikawa77](https://x.com/hfujikawa77) | ✗ | 🔎 | 主軸は「移動スタックチャン」。着せ替え要素は一部のみ |

### ❌ アクセサリーではない造形（別カテゴリ・今回の"着せ替え"対象外）

| 造形 | 制作者(X / handle) | 種別 |
|---|---|---|
| OpenCar with toio / atom mate マウント | [@kenichih](https://x.com/kenichih)（ken-ichi-hayashi）| 台車・マウント |
| 移動スタックチャン各種 | [@hfujikawa77](https://x.com/hfujikawa77) | 乗り物 |
| スタックチャン BOX | sugamo（MakerWorld）| 収納箱 |
| 台座「Car-stom」| Tanipochi（MakerWorld）| スタンド |
| ミニスタックチャン キーホルダー | [@mongonta555](https://x.com/mongonta555) | ミニチュア（本体に装着しない配布品）|
| QR顔タグ / MakerChip / バッジ / コースター | [@kennel_org](https://x.com/kennel_org) / [@uk59](https://x.com/uk59) / [@washishi](https://x.com/washishi) | 名札・記念品（着せ替えではない）|
| マンドラゴラ for M5 AtomS3 | [@KantenNamako](https://x.com/KantenNamako) | 装飾モデル |

> **補足**: 会場配布された着せ替えパーツ（透明シェル・猫耳）は **@mongonta555 と @murasametech** が中心。猫耳は**ナチュラル（透明）PLA**で製作されており、当ブースの透明PLA採用とも整合。連絡先が明確なこの2名を**許諾依頼の最優先**に加える。

---

## A. モデル/アクセサリを実際に配布している制作者（`スタックチャン 配布` より・高確度）

| # | 制作者(X) | 配布物・造形 | 代表ポスト（画像＝この投稿） | 種別 | 許諾 |
|---|---|---|---|:--:|:--:|
| 1 | **[@mongonta555](https://x.com/mongonta555)**（タカヲ/Takao）| ミニスタックチャン キーホルダー/ストラップ（多色・多数配布）| [status/1918582213680984318](https://x.com/mongonta555/status/1918582213680984318) | 🧩 | ☐ |
| 2 | **[@UtaAoya](https://x.com/UtaAoya)**（A-Uta）| スタックチャン **ミニマル(スマホ版)ケース＋キーホルダー**（Fusionで3D設計、可動カバー。販売/配布検討）| [status/1954378916422185061](https://x.com/UtaAoya/status/1954378916422185061) | 🧩 | ☐ |
| 3 | **[@uk59](https://x.com/uk59)**（くうねる）| **アニバーサリーチップ/MakerChip**（表情×色 全16種・蓄光）／**薄焼き福笑い**／**メーカーチップホルダー(キーホルダー)**（配布用）| [MakerChip](https://x.com/uk59/status/1942543990299189421) ／ [福笑い](https://x.com/uk59/status/1907802731718521324) ／ [ホルダー](https://x.com/uk59/status/1943564565146669324) | 🧩 | ☐ |
| 4 | **[@kennel_org](https://x.com/kennel_org)**（kennel/技研AIマーケット）| QR付きスタックチャン顔タグ/キーホルダー（赤/白/水色・色々配布用）| [status/1943675461584007240](https://x.com/kennel_org/status/1943675461584007240) | 🧩 | ☐ |
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

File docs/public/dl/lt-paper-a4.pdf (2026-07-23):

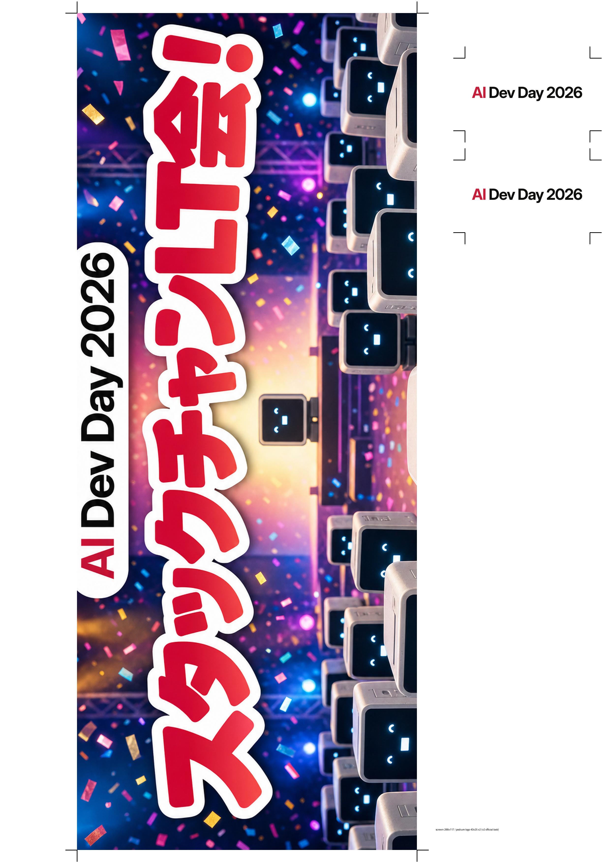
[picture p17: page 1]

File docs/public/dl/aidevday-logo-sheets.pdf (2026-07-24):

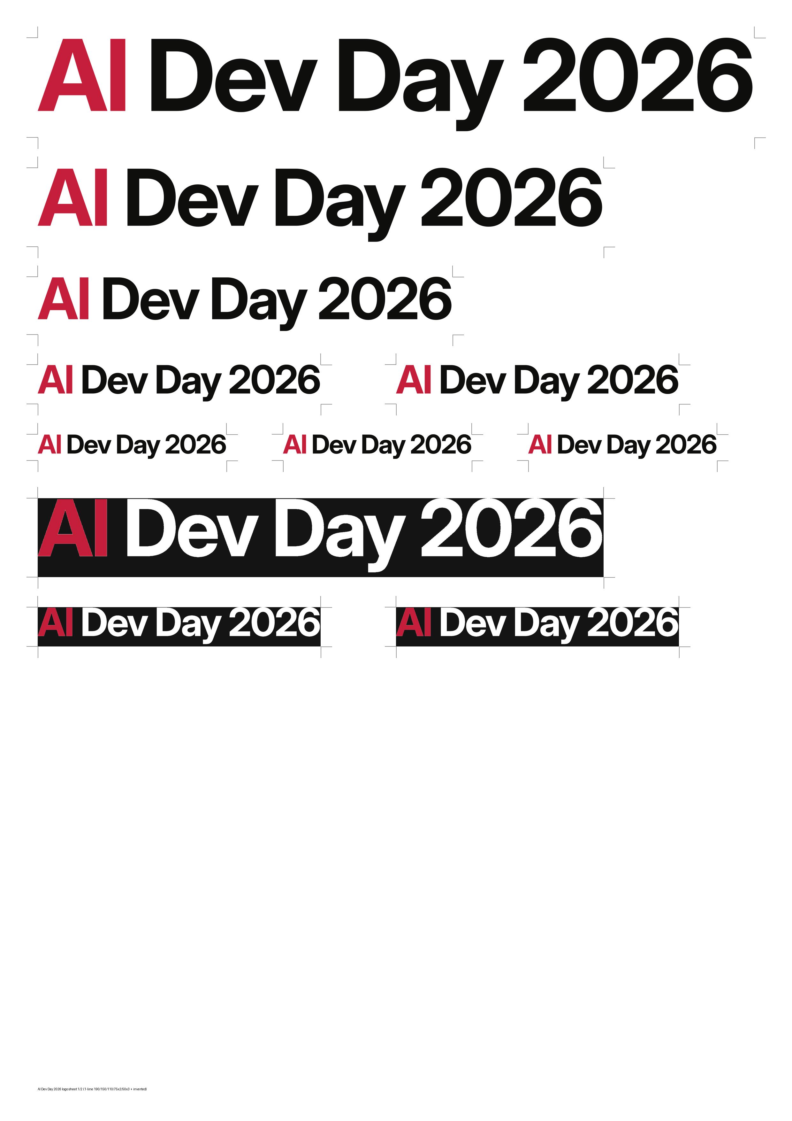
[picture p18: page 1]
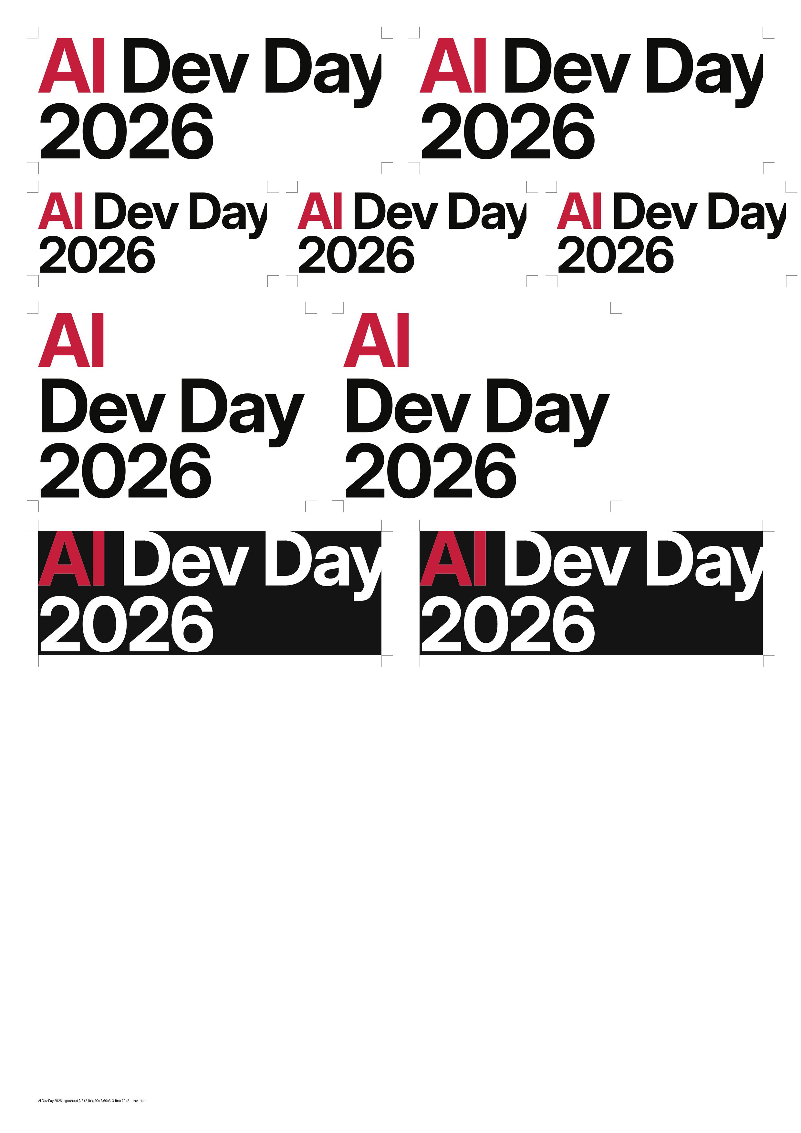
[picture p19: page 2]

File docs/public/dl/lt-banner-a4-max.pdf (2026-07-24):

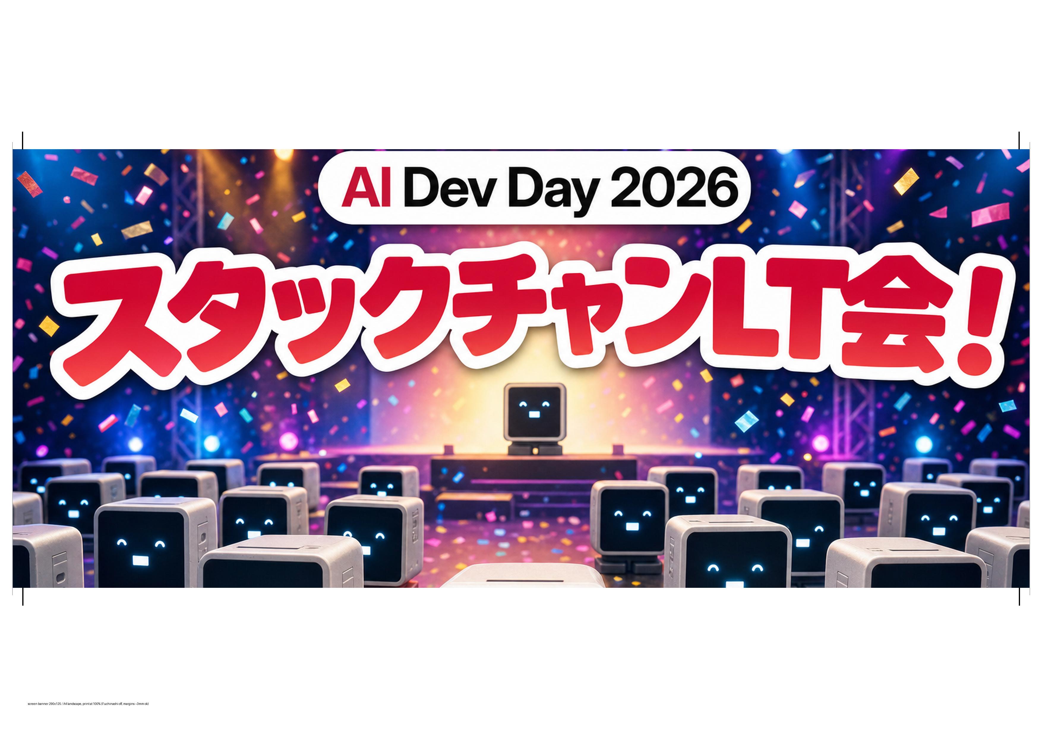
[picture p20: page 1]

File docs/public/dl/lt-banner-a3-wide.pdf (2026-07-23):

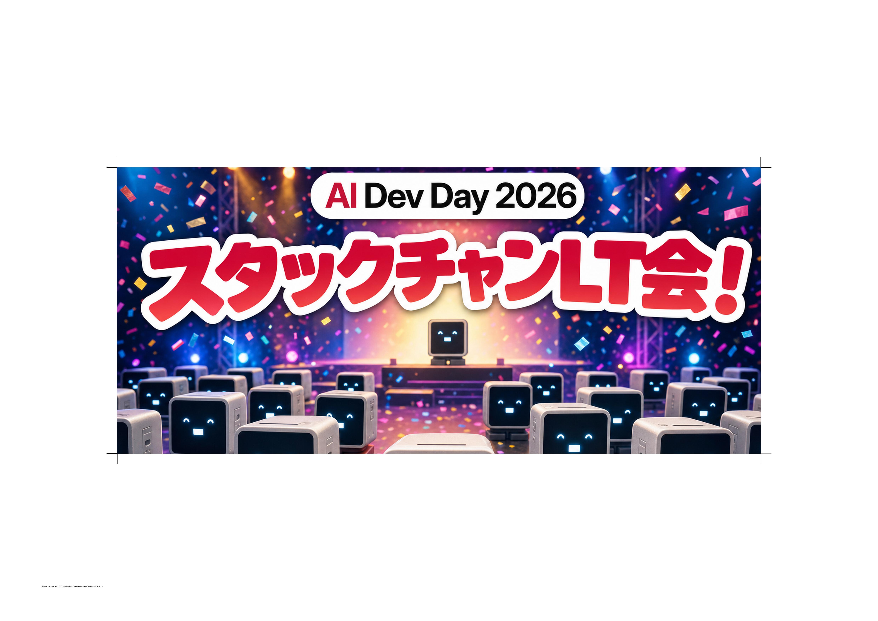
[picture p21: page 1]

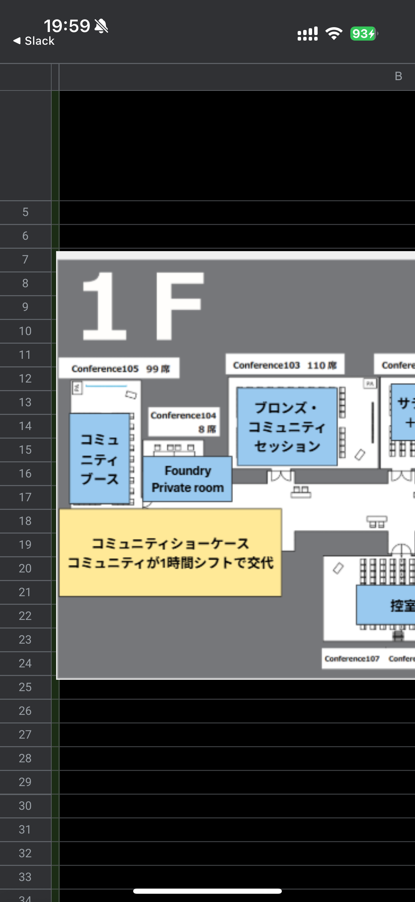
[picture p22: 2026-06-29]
baseIdea/eventBooth.PNG

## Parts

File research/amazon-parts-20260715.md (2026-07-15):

# 観覧車 追加発注パーツ 実売調査（2026-07-15・Amazon＋秋葉原実店舗）

- 調査方法: Chrome自動操作でAmazon.co.jpを閲覧のみ（カート投入なし）。価格は税込・お届け予定は調査時点の表示
- **全候補が翌日7/16(木)着**（Prime）を確認。在庫切れ・納期遅延なし
- 反映先: [docs/ferris-wheel.md](../docs/ferris-wheel.md) BOM表（採用候補=各項目a）／ [Issue #12](https://github.com/aieo-product/stackchanEventBooth/issues/12)

## 候補一覧（a=採用候補・b=代替）

| # | 商品名 | 価格 | URL | 評価 | 備考 |
|---|---|--:|---|---|---|
| 1a | BRINGSMART JGY-370 12V 3rpm ウォームギアモーター | ¥2,429 | [dp/B01HGCSBDM](https://www.amazon.co.jp/dp/B01HGCSBDM) | 4.2★(81) | セルフロック。低速要件に適合 |
| 1b | JGY-370 12V 6rpm 版 | ¥2,429 | [dp/B08MSYS1SD](https://www.amazon.co.jp/dp/B08MSYS1SD) | 4.1★(15) | トルク大きめ |
| 2a | Broadwatch ACアダプター 12V 2A 5.5×2.1mm | ¥1,380 | [dp/B00AJDAPM6](https://www.amazon.co.jp/dp/B00AJDAPM6) | 3.9★(229) | ケーブル約110cm |
| 2b | Kaito Denshi 12V 2A 24W | ¥1,890 | [dp/B0CMXLM5WL](https://www.amazon.co.jp/dp/B0CMXLM5WL) | 4.3★(10) | PSE適合 |
| 3a | beyourchoi PWMコントローラ DC1.8-15V 2A 6個 | ¥749 | [dp/B0CX55SRYM](https://www.amazon.co.jp/dp/B0CX55SRYM) | 4.2★(76) | 電圧範囲がジャスト |
| 3b | ZuoMei PWM 10A 400W | ¥750〜999 | [dp/B00IK6P8KI](https://www.amazon.co.jp/dp/B00IK6P8KI) | 3.9★(632) | 入力DC12-40V（12Vは下限） |
| 4a | LIANHATA ロッカースイッチ 2ピン 5個 | ¥575 | [dp/B0DG8R497X](https://www.amazon.co.jp/dp/B0DG8R497X) | 3.8★(69) | ラウンド型 |
| 4b | Youmile DC-099 DCジャック 5.5×2.1 10個 | ¥999 | [dp/B08SM3BY7L](https://www.amazon.co.jp/dp/B08SM3BY7L) | 3.9★(175) | 金属製・5A定格 |
| 5a | uxcell リニアシャフト 8×250mm 2本 | ¥1,180 | [dp/B08XYM78XJ](https://www.amazon.co.jp/dp/B08XYM78XJ) | 4.2★(50) | **Dカット無し**・焼入れで加工困難 |
| 5b | uxcell 304ステンレス丸棒 8×250mm 4本 | ¥2,107 | [dp/B0CF569NCG](https://www.amazon.co.jp/dp/B0CF569NCG) | 3.9★(29) | Dカット無し・切削しやすい |
| 6a | Saipor 6-8mm ビームカップリング 5個 | ¥999 | [dp/B07ZMYSYLH](https://www.amazon.co.jp/dp/B07ZMYSYLH) | 4.3★(21) | 高トルクで強度不足報告（本用途は低トルク） |
| 6b | Ohamtes 6-8mm カップリング 2個 | ¥1,272 | [dp/B09MC5C9KG](https://www.amazon.co.jp/dp/B09MC5C9KG) | 3.9★(14) | 外径19mm・L25mm |
| 7a | ALITOVE WS2812B 5m 60LED/m IP20 | ¥3,369 | [dp/B01N7BX973](https://www.amazon.co.jp/dp/B01N7BX973) | 4.6★(10) | 指定仕様に最も近い |
| 7b | BTF-LIGHTING WS2812B 5m 60LED/m IP65 | ¥4,099 | [dp/B08THGBTZN](https://www.amazon.co.jp/dp/B08THGBTZN) | 4.3★(182) | IP30はl m/144LEDのみ在庫 |
| 8a | 304ステンレス丸棒 Φ3×300mm 10本 | ¥1,050 | [dp/B0FCZP736S](https://www.amazon.co.jp/dp/B0FCZP736S) | 4.4★(19) | ベストセラー1位 |
| 8b-1 | uxcell Eクリップ 3mm 50枚 | ¥660 | [dp/B0G2SFKXW1](https://www.amazon.co.jp/dp/B0G2SFKXW1) | 0件 | 3mm専用 |
| 8b-2 | E型スナップリング120個 M1.5-M10 | ¥589 | [dp/B08HN2CCDZ](https://www.amazon.co.jp/dp/B08HN2CCDZ) | 3.9★(294) | 10サイズ入りで汎用 |

## 集計・所見

- **モーター系5点（1a+2a+3a+4a+4b+6a）= ¥7,131** → 切替閾値¥6,000を超過（最安構成でも¥6,700台）→ **手回し版に決定（2026-07-15）**
- 電動版合計 約¥13,300 ／ 手回し版合計 約¥6,200（5a+7a+8a+8b-2）
- Φ8mm**Dカット付きは在庫なし** → ハブ固定はM3イモネジ×2に設計変更（docs反映済み）
- LEDはIP30×2mの完全一致なし → ALITOVE IP20×5mで代替
- フレキシブルカプラは高トルクで強度不足の報告 → 本用途（低速・低トルク）は許容、必要ならリジッド型へ

## 秋葉原実店舗の在庫調査（秋月電子通商・千石電商、2026-07-15）

オフィス（神田）から店頭購入できる前提で、手回し版に必要な3点＋予備1点を両店の通販サイトで調査（閲覧のみ）。

| パーツ | 秋月電子通商 | 千石電商 |
|---|---|---|
| アドレサブルLEDテープ（60LED/m・2m） | ✅ **SK6812テープLED 1m/60LED ¥1,940**（[112982](https://akizukidenshi.com/catalog/g/g112982/)・WS2812B互換・通販在庫410本・2本で¥3,880）。30LED/m版（¥1,200・[130333](https://akizukidenshi.com/catalog/g/g130333/)）は密度不足 | ❌ アドレサブル品の取扱なし（JTT製の単色/一括制御USBテープライトのみ） |
| Φ8mmシャフト（金属） | ❌ 取扱なし（「シャフト」はモーターハブ等のみ） | ❌ 金属8mmなし。[アクリル透明丸棒 8φ×30cm ¥330](https://www.sengoku.co.jp/mod/sgk_cart/detail.php?code=6B4T-TDEN)（本店2階・在庫拠点秋葉原）のみ — 樹脂のため軸用途は強度要検証 |
| Φ3mm丸棒（金属）＋Eリング | ❌ 丸棒なし | 丸棒❌／✅ **EリングEW3 ¥25/個・100個¥580**（[EEHD-6GJZ](https://www.sengoku.co.jp/mod/sgk_cart/detail.php?code=EEHD-6GJZ)・本店2階） |
| 608ベアリング（予備） | ❌ | ✅ **ミネベア608ZZ ¥221/個**（[EEHD-4JWX](https://www.sengoku.co.jp/mod/sgk_cart/detail.php?code=EEHD-4JWX)・本店3階）— 7/13注文分の遅延時バックアップ |

### 所見
- **金属丸棒2種（8mm/3mm）は秋葉原の両店で入手不可** → Amazonで発注が確実。未確認の候補: 西川電子部品・東急ハンズ秋葉原・模型店（一般知識・現地確認要）
- LEDは秋月SK6812（店頭・当日）とAmazon ALITOVE 5m（明日着・¥3,369）の二択。必要量ちょうどで買うなら秋月、単価で選ぶならAmazon
- 千石・秋月は徒歩圏内で1回の外出で回れる。店頭在庫数はサイト非公開のため来店前の電話確認推奨
- 千石の店舗情報: Eリング=本店2階／608ZZ=本店3階／アクリル丸棒=本店2階（いずれも在庫拠点: 秋葉原）

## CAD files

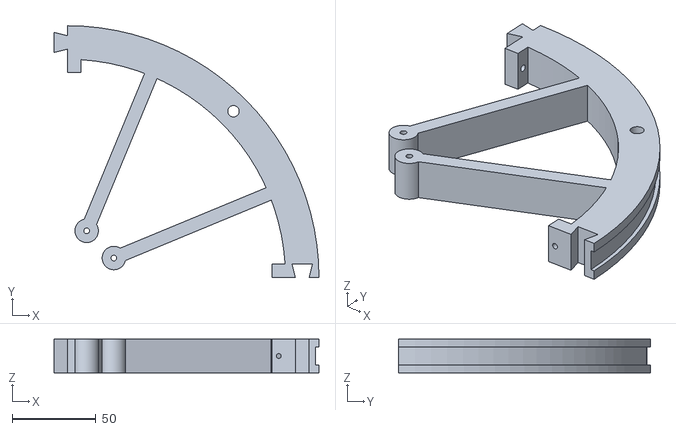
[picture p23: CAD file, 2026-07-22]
docs/public/dl/rim-segment-v20260722.stl
158.0 x 150.0 x 20.0

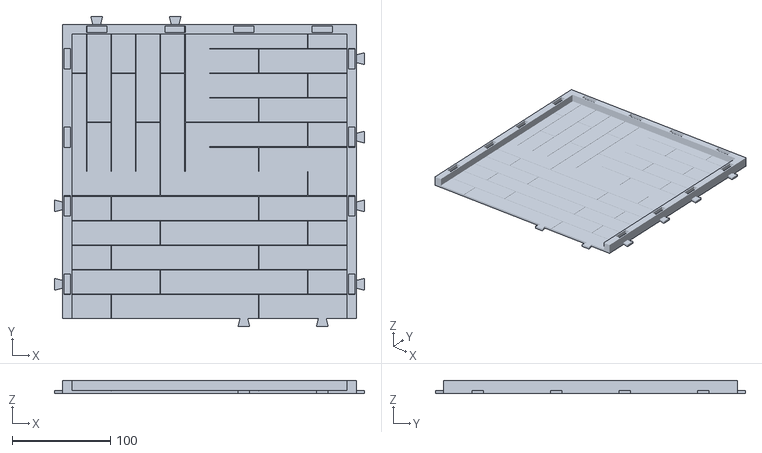
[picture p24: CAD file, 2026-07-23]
docs/public/models/booth/floor.stl
316.0 x 316.0 x 13.0

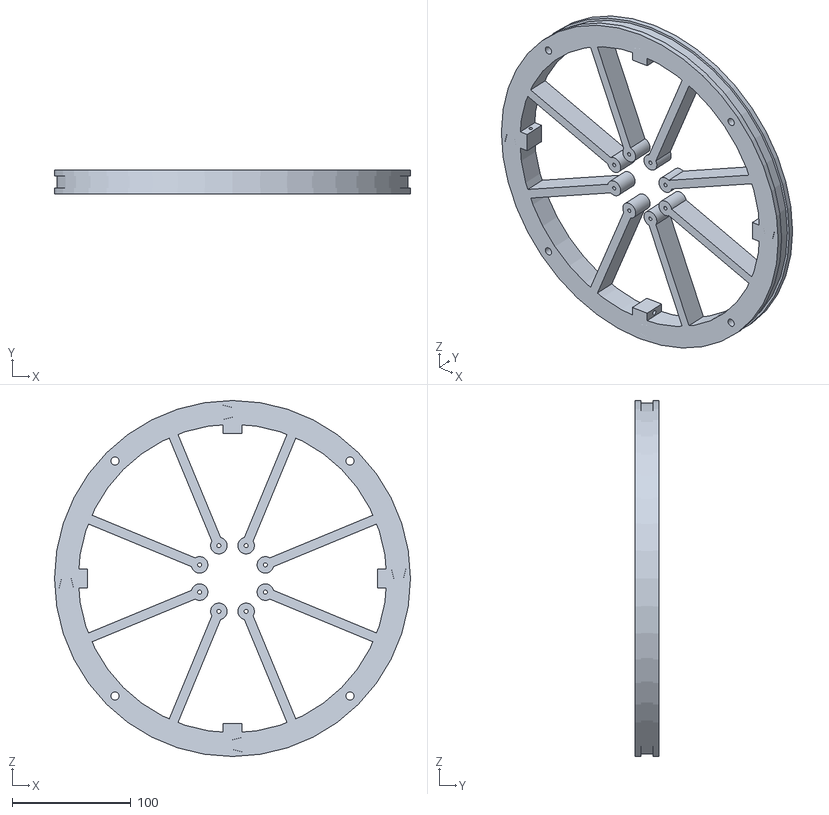
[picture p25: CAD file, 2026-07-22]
docs/public/models/ferris/rim-rear.stl
300.0 x 20.0 x 300.0

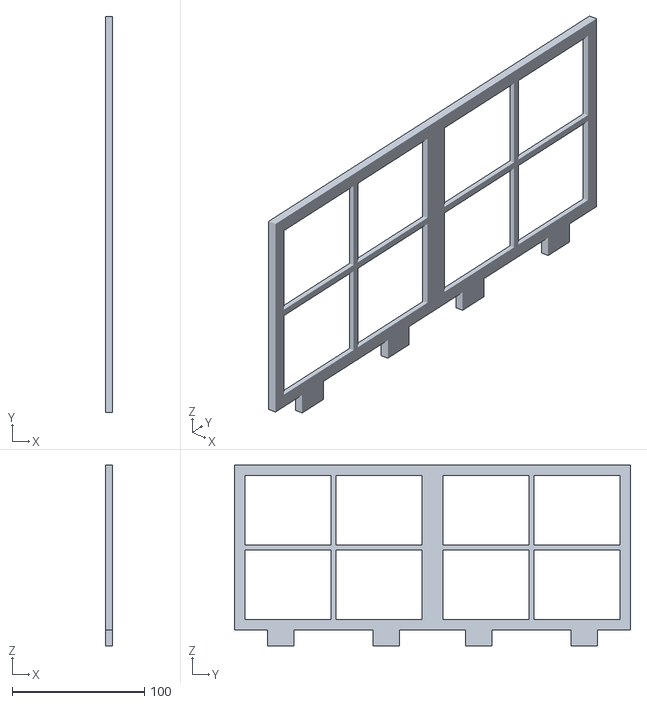
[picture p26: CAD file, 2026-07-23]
docs/public/models/booth/window-walls.stl
5.00 x 300.0 x 137.0

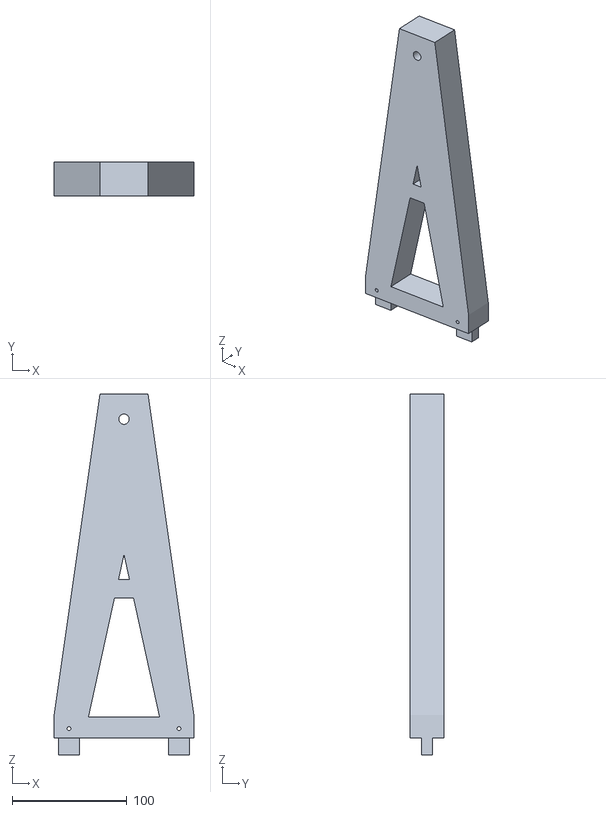
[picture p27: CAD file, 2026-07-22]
docs/public/models/ferris/tower-rear.stl
122.0 x 30.0 x 315.0

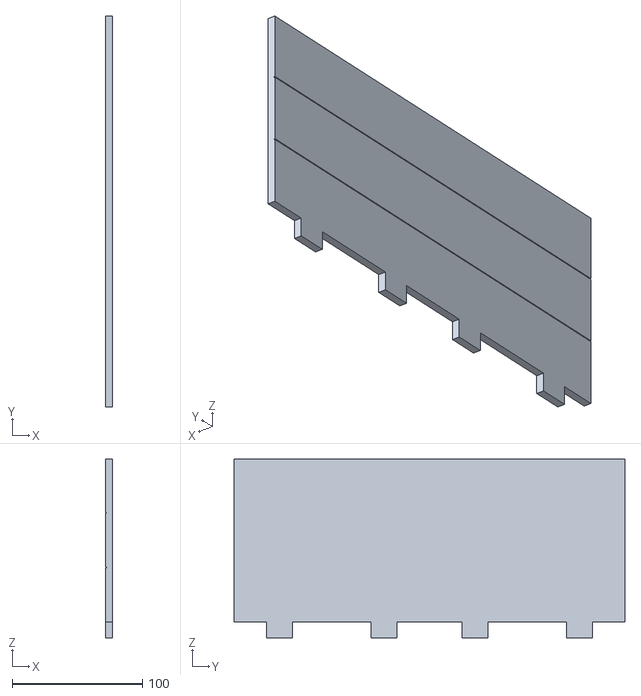
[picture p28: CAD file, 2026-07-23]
docs/public/models/booth/plain-walls.stl
5.00 x 300.0 x 137.0

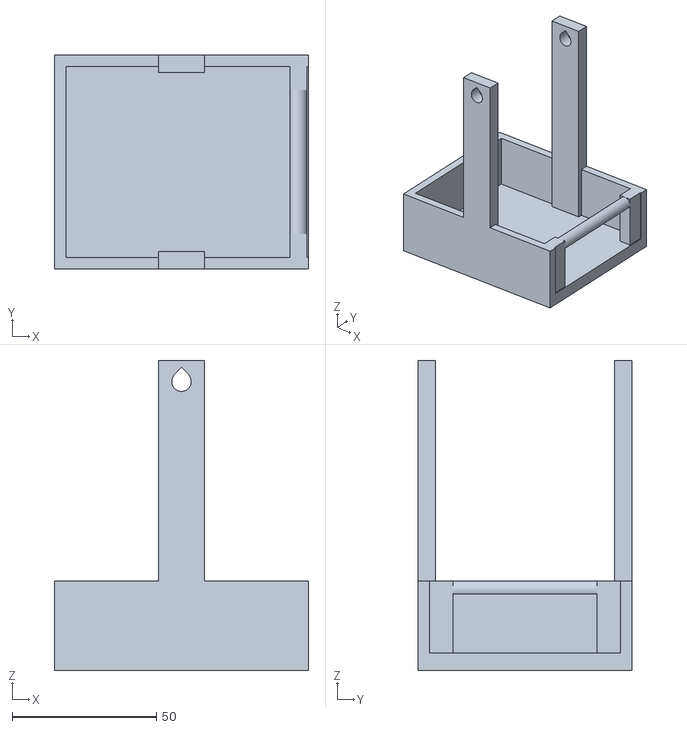
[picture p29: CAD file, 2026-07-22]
docs/public/models/ferris/gondola-1.stl
88.0 x 74.0 x 107.3

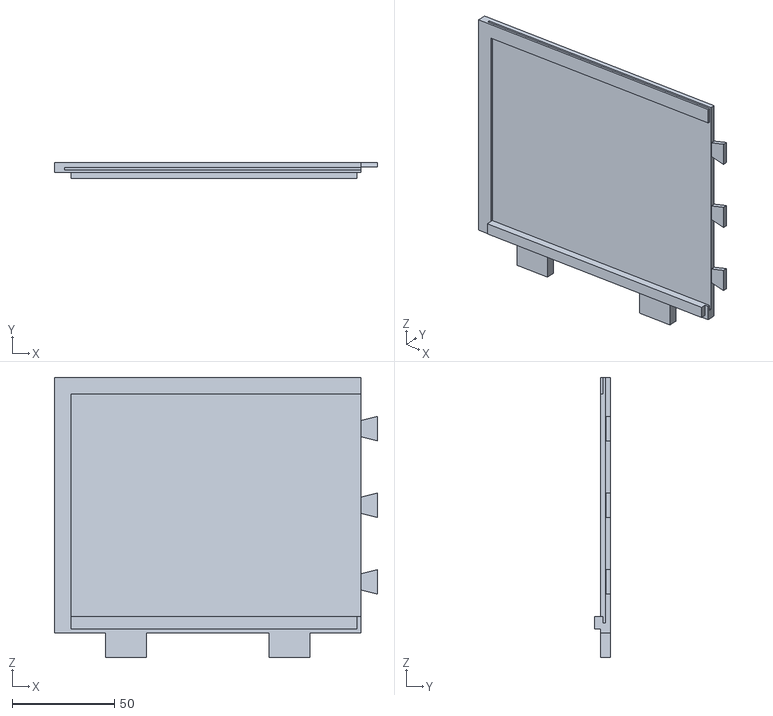
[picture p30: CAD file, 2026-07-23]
docs/public/models/booth/screen-l.stl
158.0 x 8.00 x 137.0

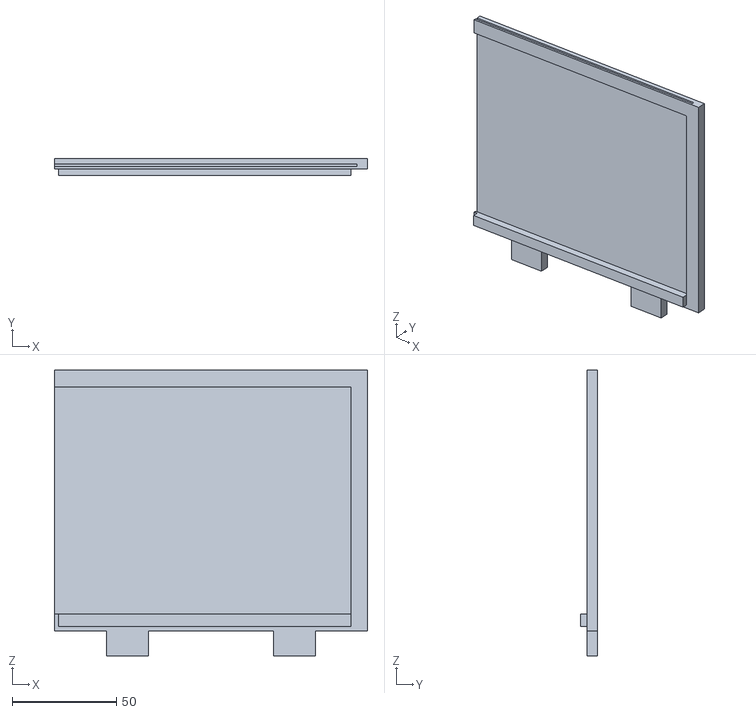
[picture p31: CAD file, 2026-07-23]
docs/public/models/booth/screen-r.stl
150.0 x 8.00 x 137.0

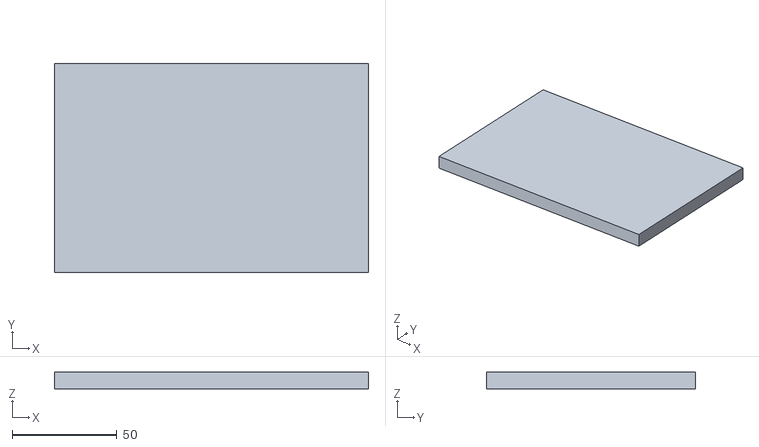
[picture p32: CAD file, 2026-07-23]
docs/public/models/booth/stage.stl
150.0 x 100.0 x 8.00

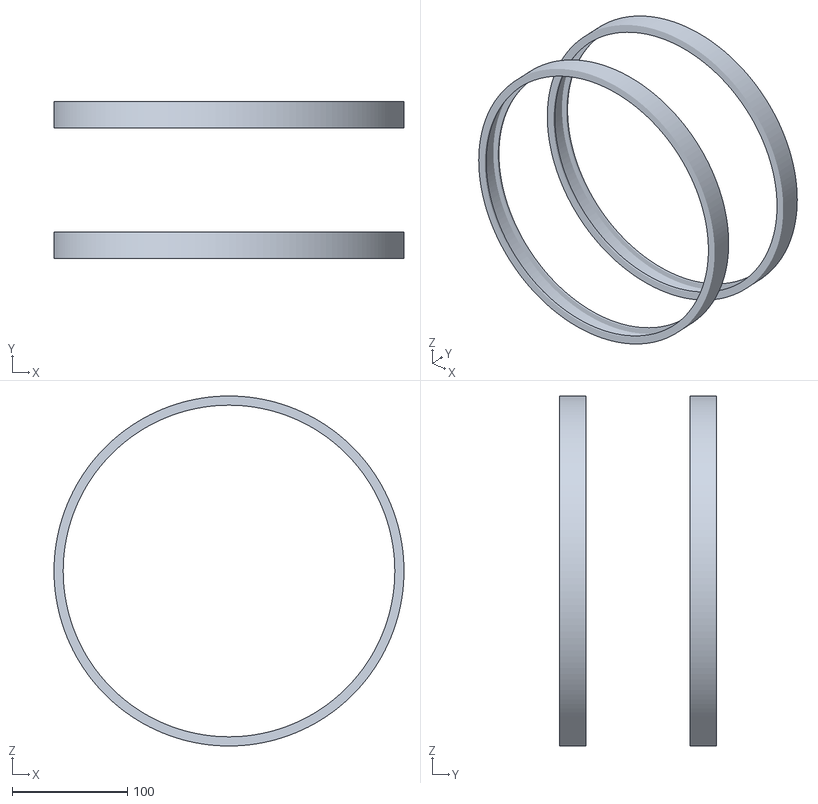
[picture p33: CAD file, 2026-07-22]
docs/public/models/ferris/diffusers.stl
304.0 x 136.4 x 304.0

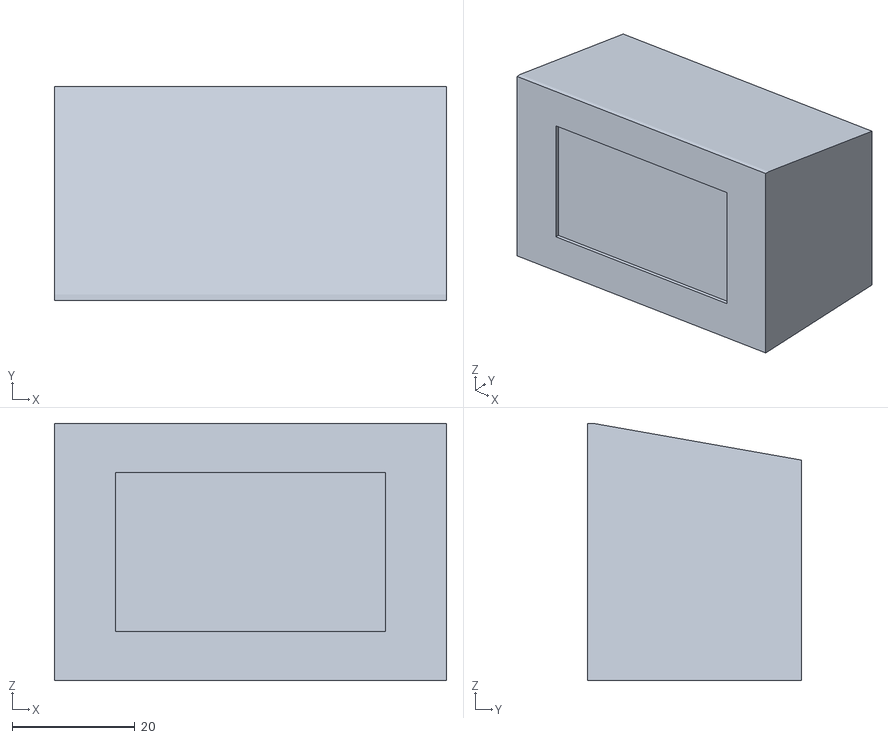
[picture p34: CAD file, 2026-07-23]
docs/public/models/booth/podium.stl
64.0 x 35.0 x 42.0

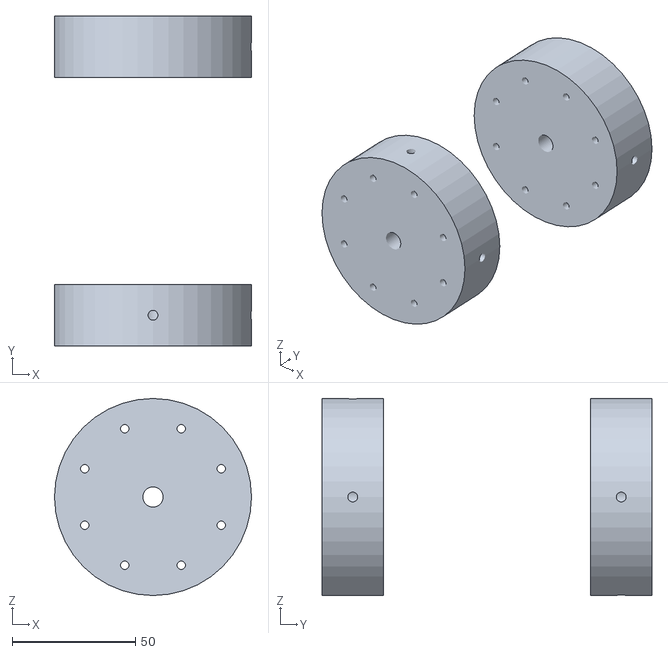
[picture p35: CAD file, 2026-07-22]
docs/public/models/ferris/hubs.stl
80.0 x 134.0 x 80.0

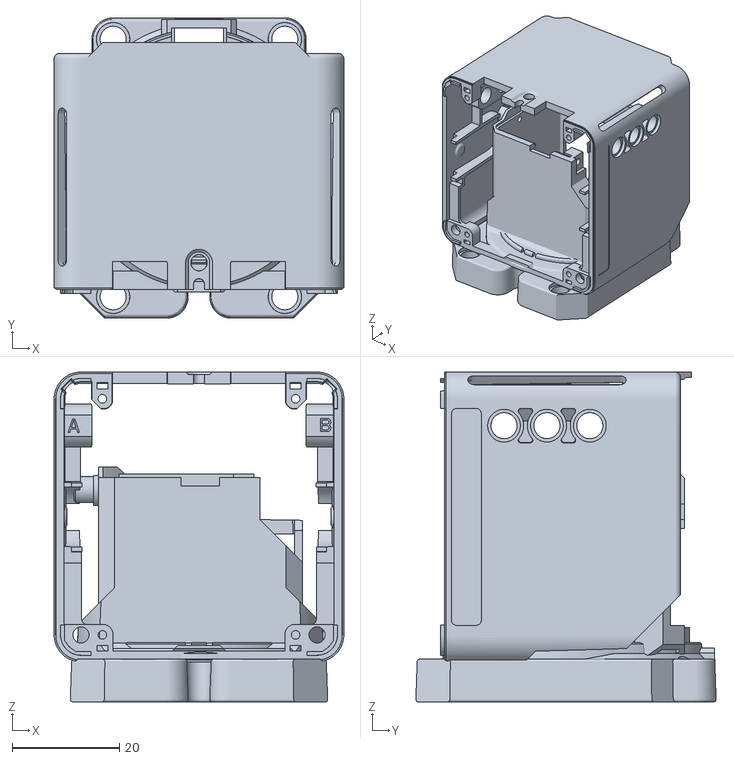
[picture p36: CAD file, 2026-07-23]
docs/public/models/booth/robot.stl
54.0 x 56.0 x 61.5

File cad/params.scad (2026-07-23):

// params.scad
// Single source of truth for all dimensions and tolerances.
// Ferris wheel (docs/ferris-wheel.md) + photo booth (docs/photobooth.md).
// All units are millimetres.

// ---------------------------------------------------------------------------
// Global rendering resolution
// ---------------------------------------------------------------------------
$fn = 96;          // default facet count for curved surfaces

// ---------------------------------------------------------------------------
// Print tolerances (initial version = safe / loose side; retune after 7/15 test)
// ---------------------------------------------------------------------------
tol          = 0.30;   // generic hole enlargement over nominal (0.2..0.4)
tol_dovetail = 0.15;   // per-side clearance on dovetail joints
tol_snap     = 0.20;   // snap-fit clearance (diffuser over rim)

// Common fastener nominal sizes
m3_clear   = 3.4;      // M3 clearance hole
m3_insert  = 4.0;      // heat-set insert press hole (M3)
m3_thread  = 2.9;      // self-tapping pilot for M3 (7/22 spokehub test: 2.5 printed ~2.2, too tight to bite; 2.9 prints ~2.6)

// ---------------------------------------------------------------------------
// Build volume guard (Bambu X2D style plate); every part must stay under this
// ---------------------------------------------------------------------------
max_part = 250;

// ===========================================================================
// FERRIS WHEEL
// ===========================================================================

// --- Rim (Ø300, quarter arcs, 4 per disc x 2 discs = 8) --------------------
rim_outer_d   = 300;                 // wheel outer diameter
rim_outer_r   = rim_outer_d / 2;     // 150
rim_radial_w  = 20;                  // radial width of the rim band
rim_inner_r   = rim_outer_r - rim_radial_w;   // 130
rim_depth     = 20;                  // axial thickness of the rim
rim_seg_angle = 90;                  // quarter arc

// LED groove on outer periphery (for 10 mm SK6812 tape)
led_groove_w  = 10.5;                // axial width
led_groove_d  = 2.0;                 // radial depth

// Spokes: 2 per segment, 8 per disc total, evenly spaced (45 deg)
spoke_count_per_seg = 2;
spoke_width   = 8;                   // tangential width of a spoke beam
spoke_depth   = 12;                  // axial thickness of a spoke beam
spoke_mount_r = 30;                  // radius at which spoke bolts to hub
spoke_pad_d   = 14;                  // diameter of the bolt pad at spoke tip

// --- Diffuser (U-channel cover snapping over rim outer band) ----------------
// Rim outer band is rim_depth (20) wide axially; cover wraps it.
diff_inner_w  = rim_depth + tol_snap * 2;   // internal width to clear rim (10.7 spec is for tape only)
diff_wall     = 1.6;                  // cover wall thickness
diff_lip      = 1.2;                  // snap lip that hooks the rim inner corner
diff_cover_t  = 2.0;                  // radial thickness of the outer cover shell
// Note: spec calls out an internal tape width of 10.7; the tape sits in the
// rim LED groove, the diffuser wraps the whole 20 mm band. See README.

// --- Hub (Ø80 x 25) --------------------------------------------------------
hub_d         = 80;
hub_r         = hub_d / 2;           // 40
hub_h         = 25;
shaft_d       = 8;                   // nominal 8 mm shaft
shaft_hole_d  = 8.2;                 // through bore for shaft
hub_boltring_r = spoke_mount_r;      // 30, matches spoke pads
hub_bolt_count = 8;                  // spoke bolt holes
hub_bolt_a0   = 22.5;                // first hole angle (matches spoke layout)
hub_set_count = 2;                   // radial set-screw insert bosses
hub_set_insert_d = m3_thread;        // 7/22: insert undelivered -> M3 set screw taps directly into 2.9 pilot (pre-tap with a normal M3 bolt first)

// --- Gondola (chair-type open gondola, redesign #18) ------------------------
// Carries one M5Stack CoreS3/K151 unit (official base 48.0x56.0xh11.1, whole
// 54.0x70.5x61.5, 187.2 g). Open front so the screen/body is visible; the unit
// is loaded from the top and sits in a two-stage nested floor pocket.
gon_floor_x   = 88;                  // seat plate length (X = robot facing dir): clears the 70.5 envelope + front bar
gon_floor_y   = 74;                  // seat plate width (Y = along the axle): towers inner +/-31 > robot half-width 27
gon_floor_t   = 6;                   // seat plate thickness

// two-stage nested floor pockets (both measured down from the seat top)
gon_pocket_o  = 62;                  // outer pocket (square) - generic/Takao base + gel tape
gon_pocket_o_d = 1.5;                // outer pocket depth
k151_base_x   = 48.0;                // official K151 base footprint (X)
k151_base_y   = 56.0;                // official K151 base footprint (Y)
gon_pocket_fit = 0.5;                // clearance per side for the K151 base (7/19: printed pockets shrink ~0.2-0.3; the feet are integral to the 48x56 base outline)
gon_pocket_i_x = k151_base_y + 2 * gon_pocket_fit;   // 57.0: robot faces +X, base DEPTH lies along X
gon_pocket_i_y = k151_base_x + 2 * gon_pocket_fit;   // 49.0: base WIDTH lies along Y
gon_pocket_i_d = 2.0;                // inner pocket depth (deeper -> locates the base)

gon_side_h    = 25;                  // side rail + backrest height above the seat
gon_wall_t    = 4;                   // rail / backrest thickness
gon_backrest_h = 25;                 // low back wall height

gon_post_x    = 6;                   // hanger post cross-section (X)
gon_post_y    = 18;                  // hanger post cross-section (Y)
gon_post_cx   = 33;                  // post centre offset: inner faces at +/-30 -> 6 mm total clearance over the 54-wide unit
gon_pivot_z   = 100;                 // swing-axle centre height (7/22: 80->100 so decorated robots (hats etc.) clear the axle; head clearance 13->33 mm. tower_total_h raised +20 in step to keep ground clearance)
gon_bridge_y  = 30;                  // hanger-bridge length in Y (grips the axle over 30 mm)

gon_bar_d     = 6;                   // front safety bar diameter (D-section, flat underside)
gon_bar_rise  = 22;                  // bar height above the seat top

// Swing axle: PRINTED Ø6 PLA axle (the user has no rod-cutting tools), replacing
// the Ø3 metal rod. No E-ring needed - a push cap retains it. The ordered Ø3
// steel rod / E-rings are repurposed for other builds.
gon_axle_d    = 6.0;                 // printed Ø6 axle nominal
gon_hook_d    = 6.7;                 // J-slot width (printed holes shrink ~0.2; 7/19 test)
gon_axle_hole_d = 6.8;               // rim/disc through-hole (7/19 test: 6.4 was too tight on the printed axle)
gon_axle_r    = rim_inner_r + rim_radial_w/2;  // 140: axle centreline radius on the rim band
gon_axle_seg_angle = 45;             // one axle hole per segment, mid-arc -> 4 axles per wheel
// assembly note: the rim inner gap must clear the gondola WIDTH along the axle
// (gon_floor_y=74) -> gap 90 gives 8 mm/side.

// --- Printed axle (cad/ferris/axle.scad) -----------------------------------
axle_rim_gap   = 90;                 // clear gap between rim discs (> gondola depth 84 + clearance)
axle_thru_len  = axle_rim_gap + 2 * rim_depth;   // 120: through both 20 mm rims
axle_protrude  = 6;                  // shaft past the far rim for the cap to grab
axle_shaft_len = axle_thru_len + axle_protrude;  // 126
axle_head_d    = 10;                 // integral flange head
axle_flat      = 0.4;                // D-flat depth (print-flat orientation)
axle_head_t    = 3;
axle_total_len = axle_head_t + axle_shaft_len;   // 129 (~128 target)
axle_cap_d     = 10;                 // push-cap outer diameter
axle_cap_h     = 6;
axle_cap_bore  = gon_axle_d;         // 6.0: printed bore shrinks ~0.2-0.3 -> effective light press fit (7/19 tune)
axle_count     = 4;                  // one per gondola
axle_spares    = 1;                  // print a spare axle
cap_spares     = 2;                  // and a couple of spare caps
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

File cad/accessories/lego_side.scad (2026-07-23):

// accessories/lego_side.scad (7/23)
// K151 body side LEGO(Technic)-compatible holes -> tiny event accessories.
// All parts print LYING FLAT (pin axis in the bed plane -> strong layers).
//   PART = "pintest"  : 3 pins (4.6/4.8/5.0) on a handle plate - fit test first!
//   PART = "flag"     : pin + pole + flag plate embossed "LT!"
//   PART = "penlight" : pin + short glow-stick shape (print in a bright colour)
// Technic hole nominal: 4.8. Pick the pin dia that snaps in from the test.

PIN_D   = 4.8;         // chosen after the pintest
pin_len = 7.4;         // Technic hole depth ~7.8
slit_w  = 1.1;         // flex slit

module pin(d) {
    difference() {
        union() {
            rotate([0, 90, 0]) cylinder(d = d, h = pin_len, $fn = 32);
            // small stop collar
            rotate([0, 90, 0]) cylinder(d = d + 2.4, h = 1.6, $fn = 32);
        }
        // flex slit through the pin tip
        translate([2.2, -slit_w/2, -d]) cube([pin_len, slit_w, d * 2]);
    }
}

module pintest() {
    // handle plate with three test pins, dia labels embossed
    dias = [4.6, 4.8, 5.0];
    difference() {
        translate([-3, -8, -3]) cube([3, 46, 6]);
        for (i = [0 : 2])
            translate([-2.4, i * 15 - 2.5, 2.2])
                rotate([90, 0, 90]) linear_extrude(0.6)
                    text(str(dias[i]), size = 4, halign = "left");
    }
    for (i = [0 : 2]) translate([0, i * 15, 0]) pin(dias[i]);
}

module flag() {
    pin(PIN_D);
    // pole continuing from the collar
    rotate([0, -90, 0]) cylinder(d = 4, h = 38, $fn = 24);
    // flag plate in the pin-axis plane -> vertical when mounted
    translate([-38, -1.5, 0]) {
        difference() {
            translate([0, 0, -11]) cube([30, 1.6, 22]);
            translate([3.5, 1.61, -8]) rotate([90, 0, 0])
                linear_extrude(0.7) text("LT!", size = 12, halign = "left");
        }
    }
}

module penlight() {
    pin(PIN_D);
    // stick with a rounded tip (hull of cylinder + sphere), lying flat
    hull() {
        rotate([0, -90, 0]) cylinder(d = 6, h = 26, $fn = 32);
        translate([-28, 0, 0]) sphere(d = 6, $fn = 32);
    }
}

PART = "pintest";
if (PART == "flag")          flag();
else if (PART == "penlight") penlight();
else                         pintest();

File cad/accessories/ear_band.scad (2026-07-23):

// accessories/ear_band.scad (7/23)
// Snap-on headband accessories for the K151 head unit (MainBody 54.0 wide,
// measured from cad/vendor/k151/StackChan-MainBody.stl). Prints LYING FLAT.
//   PART = "cat"    : cat ears
//   PART = "bunny"  : tall bunny ears
//   PART = "ribbon" : ribbon / bow
// The U-band clips over the top of the head; small lips snap on the sides.

head_w  = 54.0;
fit     = 0.6;          // opening play
band_t  = 2.4;          // band thickness (in plane)
band_w  = 6;            // band width (print height, lies flat)
arm_len = 14;           // side arm length
lip     = 0.6;          // snap lip at the arm tips

iw = head_w + fit;      // 54.6 inner span

module band() {
    // top bar + two side arms with inward lips (2D in X-Z, extruded in Y)
    linear_extrude(band_w) {
        // top bar
        translate([-iw/2 - band_t, 0]) square([iw + 2 * band_t, band_t]);
        for (sx = [-1, 1]) scale([sx, 1]) {
            // arm
            translate([iw/2, -arm_len]) square([band_t, arm_len]);
            // snap lip
            translate([iw/2 - lip, -arm_len]) square([band_t/2 + lip, 1.6]);
        }
    }
}

module cat_ear() {
    // triangle with a small inner-ear notch
    difference() {
        polygon([[-9, 0], [9, 0], [0, 16]]);
        polygon([[-4.5, 1.2], [4.5, 1.2], [0, 11]]);
    }
}

module cat()   { band();
    for (sx = [-1, 1]) scale([sx, 1, 1])
        translate([iw/2 - 10, 0, 0]) rotate([0, 0, 8])
            translate([0, band_t - 0.01, 0]) linear_extrude(band_w) cat_ear();
}

module bunny_ear() {
    hull() {
        translate([0, 24]) scale([1, 1.6]) circle(d = 11, $fn = 40);
        translate([0, 2]) circle(d = 9, $fn = 40);
    }
}

module bunny() { band();
    for (sx = [-1, 1]) scale([sx, 1, 1])
        translate([iw/2 - 12, band_t - 0.01, 0]) rotate([0, 0, -6])
            linear_extrude(band_w) bunny_ear();
}

module ribbon() { band();
    translate([0, band_t - 0.01, 0]) linear_extrude(band_w) {
        // two bow wings + centre knot
        for (sx = [-1, 1]) scale([sx, 1])
            polygon([[3, 1], [20, 12], [20, 0.5], [3, -1.5]]);
        translate([-4, -2]) square([8, 15]);
    }
}

PART = "cat";
if (PART == "bunny")       bunny();
else if (PART == "ribbon") ribbon();
else                       cat();

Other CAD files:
docs/public/models/ferris/tower-front.stl
docs/public/models/ferris/rim-front.stl
docs/public/models/ferris/crank.stl
docs/public/models/ferris/axles.stl
cad/booth/assembly.scad
cad/booth/floor_tile.scad
cad/booth/lt_podium.scad
cad/booth/stand_clips.scad
cad/booth/wall_foot.scad
cad/booth/wall_panel.scad
cad/ferris/assembly.scad
cad/ferris/axle.scad
cad/ferris/base.scad
cad/ferris/base_mini.scad
cad/ferris/crank.scad
cad/ferris/diffuser.scad
cad/ferris/fit_check.scad
cad/ferris/fit_test_kit.scad
cad/ferris/gondola.scad
cad/ferris/hub.scad
cad/ferris/joint_test_a.scad
cad/ferris/joint_test_b.scad
cad/ferris/k151.scad
cad/ferris/mate_check.scad
cad/ferris/rim_segment.scad
cad/ferris/swing_test_rig.scad
cad/ferris/tower.scad
cad/mini/adapter_gondola.scad
docs/public/models/ferris/base.stl
docs/public/models/ferris/gondola-2.stl
docs/public/models/ferris/gondola-3.stl
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

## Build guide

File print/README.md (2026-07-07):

# print/ — 印刷リストと自動印刷の仕組み

スタックチャン ブース用アクセサリーを、**リスト（マニフェスト）経由で Bambu Lab X2D に
自動で印刷**するための一式です。

```
print/
├── print-list.yaml   ← 「何を・どのファイルで・何色・何個」印刷するかの唯一の定義
├── auto_print.py     ← リストを読み、X2D へ 1 ジョブずつ送って印刷（逐次・立ち会い前提）
├── download.py       ← print/files/ に不足しているモデルの入手先URLを表示
├── requirements.txt  ← 依存（PyYAML, bambulabs_api）
└── files/            ← 実モデルファイル(.gcode.3mf 等)。★Git管理外（.gitignore）
```

## なぜ実ファイルは Git に入れないのか（ライセンス）

MakerWorld のモデルは作者の権利物で、**一部ライセンスは再配布不可**です
（「MakerWorld標準/限定ライセンス」＝個人・非商用の印刷は可だがデータ再配布は不可）。
そのため**バイナリ（.3mf/.stl）は `print/files/` に置きつつ Git 管理外**にし、
リポジトリには**印刷の定義とスクリプトだけ**を保存します。ファイルはリスト経由で
各自ローカルに集める運用です（CC0/BY/BY-SA/BY-NC-SA など再配布可のものは、
`print-list.yaml` の `redistribute: true` を目印に、希望あれば同梱可）。

## セットアップ

### 1. 依存インストール（各自のPython環境で）
```bash
cd print
python3 -m venv .venv && source .venv/bin/activate   # 任意
pip install -r requirements.txt
```

### 2. プリンター接続情報を Keychain に登録（値はファイルに書かない）
X2D を **LAN モード**にし（Bambu Studio > プリンター設定 > 「LAN Only Mode / 開発者モード」）、
プリンター画面に表示される **IP / アクセスコード / シリアル**を登録します。
```bash
security add-generic-password -s BAMBU_PRINTER_IP  -a BAMBU_PRINTER_IP  -w "192.168.x.x" -U
security add-generic-password -s BAMBU_ACCESS_CODE -a BAMBU_ACCESS_CODE -w "XXXXXXXX"     -U
security add-generic-password -s BAMBU_SERIAL      -a BAMBU_SERIAL      -w "01P00A..."    -U
# もしくは: akc set BAMBU_ACCESS_CODE
```
スクリプトは**サービス名のみ**で取得します（`-a` は付けない・[CLAUDE.md 準拠](../../CLAUDE.md)）。

### 3. モデルファイルを用意
```bash
python3 download.py            # 不足ファイルと入手先URLを一覧
python3 download.py --open     # 入手先をブラウザで開く
```
MakerWorld の各モデルで **Print Profile（事前スライス済み `.gcode.3mf`）** を
ダウンロードし、`print-list.yaml` の `file` 名（例 `files/hat-generator.gcode.3mf`）で
`print/files/` に保存します。Bambu Studio の「MakerWorldで開く→印刷」でも取得できます。

## 使い方

```bash
# 何を刷るか確認（既定は dry-run。プリンターには送らない）
python3 auto_print.py

# 特定の1種だけ
python3 auto_print.py --only hat-generator

# 実際に印刷（★プリンターに立ち会うこと）
python3 auto_print.py --go
python3 auto_print.py --go --yes    # 開始確認プロンプトを省略
```

`auto_print.py --go` は `print-list.yaml` の **`enabled: true`** のジョブを上から順に、
`copies` の数だけ印刷します。1 ジョブ完了 →（`wait_between_sec` 待機）→ 次、の逐次実行です。

## 印刷リスト（print-list.yaml）の書き方

```yaml
jobs:
  - key: hat-generator            # 一意キー（--only で指定）
    name: 帽子ジェネレータ
    makerworld_id: "2772131"
    url: https://makerworld.com/ja/models/2772131
    license: BY                   # ライセンス（下記凡例）
    redistribute: true            # リポジトリ同梱可否
    file: files/hat-generator.gcode.3mf   # print/files/ 内のファイル
    color: パステルピンク          # 色メモ（人間用）
    ams_mapping: [0]              # AMS スロット割当（プロファイルの色→実スロット）
    copies: 2                     # 印刷個数
    enabled: true                 # false でスキップ
```

ライセンス凡例: `BY`=クレジットのみ / `BY-SA`=改変配布は継承 /
`BY-NC`・`BY-NC-SA`=非商用のみ（無料展示OK・物販不可）/ `CC0`=フリー /
`MW-STD`(標準)・`MW-EX`(限定)=個人非商用の印刷可・再配布不可。

## ⚠️ 安全上の注意

- **3Dプリンターの無人運転は禁止**。火災・造形失敗のリスクがあるため、
  `--go` は必ず立ち会って実行してください。本ツールは意図的に逐次実行です。
- 実行前に **AMS のフィラメント（色・残量）**と**ビルドプレートの空き**を確認。
- 透明シェル・猫耳（@mongonta555 / @murasametech）は MakerWorld 外のため、
  **作者の許諾＋データ入手後**に `files/` へ置き、`enabled: true` にしてください。

## 関連

- 造形とライセンスの調査: [`../research/model-data.md`](../research/model-data.md)
- 着せ替えアクセサリー一覧（公開サイト）: [/accessories](https://stackchan-event-booth.pages.dev/accessories)
- フィラメント必要量・購入: [/printing](https://stackchan-event-booth.pages.dev/printing)

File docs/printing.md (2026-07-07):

# 造形プリント環境と必要量

保有している **Bambu Lab X2D** で、アクセサリー造形を印刷するための環境整備手順と、必要なフィラメント量の見積りです。本体は保有済みのため、経費計上は**フィラメント代のみ**（[経費まとめ](/expenses)）。

::: tip このページの目的
1. **どのデータを・どの設定で刷るか**（環境整備）を確定する
2. **フィラメントが何g・何本・いくら必要か**（数量根拠）を出して [経費](/expenses) に反映する
:::

## 1. プリント環境の整備（Bambu Lab X2D）

### ソフトウェア

| 項目 | 内容 |
|---|---|
| スライサー | **Bambu Studio**（公式・無料）をインストール。X2D のプリンタープロファイルを選択 |
| データ取得 | MakerWorld のモデルページ「**Bambu Studio で開く / Print**」から直接インポート可（STL 手動DLも可）|
| 接続 | Wi-Fi 経由でクラウド送信、または SD/USB。**当日は事前印刷持込みが前提**（会場での印刷はしない）|

### 推奨マテリアル・設定

| 項目 | 推奨 | 備考 |
|---|---|---|
| フィラメント | **PLA（マット）** パステル系 | 発色がよく、造形が映える。匂い少・扱いやすい |
| ノズル | 0.4mm（標準）| 細部が必要な小物もこれで十分 |
| レイヤー高 | 0.16〜0.20mm | 見た目重視は0.16mm、量産は0.20mm |
| インフィル | 15%（グリッド）| キーホルダー等の小物は十分な強度 |
| サポート | 帽子・耳は最小限／ヘッドホンは要 | オーバーハング部のみ |
| 多色 | AMS で多色 or 単色を手動切替 | 多色時はパージ（フラッシュ）でフィラメント消費増（後述）|

### データ準備の段取り

1. [造形データ配布元リスト](/accessories#造形データ配布元-データを確認-許諾へ)の各モデルを Bambu Studio に取り込む
2. サイズ・向き・サポートを確認し、**テスト印刷で単重(g)を実測**して下表を更新
3. **ライセンス順守**：NC（BY-NC / BY-NC-SA）は無償の展示・配布のみ（**物販不可**）、SA は改変配布時に同ライセンス継承、いずれも**クレジット必須**
4. 各作者の**許諾取得後**に本番印刷（[許諾管理](https://github.com/aieo-product/stackchanEventBooth/blob/main/research/accessories.md)）

## 2. フィラメント必要量の計算

造形リストと想定個数から、必要フィラメント量を積み上げます。単重はモデル一般値からの**概算**で、テスト印刷後に実測値へ更新します。造形は [着せ替えアクセサリー](/accessories)（本体に装着＝ブースの主役）と、配布品・小物に分けています。

**① 着せ替えアクセサリー（本体に装着・印刷対象の主役）**

| 造形部品 | 主な出典 | 単重(g) | 個数 | 小計(g) |
|---|---|--:|--:|--:|
| 🫧 透明シェル／着せ替えケース | @mongonta555 | 35 | 2 | 70 |
| 🐱 猫耳（LED対応）| @murasametech / @mongonta555 | 8 | 6 | 48 |
| 🎩 帽子（数種）| beavers_hive | 15 | 4 | 60 |
| 🎧 ヘッドホン | sskw | 20 | 2 | 40 |
| 🧥 ファー帽子／マント | @syumme | 12 | 2 | 24 |
| 👒 麦わら帽子 | @mmmzhstd | 10 | 2 | 20 |
| | | | 小計 | **262 g** |

**② 配布品・撮影小物（着せ替えではない・任意）**

| 造形部品 | 主な出典 | 単重(g) | 個数 | 小計(g) |
|---|---|--:|--:|--:|
| 🔑 キーホルダー／顔タグ（配布）| kennel.org / uk59 | 8 | 40 | 320 |
| 🧸 ミニスタックチャン（配布）| mongonta555 | 10 | 20 | 200 |
| 📸 撮影ブース小物（自作）| 本企画 | — | 一式 | 60 |
| | | | 小計 | **580 g** |
| | | | **合計（①＋②）** | **842 g** |

### マージンを加えた実質必要量

| 区分 | 係数 | 加算(g) | 累計(g) |
|---|--:|--:|--:|
| 造形合計 | — | — | 842 |
| 失敗・試作・リテイク | +25% | +211 | 1,053 |
| AMS 多色パージ（多色印刷時）| +約15% | +160 | 約 **1,210** |

> **実質必要量 ≈ 1.2〜1.3 kg**

### 購入本数と金額（2026-07-06 Bambu在庫確認済み・透明PLA追加）

色バリエーション確保と在庫のため、実消費1.2〜1.3kgに対し余裕を持たせて**6色 × 1kg スプール = 6kg** の購入を推奨します（余りは次回以降に使用）。ちょうどBambu Lab公式ストアが**4周年記念セール中**（〜7/7、[プロモーションページ](https://jp.store.bambulab.com/pages/promotions/anniversary-filament-bulk-sale1)）で、フィラメントを**4点以上同時購入すると35%OFF**（10点以上で45%OFF）になるため、実際の在庫を確認したうえで下記の構成に更新し、**透明（フロスト/クリア）PLAを新規追加**しました。

::: warning 在庫状況（2026-07-06 時点・ブラウザでライブ確認）
Bambu PLA マット・PLA半透明とも、**パステル系の人気色（桜ピンク／レモンイエロー／アイスブルー・スカイブルー 等）はセールでほぼ売り切れ**でした。在庫のある色（白・グレー・マリンブルー・ライトジェイド 等）を基本構成とし、売り切れだったパステル2色（ピンク・イエロー）は**他社1.75mm PLA（AMS対応表記あり）で代替**しています。詳細は下記「[フィラメント購入リスト](#フィラメント購入リスト-在庫確認済み)」を参照。
:::

| # | 用途色 | 品目 | 単価(税込) | セール適用後 | 本数 |
|--:|---|---|--:|--:|--:|
| 1 | 白 | Bambu PLA マット アイボリーホワイト | ¥2,800 | ¥1,820(35%OFF) | 1 |
| 2 | 青 | Bambu PLA マット マリンブルー | ¥2,800 | ¥1,820(35%OFF) | 1 |
| 3 | グレー(汎用) | Bambu PLA マット アッシュグレー | ¥2,800 | ¥1,820(35%OFF) | 1 |
| 4 | 透明(フロスト) | Bambu PLA 半透明 ライトジェイド | ¥4,680 | ¥3,042(35%OFF) | 1 |
| 5 | ピンク(パステル代替) | eSUN マットPLA ピーチピンク（他社） | ¥2,299 | ¥2,299(セール対象外) | 1 |
| 6 | 黄(パステル代替) | eSUN マットPLA アーモンドイエロー（他社） | ¥2,299 | ¥2,299(セール対象外) | 1 |
| | | | | **合計 ¥13,100** | **6kg** |

Bambu 4点（白・青・グレー・透明）はまとめて購入することで35%OFFが適用され、他社パステル代替2点と合わせても、旧プラン（4色×¥3,500＝¥14,000）より**総額は下がり、色数（透明を含め6色）は増えています**。

::: info 実測での更新ポイント
- 各部品の**単重(g)** は Bambu Studio のスライス結果で確定できます。テスト印刷後に上表を実測値へ更新すると、より正確な必要量・金額になります。
- 多色をやめて**単色運用**にすればパージ分（約160g）が不要になり、必要量は約1.05kgに下がります。
- Bambuの4周年セールは**7/7まで**（なくなり次第終了）。購入タイミングによって在庫・価格が変動するため、発注直前に再確認してください。
:::

## フィラメント購入リスト（在庫確認済み）

Bambu Lab公式ストア（日本）と主要ECサイトで、**2026-07-06時点**の在庫・価格をブラウザで直接確認しました（Bambu側はカラースワッチのUI状態から在庫あり/売切を判定。売切色にはスワッチに斜線オーバーレイが表示される仕様）。

| 用途色 | 製品名 | メーカー | 価格(税込) | 在庫状況(2026-07-06確認) | 購入リンク |
|---|---|---|--:|---|---|
| 白 | PLA マット アイボリーホワイト | Bambu Lab | ¥2,800(35%OFF時¥1,820) | Bambuセール ○在庫あり | [商品ページ](https://jp.store.bambulab.com/products/pla-matte-filament) |
| 青 | PLA マット マリンブルー | Bambu Lab | ¥2,800(35%OFF時¥1,820) | Bambuセール ○在庫あり（パステル系のアイスブルー/スカイブルーは×売切） | [商品ページ](https://jp.store.bambulab.com/products/pla-matte-filament) |
| グレー | PLA マット アッシュグレー | Bambu Lab | ¥2,800(35%OFF時¥1,820) | Bambuセール ○在庫あり | [商品ページ](https://jp.store.bambulab.com/products/pla-matte-filament) |
| 透明(フロスト) | PLA 半透明 ライトジェイド | Bambu Lab | ¥4,680(35%OFF時¥3,042) | Bambuセール ○在庫あり（ブルー/パープル/チェリーピンク/メロウイエロー/アイスブルー/ラベンダーは×売切） | [商品ページ](https://jp.store.bambulab.com/products/pla-translucent) |
| ピンク(パステル代替) | マットPLAフィラメント ピーチピンク | eSUN（他社・代替品） | ¥2,299 | Bambu「桜ピンク」×売切のため代替、Amazon在庫あり | [Amazon.co.jp](https://www.amazon.co.jp/dp/B0BG1GC81J) |
| 黄(パステル代替) | マットPLAフィラメント アーモンドイエロー | eSUN（他社・代替品） | ¥2,299 | Bambu「レモンイエロー」×売切のため代替、Amazon在庫あり | [Amazon.co.jp](https://www.amazon.co.jp/dp/B0BG19VKFD) |
| （予備候補）透明(無色クリア) | PLA+ フィラメント Transparent | TINMORRY（他社・任意追加） | ¥2,199 | 追加候補・Amazon在庫あり（無色に近いクリアが欲しい場合） | [Amazon.co.jp](https://www.amazon.co.jp/dp/B0G8HF3QFF) |

::: tip Bambu在庫確認の方法・注意点
- Bambu Lab JPストアの商品ページでは、カラースワッチに斜線オーバーレイが付いている色が「売り切れ」。桜ピンク・レモンイエロー・アイスブルー・スカイブルー・プラム 等、**パステル/ライト系カラーの大半が4周年セールで売り切れ**でした（2026-07-06時点、7/7までのタイムセール終了間際のため今後変動の可能性あり・要再確認）。
- Bambu公式には**無色透明（クリア）PLAの取り扱いがなく**、最も近いのは「PLA半透明」（フロスト調・カラー付き半透明、全10色）。無色に近いクリアが欲しい場合は他社PLA（TINMORRY 等）が候補。
- 他社PLA（eSUN/TINMORRY 等、1.75mm・「ほとんどのFDM/AMS対応」表記あり）はBambu Lab X2DのAMSでも使用実績が広く報告されていますが、**スプール幅・巻き量には個体差**があるため、初回はテスト装填で確認してください。
- 価格・在庫は変動します。発注直前に各リンク先で再確認してください。
:::

→ この見積りは [経費まとめ](/expenses) の「フィラメント」行に反映しています。

## リスト経由の自動印刷（print/）

「何を・どのファイルで・何色・何個 印刷するか」を **[`print/print-list.yaml`](https://github.com/aieo-product/stackchanEventBooth/blob/main/print/print-list.yaml)** に定義し、そのリスト経由で **X2D へ自動で印刷**する仕組みをリポジトリに用意しました。

```bash
cd print
pip install -r requirements.txt
python3 download.py          # 不足モデルの入手先URLを表示（MakerWorldのPrint Profile）
python3 auto_print.py        # dry-run（印刷内容の確認）
python3 auto_print.py --go   # 実行（X2DへLAN送信。★立ち会い必須）
```

- **X2D を LAN モード**にし、接続情報（IP/アクセスコード/シリアル）は macOS Keychain に登録（値はコミットしない）。
- 実モデルファイルは **ライセンス配慮でGit管理外**（`print/files/`）。リスト経由で各自ローカルに集めます。
- 詳細・安全上の注意は [`print/README.md`](https://github.com/aieo-product/stackchanEventBooth/blob/main/print/README.md)。**無人運転は禁止**（火災・失敗リスクのため逐次・立ち会い運用）。

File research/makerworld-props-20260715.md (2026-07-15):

# MakerWorld ジオラマ小物・観覧車 調査（撮影ブース学校テーマ／観覧車 Issue #12・#13）

- 調査日: 2026-07-15 / 方法: Chrome自動操作（英語キーワード主軸・モデルページ個別確認）
- 目的: ①撮影ブース（学校・教室ジオラマ）の1/12前後ミニチュア小物、②観覧車の既存モデル流用可否
- スケール前提: スタックチャン身長約6cm。1/12ドールハウス家具＝「小学生が教室にいる」サイズ感
- 関連: [Issue #12](https://github.com/aieo-product/stackchanEventBooth/issues/12)（観覧車）/ [Issue #13](https://github.com/aieo-product/stackchanEventBooth/issues/13)（撮影ブース3Dプリント化）/ 前回全数調査 [makerworld-survey-20260713.md](./makerworld-survey-20260713.md)

## A. 学校・教室テーマの小物

| モデル名 | URL | 制作者 | ライセンス | Profile | サイズ情報 | 👍/DL | 備考（スケール適合） |
|---|---|---|---|---|---|---|---|
| 教室のミニチュアシーン | [2750405](https://makerworld.com/ja/models/2750405-classroom-interior-miniature-scene) | MonsieurPierre | MW-STD（商用はPatreon） | 有（42分・1プレート） | 記載なし | 33/32 | 机・椅子・教員エリア・書棚・掲示板の教室一式。1プレートで手早い |
| ミニチュアビンテージ学校机と椅子セット | [1314963](https://makerworld.com/ja/models/1314963-miniature-vintage-school-desk-and-chair-set) | Printed a mini | MW-STD（商用はPatreon） | 有（1.3h・1プレート） | 実質1/8〜1/10（バービーKellyにぴったりとの実測報告） | 599/431 | 6cmスタックチャンにやや大きめだが違和感僅少。フィラメントをヒンジに使う組立 |
| 簡単な教室＆学校の机＆椅子 | [1908905](https://makerworld.com/ja/models/1908905-simple-classroom-school-desk-school-chair) | たいよう | 要確認 | 要確認 | 記載なし | 101/38 | シンプル量産向き・日本人制作者 |
| 椅子付き学校机（ドールハウス教室セット） | [2658444](https://makerworld.com/ja/models/2658444-school-desk-with-chair-dollhouse-classroom-set) | MonsieurPierre | MW-STD（推定） | 有（推定） | 記載なし | 116/26 | 教室シーンと同作者・組合せ前提 |
| ミニハイスクールロッカー | [2933194](https://makerworld.com/ja/models/2933194-mini-high-school-locker-organizer) | madad | 要確認 | 要確認 | 記載なし | 37/65 | 実物志向 |
| ミニチュアモジュラーロッカー | [968921](https://makerworld.com/ja/models/968921-mini-modular-locker) | N33 Designs | MW-STD（商用はPatreon） | 有（3.3〜3.7h） | **高さ175mm** | 8.9k/7.2k | 大人気（835レビュー）。6cm身長比で大きすぎ→縮小推奨 |
| ミニスクールロッカー（デスクオーガナイザー） | [2724278](https://makerworld.com/ja/models/2724278-mini-school-locker-3d-printed-desk-organizer) | DUDKA | MW-STD（商用はPatreon） | 有（9.8〜15h・4プレート） | 標準/ミニ2サイズ | 1.8k/913 | 印刷時間が長く今回の期間ではロッカーは任意扱い |
| ミニ教室黒板 | MonsieurPierre検索結果内 | MonsieurPierre | MW-STD（推定） | 有（推定） | 記載なし | 23/14 | 黒板単体 |
| イーゼル黒板（リトルタイクス風） | 検索結果内 | Cliffrose | 要確認 | 要確認 | 記載なし | 34/67 | 自立イーゼル型 |
| 1/12 公園/校庭/街路ベンチ | [1276012](https://makerworld.com/ja/models/1276012-1-12-scale-park-bench-campus-bench-street-bench) | Foximg | MW-STD | 有（48分・1プレート） | **1/12設計・1/24〜1/6拡縮対応と明記** | 226/641 | 校庭ベンチ。拡縮前提設計でスケール合わせしやすい |

- 「ランドセル」単体モデルはヒットなし（キーホルダー系のみ）。すべり台・ブランコ等の遊具は学校ジオラマ向けが少ない（住宅地児童公園 user_698898779、子供/遊び場 Wossi が近い）。

## B. 現実世界の生活感を出す汎用小物

| モデル名 | URL | 制作者 | ライセンス | Profile | 👍/DL | 備考 |
|---|---|---|---|---|---|---|
| 日本の自動販売機 | [1615169](https://makerworld.com/ja/models/1615169-japanese-vending-machine) | PattyWithAP | MW-STD | 有（多色3.6h・1プレート） | 41/130 | 日本のコンビニ自販機。4色AMSで塗装不要・ジオラマ向き |
| パステルカプセルトイ自販機 | 検索結果内 | burakeser07 | 要確認 | 要確認 | 10.3k/7.4k | 大人気だがガチャ機で装飾寄り |
| 街灯（都市照明モデル） | [2732902](https://makerworld.com/ja/models/2732902-street-lamp-urban-light-model) | MonsieurPierre | MW-STD（商用はPatreon） | 有（24分） | 75/222 | ネイティブ1/12前後想定。細い柱は破損注意 |
| ミニ街灯（点灯ギミック付） | 検索結果内 | 3DMakerSpace | 要確認 | 要確認 | 251/582 | マグネットスイッチで点灯 |
| 郵便ポスト（米国型/丸型） | 検索結果内 | Crafty Princess / Jellyfruit | 要確認 | 要確認 | 3.7k/1.6k・331/866 | 日本の丸型に近いのはJellyfruit版 |
| ミニ交通信号機 各種 | 検索結果内 | GreenBale/Betalab3D等 | 要確認 | 要確認 | 144/58等 | 日本型とは形状差あり要選別 |
| 1/12テーブルチェアセット | 検索結果内 | MiniCraft3D | 要確認 | 要確認 | 239/156 | 汎用（明記1/12） |

- 日本語検索（ランドセル・郵便ポスト等）はノイズ過多。英語キーワード主軸が有効（前回知見を再確認）。

## C. 観覧車

| モデル名 | URL | 制作者 | ライセンス | Profile | サイズ/駆動 | 👍/DL | 評価 |
|---|---|---|---|---|---|---|---|
| 100% 3Dプリント メカニカル観覧車 | [862148](https://makerworld.com/ja/models/862148-100-3d-printed-mechanical-ferris-wheel-without-ams) | espRyk | MW-STD | 有（20.4h・7プレート） | 高さ非公開／**手回しクランク** | 225/63 | 歯車機構が本格的だが組立シビア（苦戦報告複数） |
| 大型観覧車 N20ギアードモーター付き | [911733](https://makerworld.com/ja/models/911733-big-wheel-ferris-wheel-with-n20-gear-motor) | espRyk | MW-STD | 有（16.6h） | 推定Ø205／**電動（N20+USB5V）** | 237/60 | 完成度最高・コミュニティ活発。ゴンドラ寸法非公開→実機搭乗は不可前提 |
| 電動発光観覧車 | [1625080](https://makerworld.com/ja/models/1625080-motorized-luminous-ferris-wheel) | GUYI DESIGN | MW-STD（商用登録制） | 有（52h・9プレート） | スプールトレイ土台／**電動+LED** | 34/3 | 半田付け必須・印刷52h→期間内不可 |
| 回転観覧車（シルバニアファミリー） | [2503805](https://makerworld.com/ja/models/2503805-rotating-ferris-wheel-for-kids-sylvanian-family) | jj0815 | **MW-EX**（クレジット要） | 有（11.5h・4色5プレート） | シルバニア人形（6〜7cm）向け／手動回転 | 16/19 | **スケール適合最良**。ただし軽量人形前提で150g実機は強度不足見込み |
| 機械式バネ駆動観覧車 | 検索結果内 | Altron Studios | 要確認 | 要確認 | ゼンマイ駆動 | 19/32 | 電源不要がユニーク（詳細未調査） |
| 回転式観覧車 | 検索結果内 | 3D Print Universe | 要確認 | 要確認 | 回転ギミック | 36/17 | 詳細未調査 |
| 観覧車キット（可動） | 検索結果内 | NextMG | 要確認 | 要確認 | 可動 | 26/28 | 詳細未調査 |
| 電動観覧車（k013付属品） | 検索結果内 | 辛勤的园丁 | 要確認 | 要確認 | k013キット前提 | 74/35 | k013部品の入手性が鍵（詳細未調査） |

## 再調査: 単品ミニチュア（2026-07-15 夜・教室シーン不採用を受けて）

「Classroom Interior Miniature Scene（2750405）」が**ベース一体成形のジオラマで単品配置不可**と実物確認で判明したため、「全パーツが独立オブジェクト」であることを説明文・実写真・プレート構成で個別確認する条件で再調査した（9件確認）。

| カテゴリ | モデル | URL | 制作者 | ライセンス | Profile/時間 | 単品確認 | 👍/DL |
|---|---|---|---|---|---|---|---|
| 机椅子 | 椅子付き学校机（ドールハウス教室） | [2658444](https://makerworld.com/ja/models/2658444) | MonsieurPierre | MW-STD | 1P/1.6h | 高（実写真で机と椅子が別々に配置） | 116/26 |
| 机椅子 | 1:12 スクールチェア（単体） | [3034038](https://makerworld.com/ja/models/3034038) | MonsieurPierre | MW-STD | 1P/1.1h | 高 | 1/7 |
| 黒板 | ミニ教室黒板（自立型・ベース付き） | [2664912](https://makerworld.com/ja/models/2664912) | MonsieurPierre | MW-STD | 1P/2.8h | 高（「自立型として設計」明記） | 23/14 |
| 黒板 | イーゼル黒板（Little Tikes風） | [1695271](https://makerworld.com/ja/models/1695271) | Cliffrose | MW-STD | 4P/6.4h | 高 | 34/67 |
| 本棚 | 極小本棚＋極小本（1/12明記） | [997513](https://makerworld.com/ja/models/997513) | maker_snail | **CC BY-SA** | 2P/3h | 高（本は別STLで自由配置） | 135/68 |
| ロッカー | 1:12 学校ロッカー（8扉単体） | [3034053](https://makerworld.com/ja/models/3034053) | MonsieurPierre | MW-STD | 1P/3.8h | 高 | 3/10 |
| 小物 | ゴミ箱 1:12（Ø20×23mm） | [3045267](https://makerworld.com/ja/models/3045267) | box | MW-STD | 1P/16分 | 高 | 3/2 |
| 小物 | 1/12 壁掛け時計 | [1700968](https://makerworld.com/ja/models/1700968) | BlueBucket | MW-STD | **STLのみ**（要スライス） | 中〜高 | 137/39 |
| 小物 | ローポリ教室地球儀 | [2410472](https://makerworld.com/ja/models/2410472) | LowPolyFigures | **CC BY-NC** | 1P/1.1h | 高（要リサイズ） | 3/1 |
| 小物 | ミニバックパック（通学カバン） | [2661075](https://makerworld.com/ja/models/2661075) | MonsieurPierre | MW-STD | 1P/1.6h | 高 | 34/21 |
| 誕生日 | 1:12 バースデーケーキ | [3018883](https://makerworld.com/ja/models/3018883) | MonsieurPierre | MW-STD | 1P/38分 | 高 | 21/9 |
| 誕生日 | ~~学校用誕生日ケーキ~~ | [774555](https://makerworld.com/ja/models/774555) | PLFR | MW-STD | 4P/10.2h | **除外**（実物大レプリカでミニチュアではない） | 266/131 |

- MonsieurPierre統一シリーズ（机・椅子・黒板・ロッカー・バッグ・ケーキ）で世界観が揃う。表紙写真はドール演出のためスケールは本文記載値で判断
- ライセンス: 本棚のみCC BY-SA（最も自由）、地球儀はBY-NC、他はMW-STD → 非売品展示の本ブースは範囲内

## 結論（プロジェクトへの反映）

1. **撮影ブース小物**: 「教室ミニチュアシーン一式（42分）＋ビンテージ学校机椅子×2（2.6h）＋1/12校庭ベンチ（48分）＋日本の自動販売機（3.6h）」を採用（合計約7.7h・約150g）。MW-STDが大半＝**非売品展示はOK・再配布/販売は不可**・クレジット表示＋作者へ一報。
2. **観覧車**: 実機搭乗可能な既製品は無し → **新規設計（プランA）を本命**、espRyk電動版＋ミニスタックチャン搭乗を**プランB（フォールバック）**とする。切替判断は7/18のCAD進捗（[docs/ferris-wheel.md](../docs/ferris-wheel.md)）。
3. 反映先: `docs/photobooth.md`（小物選定リスト）/ `docs/ferris-wheel.md`（流用可否）/ `print/print-list.yaml`（booth-prop-* ジョブ）

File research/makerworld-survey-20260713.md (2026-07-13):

# MakerWorld スタックチャン関連モデル 全数調査（装飾パーツ量産向け）

- 調査日: 2026-07-13 / 方法: Chrome自動操作（検索4クエリ＋`tag: stackchan`タグ検索＋制作者プロフィール巡回）
- 目的: 装飾・着せ替えパーツの**量産候補**を洗い出す（AI Dev Day 2026 ブース用）
- 前回調査: [model-data.md](./model-data.md)（2026-07-03）— 本調査で「要確認」だったライセンスが複数判明
- 計 **33件**（装飾・着せ替え 18件 ＋ 本体シェル・スタンド・その他 15件）

## 検索手法メモ

| クエリ | 総ヒット | 関連件数 | 備考 |
|---|---|---|---|
| `tag: stackchan`（タグ検索）| 30 | 30 | **最も網羅的**。主データソース |
| `stackchan` | 1304 | 先頭〜17件 | 精度良好 |
| `stack-chan` | 1035 | 先頭8件 | 以降は無関係な"stackable"家具等 |
| `スタックチャン`（日本語）| 1309 | 0件 | 「スタック」の一般名詞マッチのみで**使えない** |
| `M5Stack robot` | 1277 | 0件 | Stack-chan固有パーツなし |
| プロフィール巡回 | — | +3件 | M5Stack公式のデコ3種はタグ未設定・検索非ヒット |

> タグ未設定モデルの補完: Case for AI-Robots（最多DL）、Stack-chan_sample_piece、Stepper Motor Visualizer はキーワード検索のみでヒット。

## 装飾・着せ替えパーツ（量産候補）— 18件

| モデル名 | URL | 制作者 | ライセンス | 👍/DL/印刷 | プロファイル | 備考 |
|---|---|---|---|---|---|---|
| M5StackChan-Cover-no-FrontPanel | [models/2817922](https://makerworld.com/en/models/2817922-m5stackchan-cover-no-frontpanel) | [ku-nel](https://makerworld.com/en/@user_93648059) | MW-STD | 33/47/32 | 有 | フロントパネルなしケース |
| M5StackChan-Cover-add-FrontPanel | [models/2817921](https://makerworld.com/en/models/2817921-m5stackchan-cover-add-frontpanel) | [ku-nel](https://makerworld.com/en/@user_93648059) | MW-STD | 17/18/9 | 有 | フロントパネル付きケース |
| stackchancover | [models/2839068](https://makerworld.com/en/models/2839068-stackchancover) | [user_2302219760](https://makerworld.com/en/@user_2302219760) | **CC0** | 3/4/2 | 有 | シンプルカバー。制約なしで自由度最大 |
| Stack-chan headphone | [models/2858793](https://makerworld.com/en/models/2858793-stack-chan-headphone) | [sskw](https://makerworld.com/en/@sskw) | BY-NC-SA | 20/21/13 | 有 | ヘッドホン型装飾 |
| StackChan simple headphone | [models/2792626](https://makerworld.com/en/models/2792626-stackchan-simple-headphone) | [user_3807793624](https://makerworld.com/en/@user_3807793624) | MW-STD | 6/10/8 | 有 | シンプル版ヘッドホン |
| StackChan Custom Hat Generator | [models/2772131](https://makerworld.com/en/models/2772131-stackchan-custom-hat-generator) | [beavers_hive](https://makerworld.com/en/@beavers_hive) | **BY** | 10/12/5 | 有 | 帽子カスタムジェネレーター。クレジットのみで利用しやすい |
| StackChan Brick Hat | [models/2855044](https://makerworld.com/en/models/2855044-stackchan-brick-hat) | [user_4023807793](https://makerworld.com/en/@user_4023807793) | BY-NC | 17/15/9 | 有 | レンガ風帽子 |
| Pharaoh decoration of StackChan | [models/2736962](https://makerworld.com/en/models/2736962-pharaoh-decoration-of-stackchan) | [M5Stack公式](https://makerworld.com/en/@M5Stack) | BY-SA | 6/18/1 | 有 | 公式。ファラオ風装飾 |
| American football decoration for StackChan | [models/2736961](https://makerworld.com/en/models/2736961-american-football-decoration-for-stackchan) | [M5Stack公式](https://makerworld.com/en/@M5Stack) | BY-SA | 3/21/1 | 無 | 公式。アメフトヘルメット。プロフィール巡回で発見 |
| Christmas hat decoration for StackChan | [models/2736960](https://makerworld.com/en/models/2736960-christmas-hat-decoration-for-stackchan) | [M5Stack公式](https://makerworld.com/en/@M5Stack) | BY-SA | 4/18/1 | 無 | 公式。サンタ帽。プロフィール巡回で発見 |
| Saint Seiya decoration for StackChan | [models/2736950](https://makerworld.com/en/models/2736950-saint-seiya-decoration-for-stackchan) | [M5Stack公式](https://makerworld.com/en/@M5Stack) | BY-SA | 3/25/5 | 有 | 公式だが**版権パロディ（聖闘士星矢）→展示非推奨** |
| スーパーサイヤスタックチャン | [models/2834877](https://makerworld.com/en/models/2834877-super-saiyan-stack-chan-m5stackchan-exclusive-acce) | [ku-nel](https://makerworld.com/en/@user_93648059) | BY-NC-SA | 4/14/1 | 無 | **版権パロディ（ドラゴンボール）→展示非推奨** |
| Eridian Xenolite StackChan body cover | [models/3013279](https://makerworld.com/en/models/3013279-eridian-xenolite-stackchan-body-cover) | [kenichi](https://makerworld.com/en/@kenichi) | BY-NC | 1/0/0 | 有 | ボディコスチューム系カバー |
| StackChan-ServoBodycover | [models/2904501](https://makerworld.com/en/models/2904501-stackchan-servobodycover) | [user_2302219760](https://makerworld.com/en/@user_2302219760) | BY-NC | 1/0/0 | 有 | サーボ部ボディカバー |
| StackChan(M5 ver.) neck hanging parts | [models/2870969](https://makerworld.com/en/models/2870969-stackchan-m5-ver-neck-hanging-parts) | [kenichi](https://makerworld.com/en/@kenichi) | **BY** | 2/0/1 | 有 | 首掛けパーツ。クレジットのみで利用しやすい |
| Stackchan Pendant Top | [models/3022476](https://makerworld.com/en/models/3022476-stackchan-pendant-top) | [user_2722792563](https://makerworld.com/en/@user_2722792563) | BY-NC-SA | 1/0/0 | 無 | ペンダントトップ |
| スタックチャンアクセサリーセット（頭部） | [models/979116](https://makerworld.com/en/models/979116-stackchan-accessory-set-stackchan-head-accessory-s) | [ku-nel](https://makerworld.com/en/@user_93648059) | BY-NC | 4/11/3 | 有 | 頭部アクセサリーセット |
| ミックチャンなりきりセット | [models/2777168](https://makerworld.com/en/models/2777168-miku-chan-role-play-set) | [sugamo](https://makerworld.com/en/@sugamo) | BY-NC | 4/12/0 | 無 | **版権パロディ（初音ミク）→展示非推奨** |

## 本体シェル・スタンド・その他 — 15件

| モデル名 | URL | 制作者 | ライセンス | 👍/DL/印刷 | プロファイル | 備考 |
|---|---|---|---|---|---|---|
| Case for AI-Robots (AI Stack-chan minimal) | [models/881711](https://makerworld.com/en/models/881711-case-for-ai-robots-ai-stack-chan-minimal) | [hako85](https://makerworld.com/en/@hako85) | BY-NC | **115/205/63** | 有 | **全調査中で最人気**の本体エンクロージャ。タグ未設定 |
| M5Stack Stand-chan | [models/996135](https://makerworld.com/en/models/996135-m5stack-stand-chan) | [Takao](https://makerworld.com/en/@mongonta) | BY-NC | 7/12/10 | 有 | スタンド基本形 |
| M5Stack Stand-chan big | [models/996444](https://makerworld.com/en/models/996444-m5stack-stand-chan-big) | [Takao](https://makerworld.com/en/@mongonta) | BY-NC | 21/25/11 | 有 | スタンド大型版 |
| M5Stack Stand Chan Stack size up to 35mm | [models/1349010](https://makerworld.com/en/models/1349010-m5stack-stand-chan-stack-size-up-to-35mm) | [Takao](https://makerworld.com/en/@mongonta) | BY-NC | 7/27/15 | 有 | 積み上げ35mm対応 |
| M5Stack-Stand for ModuleLLM | [models/1029159](https://makerworld.com/en/models/1029159-m5stack-stand-for-modulellm) | [Takao](https://makerworld.com/en/@mongonta) | BY-NC | 5/2/2 | 有 | ModuleLLM用スタンド |
| Cuteboy custom | [models/548757](https://makerworld.com/en/models/548757-cuteboy-custom) | [Takao](https://makerworld.com/en/@mongonta) | BY-NC-SA | 4/5/0 | 無 | 本体シェルのカスタム |
| 台座「Car-stom」for タカオ版ボディ | [models/2781106](https://makerworld.com/en/models/2781106-stack-chan-base-car-stom-custom-for-takao-version) | [Tanipochi](https://makerworld.com/en/@Tanipochi) | **MW-EX** | 10/11/0 | 有 | **最も制限的（MakerWorld限定）**。量産不向き |
| スタックチャンBOX | [models/2750877](https://makerworld.com/en/models/2750877-stackable-box) | [sugamo](https://makerworld.com/en/@sugamo) | **CC0** | 4/8/0 | 無 | 収納・展示ボックス |
| スタックチャン収納バケツ | [models/2834404](https://makerworld.com/en/models/2834404-stack-chan-storage-bucket) | [sugamo](https://makerworld.com/en/@sugamo) | **CC0** | 6/6/0 | 無 | 収納バケツ |
| M5 LLM Module Bottom Case | [models/1039760](https://makerworld.com/en/models/1039760-m5-llm-module-bottom-case) | [kennel.org](https://makerworld.com/en/@kennel.org) | BY-NC-SA | 7/15/5 | 有 | LLMモジュール用ケース |
| Stack-chan OpenCar with toio | [models/2922441](https://makerworld.com/en/models/2922441-stack-chan-opencar-with-toio) | [kenichi](https://makerworld.com/en/@kenichi) | BY-NC | 0/0/0 | 有 | toio連携の機構パーツ |
| Stack-chan Stepper Motor Visualizer | [models/685287](https://makerworld.com/en/models/685287-stack-chan-stepper-motor-visualizer) | [Hiroloquy](https://makerworld.com/en/@Hiroloquy) | BY-NC-SA | 1/0/0 | 無 | 可視化ギミック。タグ未設定 |
| Stack-chan_sample_piece | [models/1145027](https://makerworld.com/en/models/1145027-stack-chan_sample_piece) | [kennel.org](https://makerworld.com/en/@kennel.org) | BY-NC-SA | 6/4/2 | 有 | サンプル/テストピース。タグ未設定 |
| スタックさん 1/12スケールフィギュア | [models/2570902](https://makerworld.com/en/models/2570902-stack-san-1-12-scale-figure) | [kenichi](https://makerworld.com/en/@kenichi) | BY-NC | 2/2/1 | 有 | 派生フィギュア |
| キューボーイゼンマイ玩具用ダミーボディ | [models/76734](https://makerworld.com/en/models/76734-dummy-body-parts-for-cubeboy-wind-up-toy) | [kennel.org](https://makerworld.com/en/@kennel.org) | BY-NC-SA | 16/22/1 | 有 | 派生玩具のダミーボディ |

> ライセンス略号は [print-list.yaml](../print/print-list.yaml) と同一: BY / BY-SA / BY-NC / BY-NC-SA / CC0 / MW-STD(標準) / MW-EX(限定)

## 量産優先度（ライセンス×プロファイル有無）

| 優先度 | 条件 | 該当（装飾パーツ） |
|---|---|---|
| 🟢 即量産可 | CC0 | stackchancover |
| 🟢 クレジットのみ | BY | Custom Hat Generator ⭐ / neck hanging parts |
| 🟡 クレジット＋SA継承 | BY-SA（M5Stack公式） | ファラオ ⭐ / アメフト / クリスマス帽 |
| 🟠 非商用展示＋クレジット（許諾推奨） | BY-NC / BY-NC-SA | headphone ⭐ / Brick Hat ⭐ / 頭部アクセセット / ボディカバー2種 / ペンダント |
| 🟠 個人印刷可・展示は要確認 | MW-STD | ku-nelカバー2種 / simple headphone |
| 🔴 展示非推奨 | 版権パロディ | 聖闘士星矢 / スーパーサイヤ / ミクちゃん |

⭐ = プリントプロファイル有＋実績（DL/印刷数）ありの推し。

## print-list.yaml との突き合わせ

既存8ジョブ（hat-generator / headphone / accessory-set / brick-hat / pharaoh / super-saiyan / body-cover / sample-piece）は**すべて本調査でも確認済み**。本調査での新規追加候補:

- **stackchancover**（CC0・プロファイル有）— ライセンス面で最優先
- **neck hanging parts**（BY・プロファイル有）— 首掛け＝来場者が持ち歩ける
- **M5Stack公式デコ3種**（BY-SA）— アメフト/クリスマス帽はプロファイル無のため要スライス
- **StackChan simple headphone**（MW-STD・プロファイル有）— 展示可否の確認後
- ~~super-saiyan~~ は版権リスクの再評価を推奨（print-list に既存 → enabled:false 検討）

## 前回調査（model-data.md）からの更新

| モデル | 前回 | 今回判明 |
|---|---|---|
| M5StackChanカバー（ku-nel, 2817922）| 要確認 | **MW-STD**（個人印刷可・再配布不可）|
| スタックチャンBOX（sugamo, 2750877）| 要確認 | **CC0** |
| Car-stom（Tanipochi, 2781106）| 要確認 | **MW-EX**（MakerWorld限定・最も制限的）|

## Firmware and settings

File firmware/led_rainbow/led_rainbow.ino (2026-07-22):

// led_rainbow.ino — 観覧車リムLED（SK6812 1m/60LED x2本）レインボー制御
// Board: M5Stack AtomS3R (FQBN m5stack:esp32:m5stack_atoms3r)
//
// 配線（Grove PORT.A を使用 — 底面ヘッダはバッテリーベース用に空けておく）:
//   Grove 5V  -> 両テープの 5V
//   Grove GND -> 両テープの GND
//   Grove G2  -> 前リムテープ Din（矢印の始点側から入れる）
//   Grove G1  -> 後リムテープ Din
//
// 操作: 画面ボタン(G41)で輝度切替 50% -> 25% -> 100% -> OFF -> 50% ...
// 電流はFastLEDの電力キャップで最大900mAに制限（モバイルバッテリー安全圏）

#include <M5Unified.h>
#include <FastLED.h>

constexpr int PIN_FRONT = 2;   // Grove 白線側
constexpr int PIN_BACK  = 1;   // Grove 黄線側
constexpr int NUM_LED   = 60;  // 1m 60LED/m

CRGB ledsF[NUM_LED];
CRGB ledsB[NUM_LED];

const uint8_t kLevels[] = {128, 64, 255, 0};   // 50%, 25%, 100%, OFF
const char*   kLabels[] = {"50%", "25%", "100%", "OFF"};
int levelIdx = 0;

void drawStatus() {
  M5.Display.clear(TFT_BLACK);
  M5.Display.setTextDatum(middle_center);
  M5.Display.setTextSize(3);
  M5.Display.drawString(kLabels[levelIdx], M5.Display.width() / 2,
                        M5.Display.height() / 2);
}

void setup() {
  auto cfg = M5.config();
  M5.begin(cfg);
  FastLED.addLeds<SK6812, PIN_FRONT, GRB>(ledsF, NUM_LED);
  FastLED.addLeds<SK6812, PIN_BACK,  GRB>(ledsB, NUM_LED);
  FastLED.setMaxPowerInVoltsAndMilliamps(5, 900);  // 電流上限
  FastLED.setBrightness(kLevels[levelIdx]);
  drawStatus();
}

void loop() {
  M5.update();
  if (M5.BtnA.wasPressed()) {
    levelIdx = (levelIdx + 1) % 4;
    FastLED.setBrightness(kLevels[levelIdx]);
    drawStatus();
  }
  // リム一周ぶんの虹をゆっくり流す（前後リムは同位相）
  uint8_t base = millis() / 20;   // 約13秒で一周
  fill_rainbow(ledsF, NUM_LED, base, 255 / NUM_LED);
  for (int i = 0; i < NUM_LED; i++) ledsB[i] = ledsF[i];
  FastLED.show();
  delay(16);
}

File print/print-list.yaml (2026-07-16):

# =============================================================================
# スタックチャン イベントブース 印刷リスト（マニフェスト）
# -----------------------------------------------------------------------------
# このファイルが「何を・どのファイルで・何色・何個 印刷するか」の唯一の定義。
# auto_print.py がこれを読み、Bambu Lab X2D へ順番にジョブを送る。
# 実モデルファイル(3mf/STL)は print/files/ に置く（.gitignore 管理外）。
#   - MakerWorld の Print Profile（事前スライス済み .gcode.3mf）推奨＝そのまま印刷可
#   - download.py で不足ファイルの入手先を確認できる
#
# ライセンス略号: BY / BY-SA / BY-NC / BY-NC-SA / CC0 / MW-STD(標準) / MW-EX(限定)
#   「自作（本企画オリジナル）」= 本企画で新規設計するSTL（source: self-designed）
#   NC=非商用のみ(無料展示OK・物販不可) / SA=改変配布は同ライセンス継承
#   MW-STD/MW-EX=個人非商用の印刷可・データ再配布不可
# redistribute: リポジトリへのファイル同梱可否（true=CC0/BY/BY-SA/BY-NC-SA）
# =============================================================================

defaults:
  printer: X2D          # 送信先プリンター（secrets の BAMBU_* を使用）
  plate: 1              # Print Profile 内のプレート番号
  use_ams: true         # AMS を使う場合 true
  wait_between_sec: 30  # ジョブ完了後、次のジョブ開始までの待機（着脱・確認用）

# 印刷ジョブ（上から順に実行）。enabled:false はスキップ。
jobs:
  # ---- 着せ替えアクセサリー（MakerWorld・X2Dで直接印刷可） -------------------
  - key: hat-generator
    name: StackChan Custom Hat Generator（帽子）
    makerworld_id: "2772131"
    url: https://makerworld.com/ja/models/2772131
    license: BY
    author: beavers_hive
    redistribute: true
    file: files/hat-generator.gcode.3mf
    color: パステルピンク
    ams_mapping: [0]
    copies: 2
    enabled: true
    notes: CC BY（クレジットのみで自由）。テスト印刷の最優先候補。

  - key: headphone
    name: Stack-chan headphone（ヘッドホン）
    makerworld_id: "2858793"
    url: https://makerworld.com/ja/models/2858793
    license: BY-NC-SA
    author: sskw
    redistribute: true
    file: files/headphone.gcode.3mf
    color: マリンブルー
    ams_mapping: [1]
    copies: 2
    enabled: true

  - key: accessory-set
    name: スタックチャン アクセサリーセット（頭部）
    makerworld_id: "979116"
    url: https://makerworld.com/ja/models/979116
    license: BY-NC
    author: user_93648059
    redistribute: false      # BY-NC は非商用再配布可だが、安全側で false 既定
    file: files/accessory-set.gcode.3mf
    color: アイボリーホワイト
    ams_mapping: [0]
    copies: 1
    enabled: true

  - key: brick-hat
    name: StackChan Brick Hat（ブロック帽子）
    makerworld_id: "2855044"
    url: https://makerworld.com/ja/models/2855044
    license: BY-NC
    author: ""
    redistribute: false
    file: files/brick-hat.gcode.3mf
    color: マリンブルー
    ams_mapping: [1]
    copies: 1
    enabled: false

  - key: pharaoh
    name: Pharaoh decoration of StackChan（かぶりもの）
    makerworld_id: "2736962"
    url: https://makerworld.com/ja/models/2736962
    license: BY-SA
    author: ""
    redistribute: true
    file: files/pharaoh.gcode.3mf
    color: アーモンドイエロー
    ams_mapping: [2]
    copies: 1
    enabled: false

  - key: super-saiyan
    name: スーパーサイヤ スタックチャン（髪）
    makerworld_id: "2834877"
    url: https://makerworld.com/ja/models/2834877
    license: BY-NC-SA
    author: user_93648059
    redistribute: true
    file: files/super-saiyan.gcode.3mf
    color: アーモンドイエロー
    ams_mapping: [2]
    copies: 1
    enabled: false

  - key: body-cover
    name: Eridian Xenolite StackChan body cover（ボディカバー）
    makerworld_id: "3013279"
    url: https://makerworld.com/ja/models/3013279
    license: BY-NC
    author: ""
    redistribute: false
    file: files/body-cover.gcode.3mf
    color: 半透明ライトジェイド
    ams_mapping: [3]
    copies: 1
    enabled: false

  - key: sample-piece
    name: Stack-chan sample piece（顔/耳パーツ）
    makerworld_id: "1145027"
    url: https://makerworld.com/ja/models/1145027
    license: BY-NC-SA
    author: kennel.org(@kennel_org)
    redistribute: true
    file: files/sample-piece.gcode.3mf
    color: アイボリーホワイト
    ams_mapping: [0]
    copies: 1
    enabled: false

  # ---- 観覧車（自作STL・Issue #12）STL確定後に file を置いて enabled:true ----
  - key: ferris-rim-segment
    name: 観覧車 リム1/4円弧（スポーク一体）
    source: self-designed
    url: https://github.com/aieo-product/stackchanEventBooth/issues/12
    license: 自作（本企画オリジナル）
    author: 本企画
    redistribute: true
    file: files/ferris/rim-segment.gcode.3mf
    color: アイボリーホワイト
    ams_mapping: [0]
    copies: 8
    enabled: false

  - key: ferris-diffuser
    name: 観覧車 LEDディフューザー（円弧カバー）
    source: self-designed
    url: https://github.com/aieo-product/stackchanEventBooth/issues/12
    license: 自作（本企画オリジナル）
    author: 本企画
    redistribute: true
    file: files/ferris/diffuser.gcode.3mf
    color: PETG半透明クリア（7/17購入予定）
    ams_mapping: [3]
    copies: 8
    enabled: false
    notes: 無色クリアで虹色LEDの発色を優先。印刷前に乾燥必須（PETG）。

  - key: ferris-hub
    name: 観覧車 ハブ（シャフトフランジ）
    source: self-designed
    url: https://github.com/aieo-product/stackchanEventBooth/issues/12
    license: 自作（本企画オリジナル）
    author: 本企画
    redistribute: true
    file: files/ferris/hub.gcode.3mf
    color: アッシュグレー
    ams_mapping: [2]
    copies: 2
    enabled: false
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

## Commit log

2026-06-29 Add proposal site (VitePress/Cloudflare Pages), issues bodies, research skeleton
    - docs/: 関係者シェア用提案サイト（概要/アクセサリー/撮影ブース/必要スペース/運営）
    - 必要スペースのレイアウトSVG・アクセサリー/撮影ブースのコンセプトSVG
    - research/accessories.md: 許諾管理スケルトン
    Claude-Session: https://claude.ai/code/session_01RUxVZPCY51JRtCGcdSFjFa
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2026-06-29 Add 懸念点(ネットワーク) and アイディア(LLMデモ/案内) pages + menus, issues #9 #10
    - docs/concerns.md: ネットワーク接続問題(Wi-Fi)を懸念点メニューとして追加
    - docs/ideas.md: LLM Module低レイテンシー会話デモ/イベント案内・同フロア連携
    - nav/sidebar/トップに懸念点・アイディアの導線を追加(今後追記前提)
    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
2026-07-05 site: X2Dは保有済みのため経費はフィラメント代のみに修正
    - expenses.md: 本体を計上対象外（保有済み）にし、計上はフィラメント代
    ¥14,000 のみへ。その他資材は「参考（計上しない）」に降格
    - index/printing の文言・金額を保有済み前提に更新
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2026-07-09 fix(lt): 印刷CSSを16:9ページに最適化しPDF出力を整える
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2026-07-13 fix(lt): 表紙の登壇者表記を「大谷(@otani_ai_memo)/(株)SYNJAPAN」に修正
2026-07-13 fix(lt): 表紙の登壇者を2行表記にしハッシュタグを削除
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2026-07-15 fix(ferris-wheel): CJK括弧に隣接する強調が生テキスト表示になる箇所を修正 (#12)
2026-07-15 fix(docs): CJK括弧に隣接する強調(**)が生テキスト表示になる5箇所を<b>タグに修正
    markdown-itは「**…（…）**の直後にCJK文字」で強調判定に失敗する。
    ferris-wheel(2)/index(1)/accessories(2)/lt(1)を修正しビルドHTMLで**リーク0を確認。
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2026-07-15 fix(ferris-wheel): レビュー指摘対応—重量/時間の検算修正・12h枠内へ日程再配分・経費表記更新 (#12)
    - 部品合計 1,076g→1,176g / 46h→約50h、実質1.35kg→約1.47kg、総計3.4〜3.5kg（6kg以内は不変）
    - 印刷スケジュールを9日間・各日≦12hに再配分（7/17=11.4h, 7/18=10.6h）＋テスト印刷は本番部品流用と明記
    - index.md の経費説明を総額約¥22,900に更新
    - print-list: 凡例に自作を追記、モーターマウントはferris-baseに同梱と注記
    [print-list.yaml]
2026-07-15 fix(photobooth): レビュー指摘対応—観覧車スケジュールへのアンカー修正・小物時間合計を7.7hに訂正 (#13)
    - アンカーの中黒「・」はslugifyでハイフン化されないためリンクを実slugに一致させ、ビルドHTMLで href⇔id の一致を確認
    - 採用4点の印刷時間 7.4h→7.7h（research側も同期）
    - 任意行にprint-list登録状況（街灯のみ・ロッカー見送り）を明記
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2026-07-15 feat(cad): 観覧車・撮影ブースのOpenSCADパラメトリックCADとSTL生成基盤を追加 (#16)
    - params.scad: 全寸法・公差（tol/tol_dovetail/tol_snap）の一元定義
    - ferris 7種（リム1/4円弧・ディフューザー・ハブ・ゴンドラ・A型支柱上下・ベース・クランク+ダンパー）
    - booth 3ファイル5部品（床タイル・壁パネル3種・スタンド/クリップ/マーカー）
    - Makefile: openscad CLIで print/files/ に13 STL一括生成（STLはgit管理外）
    - check_dims.py: BBox検証（全パーツ250mm以内・設計書寸法一致=ALL OK）
    - 吊りフックは上開きU溝でサポートレス、ベースは自己相補ダブ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
    [base.scad, crank.scad, diffuser.scad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]
2026-07-15 fix(cad): リム円弧にゴンドラ吊り軸のΦ3.2貫通穴を追加（レビュー指摘・r140/セグメント中央45°） (#16)
    [params.scad, rim_segment.scad]
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2026-07-15 feat(cad): リム連結ダブテールの勘合テストピース(joint_test)を追加 (#16)
    2.2h×2のフル円弧を刷らずに両端継手だけ約15分で勘合確認できるクーポン。
    [joint_test.scad]
2026-07-15 fix(cad): joint-testを2ファイルに分割（各ピース原点配置・ベタ置き）—スライサーで浮く問題を解消 (#16)
    [joint_test.scad, joint_test_a.scad, joint_test_b.scad]
2026-07-15 fix(photobooth): 教室ミニチュアシーン(2750405)を不採用に—ベース一体成形で単品配置不可 (#13)
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2026-07-16 fix(expenses): グラディエント売切→ゴンドラは手持ちパステル4色に変更、追加フィラメントはPLAウッド¥3,042のみ計上 (#12, #13)
    - 7/16発注7本のうちイベント専用はPLAウッド オーカーイエローのみ経費計上（他は汎用在庫扱い）
    - 経費合計 約¥22,800 に更新
    - print-list/BOM/スケジュールのグラディエント記述を差し替え
    [print-list.yaml]
2026-07-16 fix(cad): テスト印刷失敗の修正—リム接地化・オープンゴンドラ再設計・接地チェック追加、ミニ観覧車アダプタ新規 (#18, #19)
    - rim_segment: spoke梁/joint_boss/ダブテールをz=0接地・全高化（スパゲッティ原因除去）
    - gondola: チェア型オープンに全面再設計（2段ポケット床: 外62×62汎用/内48.6×56.6=公式K151ベース48×56嵌合、背もたれ25mm・前面Dバー、吊りU溝）
    - diffuser/tower: 印刷姿勢で接地
    - check_dims.py: grounded列（最下面z=0±0.01）追加、全15パーツPASS
    - mini/adapter_gondola.scad: Artec木製観覧車の差替バケット2種（実測待ちプレースホルダ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
    [adapter_gondola.scad, diffuser.scad, gondola.scad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]
2026-07-16 chore(handover): テスト印刷失敗→修正(PR #20)・ミニ観覧車アダプタ・実測待ち事項を記録、テスト記録画像を追加
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2026-07-16 fix(cad): 公式K151 STLの仮想はめ込み検証でゴンドラ干渉3件を修正 (#18)
    - fit_check.scad 新規: 公式Base STL＋製品エンベロープ(54×70.5×61.5)をゴンドラに重ねる検証モデル
    - 数値検算で判明した干渉を修正: 支柱内側54→60(+3mm/側)・床奥行72→84(背面2.75mm/前面クリア)・前面バーを最前縁へ(+0.75mm)
    - ブリッジ下面67は頭上+3mmでOK。make check ALL OK（gondola 74×84×77）
    [fit_check.scad, gondola.scad, params.scad]
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2026-07-16 feat(cad): 嵌合テスト用の薄切りキット(fit-test)を追加—印刷時間を1/3に短縮 (#18)
    実モデルの水平スライス3種: rim z0-6(ダブテール/軸穴/ボス)・gondola床 z0-14(K151ポケット+レール)・ブリッジ z60-77(J溝)。
    make -C cad fit-test で生成。耐久性不要の形状確認専用。
    [fit_test_kit.scad]
2026-07-16 feat: ゴンドラ吊り軸を印刷化(Φ6・カット不要)＋ブラウザ3D組立シミュレーターを追加 (#18)
    - axle.scad: Φ6印刷軸×4+押込キャップ（フランジ頭・応力2.8MPa/FoS18）。Φ3丸棒・Eリング購入を不要化（経費約¥21,200に減額）
    - リム間80→90mmに是正（ゴンドラ奥行84基準）・リム穴Φ6.4/J溝Φ6.5に連動更新
    - assembly.scad+viewer-models: 組立座標配置の軽量STL14点をdocs/public/models/に出力
    - docs/public/viewer/: three.js製シミュレーター（パーツ別表示/透明度・分解ビュー・透視モード・自動回転・日本語UI）
    - navに3Dビューア追加・観覧車ページに導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
    [assembly.scad, axle.scad, axles.stl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]
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2026-07-16 feat(cad): 印刷軸をD断面・寝かせ印刷モデルに改良—積層方向を曲げ最強に (#18)
    - 軸を寝かせ+D-flat(0.4)でモデル化: 積層線が軸方向=曲げ強度最大・サポート/回転不要でそのまま印刷
    - 頭部を角型45°屋根形状に（寝かせ印刷対応）。荷重検算を動的係数2込みで更新(FoS13)
    - assembly.scadの軸配置を新姿勢に追従、viewer-models再生成
    [assembly.scad, axle.scad, axles.stl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]
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2026-07-17 fix(cad): J溝Φ6.5化に伴うブリッジ断面不足を修正—座り穴の底抜け(軸落下)と天井0.5mmを解消 (#18)
    pivot 70→73・bridge_top=pivot+hook+2.5(=82)。座り下壁2.75mm・天井2.5mm・K151頭上3mm維持。
    7/16夜出力のgondola.stl/fittest-bridge.stlは欠陥版のため印刷不可（再生成済み）。
    [gondola-1.stl, gondola-2.stl, gondola-3.stl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]
2026-07-19 fix(cad): ゴンドラv3—中央ブリッジ廃止・両腕フックタワー化で真上から搭乗可能に、軸公差を実測ベースに拡大 (#18)
    7/19テスト結果: ①ブリッジが全搭乗経路を塞ぎスタックチャンを載せられない→前後エッジのフックタワー(J溝×2)に変更し天面フルオープン
    ②印刷軸が穴に入らない→リム/円盤穴6.4→6.8・J溝6.5→6.7・キャップ穴5.8→6.0・軸先端に4mmテーパー追加・リグD穴/ブッシュも+0.4
    搭乗コリドー数値検算をヘッダに記録。make check ALL OK
    [axle.scad, axles.stl, gondola-1.stl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]
2026-07-19 chore(handover): 7/19テストNG→ゴンドラv3修正・公差拡大・再テスト待ちを記録
2026-07-19 feat(cad): 公式K151モデル(MIT)をfit_check・組立ビューアに搭乗させて反映 (#18)
    - cad/vendor/k151/: M5Stack公式Base/MainBody STL同梱（MIT・出典README付き）
    - k151.scad: 2部品を実寸合成（全高61.5・顔は前面バー側）
    - fit_check: エンベロープ→公式実モデルでの着座検証に更新
    - assembly/viewer: ゴンドラ1に搭乗した「スタックチャン（公式K151）」パーツ追加（manifest 15点目）
    [assembly.scad, fit_check.scad, k151.scad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]
2026-07-19 fix(cad): K151の足を含む接地形状を実STL解析で反映—ポケット公差を+0.5/側に拡大 (#18)
    - Base.stl解析: 足はベース一体・接地面はフラット48.0×56.0に完全内包（z=0平面）
    - ポケット嵌合 0.3→0.5/側（印刷収縮の実測教訓・ピンと同じジャム防止）→ 49.0×57.0
    - k151.scadにServoBody等を追加した忠実合成（全高61.5スペック準拠）、ビューアも更新
    [gondola-1.stl, gondola-2.stl, gondola-3.stl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]
2026-07-21 fix(cad): ゴンドラv4—ロボットの向きを開放面(+X)へ90°修正・吊り点80mm化、リグ支柱140mm+J溝軸受 (#18)
    7/21テスト結果対応:
    - 顔の前にフックタワー+バーが来て画面を塞ぐ→ポケット/背もたれ/バーを90°回転（タワーは左右へ・正面はラップバーのみ）
    - 頭上余裕6mm→13mm（pivot 73→80）
    - リグ支柱126→140mm・浅いリップ式軸受→J溝(鍵穴)式でシャフト脱落防止
    - 搭乗コリドー再検算（左右4mm/背面4.75mm/前面2.25mm）をヘッダに記録
    [gondola-1.stl, gondola-2.stl, gondola-3.stl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]
2026-07-21 fix(cad): 確実性優先—J溝を全廃し閉じた丸穴+軸貫通方式に（ゴンドラv5/リグv3）、軸受単体テストピース追加 (#18)
    - ゴンドラのタワー/リグのスタンドとも閉穴（ティアドロップ形状でサポートレス印刷）
    - 搭乗運用: キャップを外し軸を抜く→ゴンドラを取り出し→載せ替え→軸を通し直す
    - rig-bearing.stl: スタンドの軸受部だけの試験片（約10分印刷）— フル支柱を刷る前にΦ9穴と回転を検証可能
    [gondola-1.stl, gondola-2.stl, gondola-3.stl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]
2026-07-21 feat(cad): 8mm実シャフト用の接続部テストピース追加—ハブ芯とクランクボス (#18)
    fittest-hubcore: ハブ中心部（Φ8.2ボア+イモネジボス2）/ fittest-crankboss: クランクのボス+アーム根元。
    各10-15分でΦ8金属シャフトとの嵌合・イモネジ固定を検証可能。
    [fit_test_kit.scad]
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2026-07-21 fix(photowall): 抽出をmedia ID+format形式に変更—Chrome拡張DLPのクエリ文字列ブロック回避、リハーサル実データ反映
    - extract_tweets.js: 画像URLを返すと [BLOCKED: Cookie/query string data] になるため {mid,fmt} に分解
    - merge_posts.py: media形式からURL再構築してDL（旧images形式も許容）
    - リハーサル成功: 実Xポスト(@otani_ai_memo 投稿テスト)を検索→抽出→DL→デプロイまで確認
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2026-07-22 feat(cad): ゴンドラv6—吊り点+20mm(80→100)で装飾ロボの頭上クリアランス13→33mm、支柱300mm化で地上クリアランス38mm維持 (#18)
    - gon_pivot_z 80→100: 帽子等の装飾品を付けたK151が軸下を通るように
    - tower_total_h 280→300: 最下点のゴンドラ底〜ベース板上面38mmを従来同等に維持（分割印刷は上165/下168で≤170制限内）
    - rig_bush_z 140→160: 揺れテストリグ再実行時用（既存140リグは床クリアランス不足になる旨コメント）
    - make check ALL OK（接地・寸法・250mm制約）
    [axles.stl, crank.stl, diffusers.stl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]
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2026-07-22 feat(cad): 組立継手の事前フィットテスト6種追加＋ハブスポーク穴をセルフタップ化 (#18)
    - fittest-towerfoot/baseslot: 支柱足タブ×ベーススロット（±48スペーシング込み）
    - fittest-splicelower/spliceupper: 支柱上下の角ダボ＋M3継手
    - fittest-spokehub/spokepad: スポークパッド×ハブのM3ボルトサークル（45°ペア）
    - hub: スポーク穴 Φ3.4→Φ2.5下穴に変更（貫通だとM3×50が必要なためM3×25セルフタップ式へ。長ネジがあればΦ3.5に拡張drill可とコメント）
    - make check ALL OK（全ピース接地）
    [fit_test_kit.scad, hub.scad]
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2026-07-22 fix(cad): M3セルフタップ下穴を2.5→2.9に拡大—印刷収縮でM3が食い付かない実測を反映 (#18)
    [params.scad]
2026-07-22 fix(cad): 7/13注文(ベアリング・ネジ・インサート)未着に対応—インサート前提穴を全てM3セルフタップΦ2.9化 (#18)
    - rim継手ボス(0°側)・ハブ/クランクのイモネジ穴: Φ4.0(インサート圧入)→Φ2.9(直タップ)
    - 印刷済みリム1号の旧Φ4.0穴はM4ネジで代替(コメント記載)
    - 608ZZ・ネジ類は明日千石で現物調達(HANDOVER記載の保険ルート)
    [params.scad, rim_segment.scad]
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2026-07-22 feat(booth): LT会風ジオラマパーツ追加—スクリーンパネル(紙スライド上差し替え式)・演台・ステージ台 (#16)
    - wall_panel に variant=screen 追加: 前枠裏に1.2mm紙チャンネル(上端開放)でスライド交換可、下端にホワイトボード風ペン置きリブ
    - lt_podium.scad: 演台64×35×42(傾斜天板・前面ロゴ紙44×26差し込み凹み・中実=ブリッジ回避)/ステージ台150×100×8(前縁面取り)
    - 全て単色・平置き・サポート不要の高速印刷前提。既存スタンド/クリップ/床タイルと互換
    [lt_podium.scad, params.scad, wall_panel.scad]
2026-07-23 feat(booth): LT会場ジオラマの3D組立シミュレーター追加—/viewer-booth/ (#16)
    - cad/booth/assembly.scad: 床2×2・ステージ・演台・K151登壇者・スクリーン・窓パネル・スタンド×3を実組立配置
    - make viewer-models-booth で配置済みSTL7点+manifest出力、ビューアは観覧車版を流用
    - photobooth.md にLT会場への方針転換を注記、index.md にリンク追加
    [assembly.scad, floor.stl, podium.stl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]
2026-07-23 feat(booth): 壁を床タイル直差し込み式に再設計—スタンド廃止・スクリーン壁/窓壁/通常壁の3種構成 (#16)
    - floor_tile に variant=wall 追加: +Y縁にソケットカーブ(h13)、壁タブ20×5×2箇所を差し込み係合12mm
    - wall_panel に variant=plain 追加(横目地2本の通常壁)
    - assembly/ビューア更新: ソケットタイル3枚(背面2+左側面1)に壁3種を直差し、K151向きを+Xネイティブ基準で修正
    - make check ALL OK
    [assembly.scad, floor.stl, floor_tile.scad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]
2026-07-23 feat(booth): スクリーン壁をL/R分割連結式に—300mm幅の大型スクリーン化、通常壁は右側面へ (#16)
    - wall_panel に screen-l/screen-r 追加: シーム側は枠なし・半厚ダブテール3箇所(z0-2.4)で連結、紙チャンネル(z2.6-3.8)はシーム貫通で連続→A4横1枚から切る288×117の大判紙が2枚を跨いで差さる
    - 床は4枚全てソケットタイル化(背面2=スクリーンL/R・左=窓壁・右=通常壁)
    - ビューア/manifest更新、make check ALL OK
    [assembly.scad, floor.stl, plain-wall.stl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]
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2026-07-23 fix(booth): LTバナーを公式ルックのスタックチャンで再生成—公式参考写真をGPT-image-2に参照させ腕/ハンドル無しのキューブ形状に (#16)
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2026-07-23 chore(handover): 前日引き継ぎ全面更新—印刷キュー・千石調達・LED・LT会ジオラマ・スライド作業の分担を集約
    - HANDOVER.md: 7/23昼時点の全状況(残り10h印刷キュー/Φ2.9タップの扱い/フォトウォール運用/スライド修正の注意点)
    - ferris-wheel.md: LED系をAtomS3R実装済みに更新(他セッション作業分)
    - akiba-backup: WAGO型番・売場・価格確定版(他セッション作業分)
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2026-07-23 feat(booth): 全周壁構成＋シミュレーターにバナー実画像表示 (#16)
    - 床4枚構成: コーナーソケットタイル×2(2辺カーブ・回転で左右兼用)＋ソケットタイル×2。壁6枚: スクリーンL/R(背面)・窓壁×2(左)・通常壁×2(右)・前面開放
    - 0.6ノズル前提: 差し込みクリアランスを+0.8→+1.2(sock_play)に拡大
    - viewer-booth: スクリーン紙位置にlt-banner.pngをテクスチャ表示、紙サイズ表記更新
    - photobooth ページにシミュレーター/印刷PDFのボタンリンクとバナー画像を掲載
    [assembly.scad, floor.stl, floor_tile.scad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]
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2026-07-23 feat(cad): base外注対応—スロット公差+0.8化・クランクジャーナルΦ8.8化・ステージ6mm薄肉化、base応援印刷キット配布 (#18)
    - 撮影ブースは自宅印刷に方針変更(0.6ノズル+ウッド床+白壁で写真映え優先)→booth-kit zipは取り下げ
    - 観覧車base×2を応援印刷へ: スロットは蝶ネジ固定前提でゆる公差化、機差を吸収
    - dl/base-kit-20260723.zip(README同梱)
    [params.scad]
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2026-07-23 docs(dl): 応援印刷キットREADME修正—支柱は各1個(1本分は自宅印刷済み)
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2026-07-23 feat(cad): ベースを足元パッド(base-mini 140×90×15)に縮小—印刷時間1/3化・クランクジャーナル廃止 (#18)
    - スロット/サムスクリュー穴レイアウトは現行baseと同一(±48・ゆる公差)
    - シャフトは支柱2本のΦ9穴で保持、手回しクランクは片持ちでOK
    - wheel-kit v3差し替え(同URL)・HANDOVER反映
    [base_mini.scad]
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2026-07-23 fix(cad): クランクv2—印刷グリップポスト折損対応、予備8mm鋼棒を挿すΦ8.4ソケットボス(Φ18×30)+イモネジ固定に変更 (#18)
    - グリップポスト/Eリング溝/印刷グリップを廃止(グリップはΦ8.2穴のテストピース流用)
    - ダンパーは同プレートに残置(任意部品)
    [crank.scad]
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2026-07-23 feat(booth): ハリボテ壁v2—ミニ脚ブロック(60×40×14・10分/個)で壁自立、8h以内キットに再構成 (#16)
    - wall_foot.scad: 差すだけの1スロット脚。スタンド+クリップ複合プレート(40分)を置換
    - キット構成: 壁6+脚12=約7.5h、最低構成=スクリーンL/R+脚4
    - 床タイルは廃止(必要なら当日机上にplainタイルを敷く選択のみ残置)
    [wall_foot.scad]
2026-07-23 feat(slides): 細部修正—ししかわさんアイコン/誕生会6·24+Jimmy社長/CMサムネ言及/タイムライン下部/物理左カード/ケーブル用途明確化/MeloTTS表現+rtf·出典削除/母艦連携の絵スライド新設+図をAIEO前へ移動/AIEOに完成予想図2枚+QR
    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
2026-07-24 fix(slides): 写真館告知画像—観覧車搭乗スタックチャンの画面を文字化けから表情6パターンに差し替え
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2026-07-24 fix(slides): 写真館告知バッジ文言に「写真を」を追加
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2026-07-24 feat(slides): ③UtaさんパートをStack-Chan Minimal公式スライド5枚(PDF提供)に差替え・3P写真を正しい縦向きに修正
    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

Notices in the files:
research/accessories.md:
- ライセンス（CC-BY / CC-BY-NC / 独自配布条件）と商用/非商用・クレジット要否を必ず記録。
